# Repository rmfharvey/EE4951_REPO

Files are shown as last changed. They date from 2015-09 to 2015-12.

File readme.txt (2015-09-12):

EE4951 Repository Readme

Contact Info:

Andre Bounnakhom
boun0038@umn.edu

Ross Harvey	
harve321@umn.edu	
(515) 210-5953

Diego Martinez
mart1951@umn.edu

Alpha Mbennah
mbenn001@umn.edu

James Redinger
redi0069@umn.edu

Ryan Thompson
thom4192@umn.edu

Kia Bazargan
kia@umn.edu

Greg Nash
greg.nash@nimbelink.com

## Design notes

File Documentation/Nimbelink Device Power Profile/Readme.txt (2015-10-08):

Nimbelink Device is powered from 12V input.
A buck converter (TPS54229E) transforms the voltage from 12V to 4V at 60% to 90% efficiency.

All current shunt (voltage) measurements are given as voltages across a 0.1ohm resistor (1% tolerance) on the 4V rail.
Voltage measurements were given at the 4V rail.

These measurements were taken as the Nimbelink device was running the Skywire_Demo program in which it periodically
transmits data from the device over the internet to an online display on my laptop. I attached a text file which contains
the terminal window information from the Nimbelink device and I attached a screenshot from the online display.

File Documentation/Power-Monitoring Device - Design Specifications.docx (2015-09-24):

EE4951W Design Specifications

Objective: To develop an intelligent monitor to analyze the power consumption of a battery powered device by simultaneously measuring voltage and current supplied to the device under test (DUT). A microprocessor will obtain the analog voltage across the DUT along with its current consumption and will convert them into two streams of digital data that will be used to calculate the power consumption of the DUT. Voltage and current readings, as well as power calculations, will be logged to an onboard SD card in order to provide analysis of past measurements. The device will provide minimum, maximum, and average voltage and current readings along with power calculations that will be shown on an LCD for real-time observations.

Primary Constraints

1. Input voltage range: 3.3 – 24V

2. Maximum power consumption: 1W

3. The system should provide 5 significant figures for current measurements in the range of 10µA to 1A and voltages in the range of 3.5 to 24V

4. The device should be able to be powered parasitically from the DUT

5. The device should log data to an SD card in csv format

6. The microcontroller should have USB accessibility for debugging and performing firmware upgrades

7. The device should be able to respond to push-button commands to start or stop statistical calculations.

Secondary Constraints

1. The system should be able monitor its own power consumption by means of an additional analog circuit that will provide measurements for current and voltage that the microprocessor will use in order to provide the consumption of the system by the command of a switch

2. Output real-time data over USB

3. Microprocessor and circuitry for analog voltage and current measurements should be able to operate from a 5-Volt source, such as the terminal from a USB cable connection

4. The system should be able to withstand accidental reversed power supply connections

5. The microcontroller should enter a minimum-consumption state once inactivity reaches a determined length of time (sleep mode)

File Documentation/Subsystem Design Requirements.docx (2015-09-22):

Subsystem Design Requirements/Constraints

EE4951W

9-21-15

Power

James/Andre

1. Input Voltage Range: 0-24v
2. Output: 3–3.6v
3. Switch to USB power when available (preferably automatically)
4. Filter noise from 3.3v rail
5. Keep noise out of VBAT rail

Current Measurement

Ryan/Ross

1. Measurement range: 500nA – 5A
2. Quick enough to capture spikes (>80kS/s)
3. VBurden < 50mV
4. Accurate to 4 digits

Voltage Measurement

Alpha/Andre

1. Overvoltage protection at ADC inputs
2. Prevent loading of voltage divider
3. Resolution of 0.5%
4. Quick enough to capture spikes (>80kS/s)

SD Card

Diego/James

1. Figure out size needed
2. Preferably MicroSD
3. Figure out how and what we need to write to card and how long of a period
4. Communication protocol (preferably SPI)
5. How to write csv file to SD card
6. File system?

LCD Display

Diego/Ryan

1. Board v. chassis mount
2. Hardware driver IC
3. Communication protocol
4. What/how to display
5. Power consumption
6. Sleep mode

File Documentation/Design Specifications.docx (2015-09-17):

EE4951W Design Specifications

9-15-15

Primary Constraints

1. Input voltage range: 3.3 – 24v
2. Maximum power consumption: 1W
3. The system should feature multiple current measurement ranges.
4. The device should be able to be powered parasitically from the device-under-test. (DUT)
5. The device should log data to an SD card in csv format.
6. The microcontroller will have JTAG debug and programming capabilities
7. The device will be able to service interrupt requests triggered by a button press or an external

signal. This interrupt will start or stop statistical calculations.

Secondary Constraints

1. The system should monitor the power consumption of itself.
2. Output real-time data over USB.
3. Allow for system to be powered from USB.
4. The system should be protected against reverse voltages.
5. The microcontroller should go to sleep while idle to minimize power consumption.

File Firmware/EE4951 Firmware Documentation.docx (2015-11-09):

EE4951 Firmware Documentation

Ross Harvey

11-7-2015

1. Communications Busses

SPI0

- SD Card
- 10MHz

SPI1

- OLED Display
- 2MHz

UART1

- USB interface (FT232RQ)
- Baudrate: 115200 bps
- Width: 8-bit
- Parity: None

2. Start-up Options

Four GPI bits (OPT<3:0>) are included to run the device in different modes. These four bits will only be read immediately after the MCU is reset or powered on.

OPT<3:0> | Mode | Description
0000 | Normal | -
0001 | USB Output | Normal mode with unidirectional USB
0010 | Hardware Debug | Normal mode with bidirectional USB
0011
0100
0101
0110
0111
1000
1001
1010
1011
1100
1101
1110
1111

Table 1: OPT<3:0> assignments

3. USB-UART Communication (Unidirectional)

During normal operation, if USB unidirectional mode is enabled with the OPT bits, the MCU will output ADC readings and current status data asynchronously. It will be necessary for the Python script to read these packets from the USB buffer and parse them to obtain readings. The packet structure is given below.

TYPE<7:0> | Data Type | VALUE<15:0>
0x00 | DUT Voltage | 16-bit raw values. See scaling factors
0x01 | DUT Current
0x02 | Self 3.3v Voltage
0x03 | Self 3.3v Current
0x04 | Self 5v Voltage
0x05 | Self 5v Current
0x06 | Status Register | See fig xxxxxxx
0x07 | DUT Current Average
0x08 | DUT Voltage Average
0x09 | Stats Period | Elapsed time for stats (in seconds)

3.1 DUT Voltage

TYPE<7:0> = 0x00

VALUE<15:0> = Unsigned 16-bit value (Scaled)

To recover VBAT, use V_(BAT) =VALUE(V_(REF))/(2^16)(1+(R_22)/(R_24))=(VALUE)/2621.44 (REV A)

RNG<1:0> = not used

3.2 DUT Current

TYPE<7:0> = 0x01

VALUE<15:0> = Unsigned 16-bit value (Scaled)

To recover IDUT, use I_(DUT) =VALUE(V_(REF))/(2^16)1/(A_V •R_(Sense))=VALUE•SCALE (REV A)

RNG<1:0> = Determines which range is currently active. Affects

scaling factor and IDUT recovery.

RNG<1:0> | Range | SCALE
00 | DUT_RANGE0 | 1.831055x10⁻⁴
01 | DUT_RANGE1 | 1.831055x10⁻⁶
10 | DUT_RANGE2 | 1.831055x10⁻⁸
11 | DUT_RANGE3 | 1.831055x10⁻⁹

3.3 Self 3.3v Voltage

TYPE<7:0> = 0x02

VALUE<15:0> = Unsigned 16-bit value (Scaled)

To recover V3.3v, use V_(3.3v) =VALUE(V_(REF))/(2^16)(1+(R_72)/(R_74))=(VALUE)/9709.037 (REV A)

RNG<1:0> = not used

3.4 Self 3.3v Current

TYPE<7:0> = 0x03

VALUE<15:0> = Unsigned 16-bit value (Scaled)

To recover I3.3v, use I_(3.3v) =VALUE(V_(REF))/(2^16)1/(A_V •R_(Sense))=(VALUE)/15073.28 (REV A)

RNG<1:0> = not used

3.5 Self 5v Voltage

TYPE<7:0> = 0x04

VALUE<15:0> = Unsigned 16-bit value (Scaled)

To recover V5v, use V_(5v) =VALUE(V_(REF))/(2^16)(1+(R_48)/(R_44))=(VALUE)/9709.037 (REV A)

RNG<1:0> = not used

3.5 Self 5v Current

TYPE<7:0> = 0x05

VALUE<15:0> = Unsigned 16-bit value (Scaled)

To recover I5v, use I_(5v) =VALUE(V_(REF))/(2^16)1/(A_V •R_(Sense))= (VALUE)/15073.28 (REV A)

RNG<1:0> = not used

3.5 Status Register

TYPE<7:0> = 0x06

VALUE<15:0>

Bits | Function | Notes
VALUE<15:12> | OPT<3:0> | Startup Options
VALUE<11:10> | DUT Current Range | Range 0-3
VALUE<9> | POWER_FAIL_IRQ | Power OK (Active High)
VALUE<8> | STATS_IRQ | Stats Start/END Button(Active Low)
VALUE<7> | SD_DETECT | SD Card Present(Active Low)
VALUE<6> | SD_CS | SD Chip Select (Active Low)
VALUE<5> | DISP_RES | Display Reset (Active Low)
VALUE<4> | DISP_CS | Display Chip Select (Active Low)
VALUE<3> | DISP_DC | Display Data/Command (Data High)
VALUE<2> | Stats Running | High if collecting stats data
VALUE<1:0> | not used | not used

3.6 DUT Current Average

May be implemented later. More to come…

3.6 DUT Voltage Average

May be implemented later. More to come…

3.6 Stats Period

May be implemented later. More to come…

4. USB-UART Communication (Bidirectional)

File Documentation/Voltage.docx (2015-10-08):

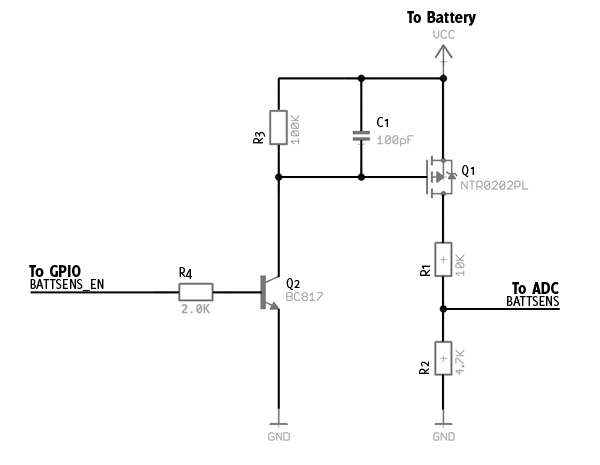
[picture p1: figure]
User Controllable Voltage Divider Circuit

Pros:
Helps preserve battery life (Control of voltage divider)
Relatively good price
Cons:
Potentially not needing GPIO

http://www.microbuilder.eu/Tutorials/Fundamentals/MeasuringBatteryVoltage.aspx

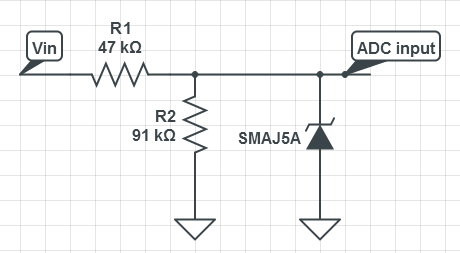
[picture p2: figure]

Instead of Zener diode, use Vishay QSBT40 TVS Diode Array(24V outputs)
Resistors for scaling, voltage protection, linear regulator

*Shunt cap for non-voltage divider
*Linear reg/variable reg: current rush, power to stop it
*R1=98.8k, R2=26k
*Zener Diode
*P=0.0279W

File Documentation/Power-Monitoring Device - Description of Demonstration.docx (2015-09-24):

EE4951W – Battery Power Monitor

Demonstration Description

A system comprised of a laptop, cellular modem, and a load-box will be used to demonstrate the functionality of the battery power monitor (BPM). The BPM will monitor the voltage and current of the cellular modem during transmission and log all data to an on-board SD card. In addition to data logging, minimum, maximum, and average values of the power consumption will be displayed on an attached LCD display. These statistical calculations can be reset via a push-button. Real-time sensor data will be sent over USB to the laptop and displayed on screen. In addition to monitoring the cellular modem, the general nature of the BPM will be demonstrated by using a load box to simulate a variety of loads.

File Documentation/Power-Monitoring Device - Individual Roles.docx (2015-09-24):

EE4951W – Power-Monitoring Device

Individual Roles

Power Supply: James

Voltage Measurement: Alpha

Current Measurement: Ryan

LCD: Diego

PCB Layout and Schematic Capture: Ross

Firmware: Ross and Diego

Self-Power Monitor: Andre

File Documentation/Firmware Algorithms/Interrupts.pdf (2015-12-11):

12/10/2015 | draw.io

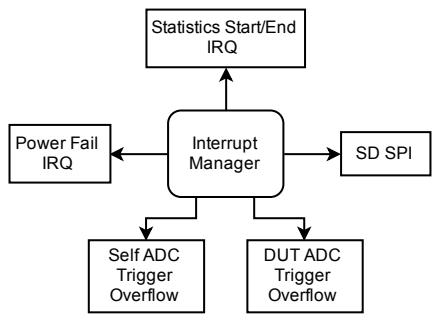
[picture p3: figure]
Interrupt Manager; DUT ADC Trigger Overflow; Statistics Start/End IRQ; Power Fail IRQ; SD SPI; Self ADC Trigger Overflow

chromeextension://pebppomjfocnoigkeepgbmcifnnlndla/index.html | 1/1

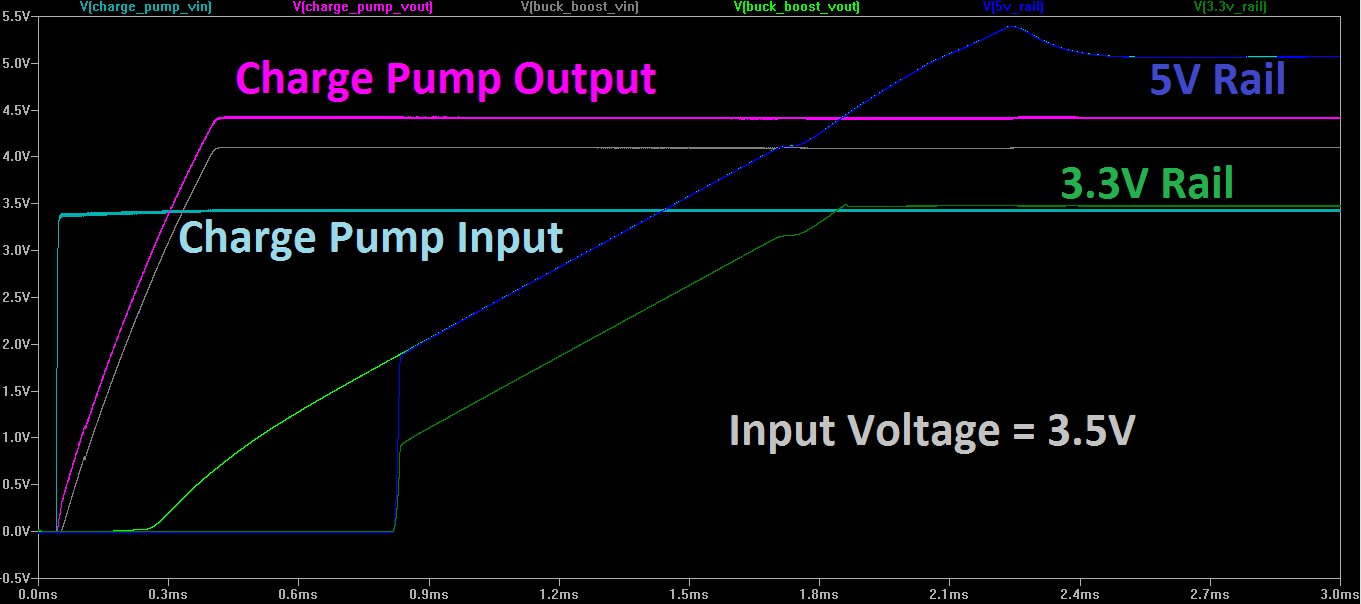
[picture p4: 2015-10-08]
Simulation/Power Subsystem/Buck_Boost Design/3.5V Input Power Subsystem 3ms.PNG

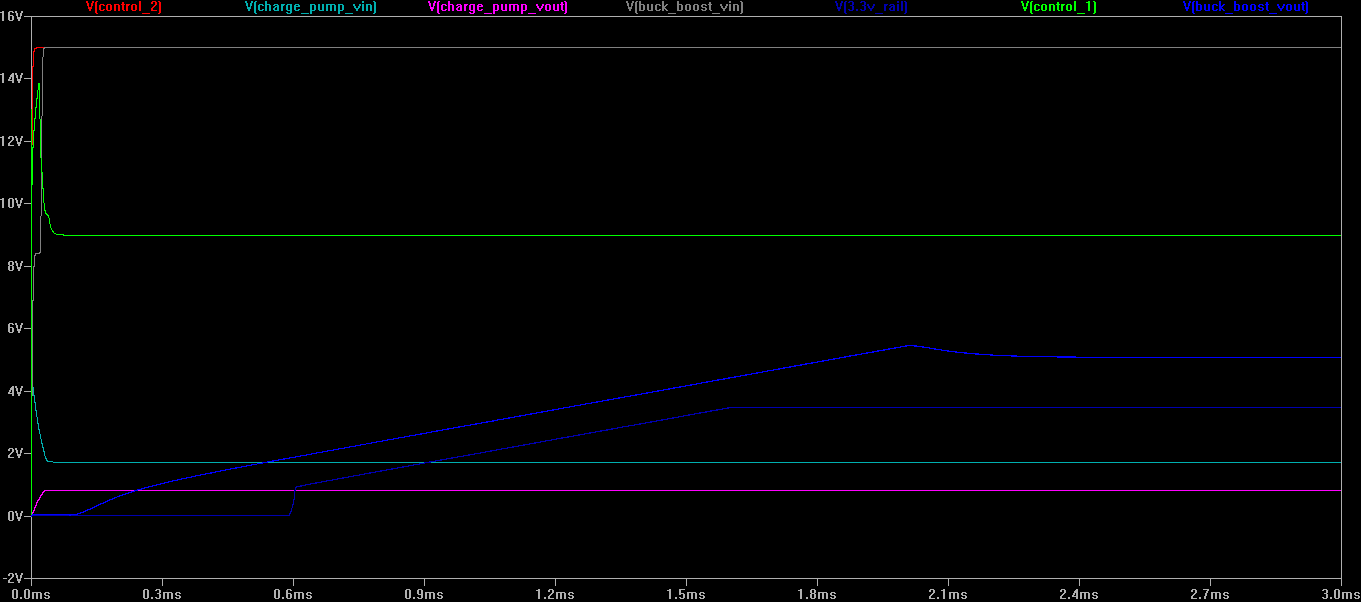
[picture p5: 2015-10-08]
Simulation/Power Subsystem/Buck_Boost Design/12V Input Power Subsystem 3ms 2.PNG

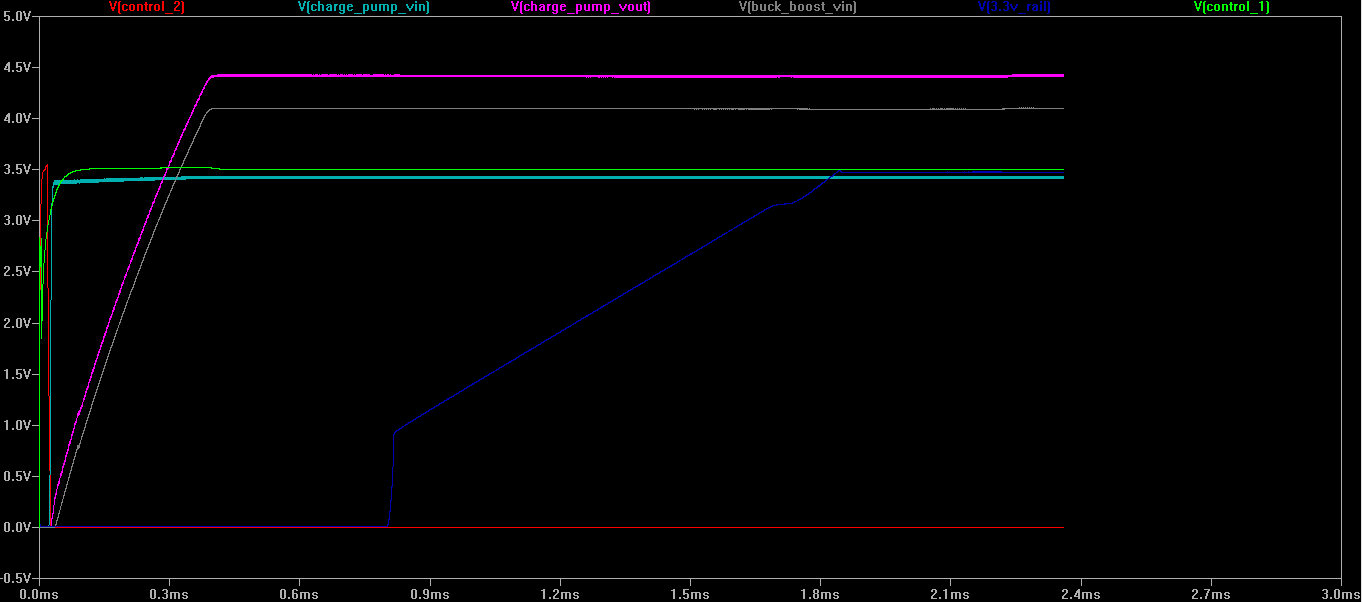
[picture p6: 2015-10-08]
Simulation/Power Subsystem/Buck_Boost Design/3.5V Input Power Subsystem 3ms 2.PNG

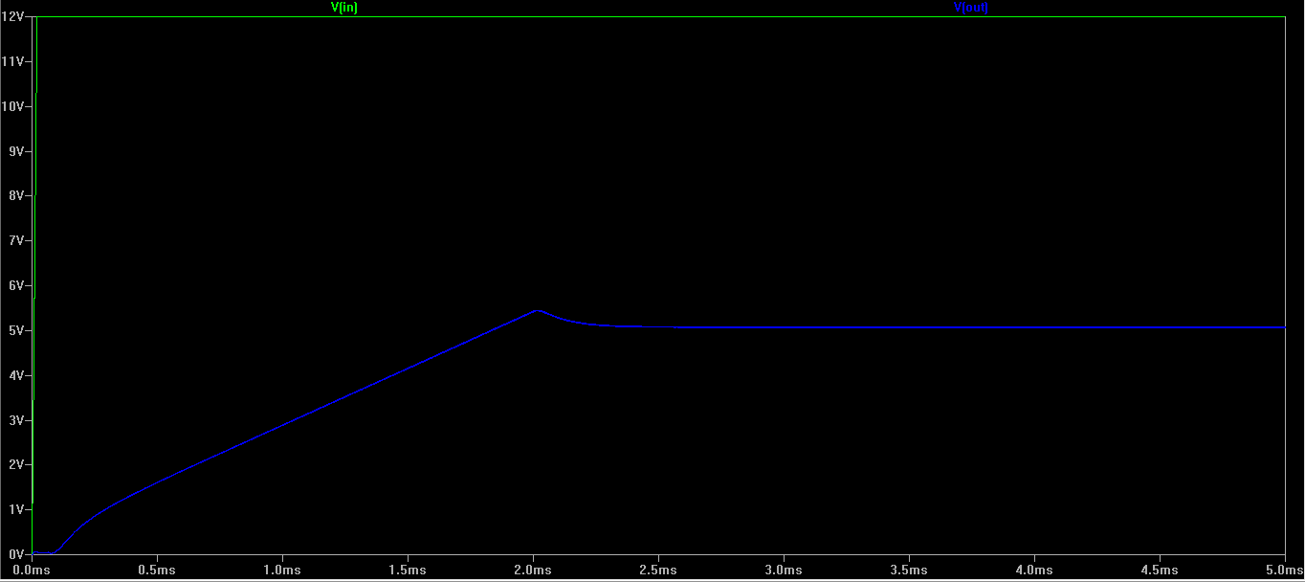
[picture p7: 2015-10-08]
Simulation/Power Subsystem/Buck_Boost Design/12V Input LTC3111.PNG

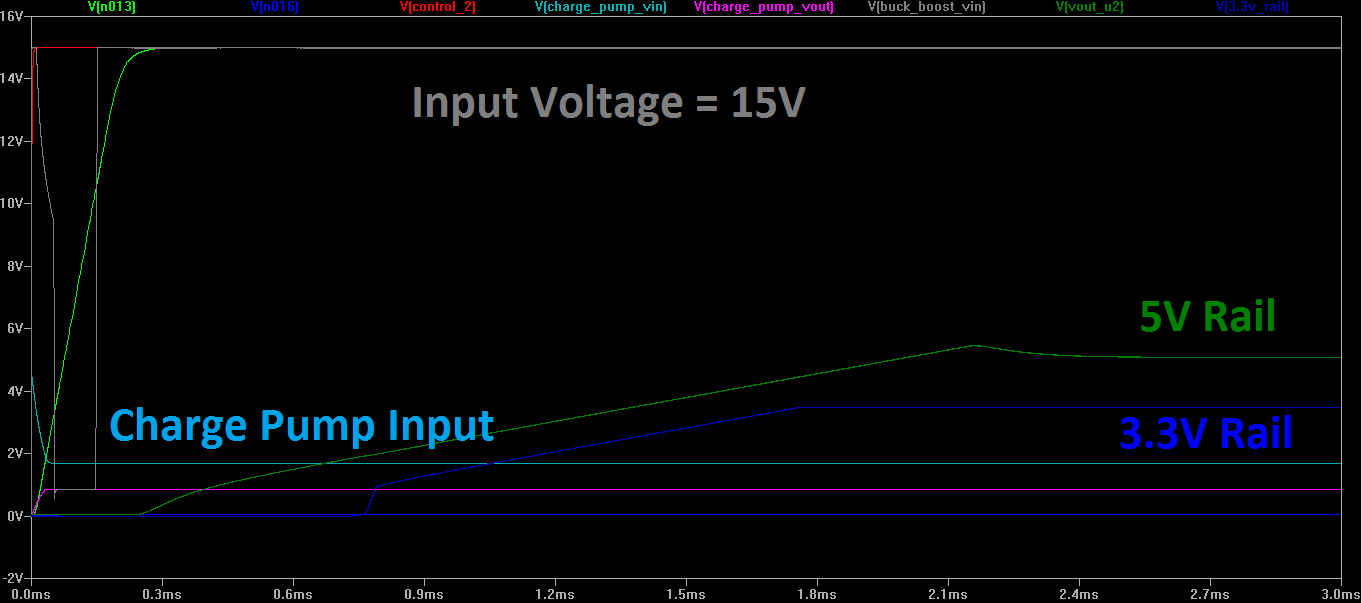
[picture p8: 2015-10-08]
Simulation/Power Subsystem/Buck_Boost Design/12V Input Power Subsystem 3ms.PNG

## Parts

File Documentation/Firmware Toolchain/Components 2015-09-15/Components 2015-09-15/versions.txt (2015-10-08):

Part 1 of 2:
Package from component(s):
- 24AA_EEPROM version 01.032
- 74HC164 version 01.031
- 74HC595 version 01.022
- App_SMAC_Hello version 01.085
- AT25HP512 version 01.038
- BitIO_to_PCA9554 version 01.018
- Bluetooth_EGBT version 01.051
- BootLoaderDisk version 01.018
- BootLoaderUSB version 01.020
- ChLCD version 01.164
- CriticalSection version 01.006
- CTouchScanner version 01.021
- CTouchSensor version 01.032
- DCF77 version 01.060
- DS18B20 version 01.001
- FAT_FileSystem version 01.168
- FatFsMem_USB_MSD version 01.024
- FatFsMemSDHC version 01.037
- FontDisplay version 01.195
- FreeRTOS version 01.435
- FreeRTOS_Tasks version 01.008
- FreeRTOSTrace version 01.003
- FSL_USB_CDC_Device version 01.050
- FSL_USB_CDC_Host version 01.005
- FSL_USB_HID_Keyboard_Device version 01.061
- FSL_USB_HID_Mouse_Device version 01.076
- FSL_USB_MSD_Host version 01.024
- FSL_USB_Stack version 01.036
- FXOS8700CQ version 01.028
- GDisplay version 01.190
- GenericBitIO version 01.065
- GenericI2C version 01.023
- GenericKBI version 01.025
- GenericSPI version 01.029
- GenericSWI2C version 01.007
- GenericSWSPI version 01.024
- GenericTimeDate version 01.027
- GFont version 01.123
- HardFault version 01.008
- I2CSpy version 01.009
- KentChLCD version 01.111
- Key version 01.109
- KinetisSDK version 01.001
- KinetisTools version 01.025
- LCDHTA version 01.022
- LED version 01.065
- LEDbit version 01.003
- LEDbyte version 01.038
- LEDmatrix version 01.095
- LEDReverseBias version 01.134
- LEDSensor version 01.130
- LightComm version 01.126
- LM61B version 01.030
- LowPower version 01.016
- MAG3110 version 01.010
- MaxonF2140 version 01.001
- MC34673 version 01.019
- minIni version 01.038
- MMA7260Q version 01.111
- MMA7455L version 01.043
- MMA8451Q version 01.036
- MPR08x version 01.205
- MPVZ5004 version 01.021
created 15.09.2015

Part 2 of 2:
Package from component(s):
- nRF24L01 version 01.086
- OLED version 01.045
- OneWire version 01.067
- PCA9554 version 01.028
- PCA9554BitIO version 01.037
- PDC8544 version 01.003
- PercepioTrace version 01.048
- PID_Float version 01.005
- PID_Int version 01.001
- PtConv version 01.005
- PWMServo16bit version 01.011
- QuadCounter version 01.026
- RingBuffer version 01.039
- RNet version 01.083
- RTC_Maxim version 01.010
- S19 version 01.034
- S65Sharp version 01.082
- SD_Card version 01.178
- Servo version 01.066
- Shell version 01.073
- SimpleEvents version 01.050
- SMAC version 01.009
- SPHY version 01.108
- SPIHCS08 version 01.025
- SSD1289 version 01.158
- SSEC version 01.067
- Tacho version 01.002
- Timeout version 01.030
- TouchScreen version 01.077
- TouchScreenSensor version 01.053
- Trigger version 01.061
- uCOS_II version 01.189
- UI version 01.056
- UIButton version 01.121
- UICalendar version 01.030
- UICheckBox version 01.109
- UIDialogWindow version 01.015
- UIGraph version 01.054
- UIHeader version 01.062
- UIIcon version 01.052
- UIScreen version 01.014
- UIScrollMenu version 01.033
- UISlider version 01.042
- UISpace version 01.012
- UIText version 01.059
- UIWindow version 01.033
- USB_CMX version 01.027
- USB_Config_CMX version 01.022
- USB_HID_CMX version 01.012
- USB_Host_CMX version 01.058
- UserInterface version 01.510
- UTI version 01.125
- Utility version 01.111
- VS1053 version 01.004
- Wait version 01.067
- XFormat version 01.014
created 15.09.2015

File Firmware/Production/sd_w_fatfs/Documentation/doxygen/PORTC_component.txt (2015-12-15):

/*!
  \page PORTC PORTC (Init_PORT)
**          This file implements the PORT (PORTC) module initialization
**          according to the Peripheral Initialization settings, and
**          defines interrupt service routines prototypes.
**

- \subpage PORTC_settings
- \subpage PORTC_regs_overview  
- \subpage PORTC_regs_details
- \ref PORTC_module "Component documentation" 
\page PORTC_regs_overview Registers Initialization Overview
This page contains the initialization values for the registers of the peripheral(s) configured
by the component. 
<table>
<tr><td colspan="4" class="ttitle1">PORTC Initialization</td></tr>
<tr><td class="ttitle2">Address</td><td class="ttitle2">Register</td><td class="ttitle2">Register Value</td><td class="ttitle2">Register Description</td></tr>
<tr><td>0x4004B048</td><td>PORTC_PCR18</td>
<td class="regNotResetVal">0x01000103</td>
 <td>PORTC_PCR18 register, peripheral PORTC.</td></tr>
</table>
Color Denotes Reset Value
<br/>
\page PORTC_regs_details Register Initialization Details
This page contains detailed description of initialization values for the 
registers of the peripheral(s) configured by the component. 

<div class="reghdr1">PORTC_PCR18</div>
<div class="regdiag">
<table class="regtbl">
<tr class="trd1r">
<td class="trd1c">Bit</td><td>31</td><td>30</td><td>29</td><td>28</td><td>27</td><td>26</td><td>25</td><td>24</td><td>23</td>
<td>22</td><td>21</td><td>20</td><td>19</td><td>18</td><td>17</td><td>16</td>
</tr>
<tr>
<td class="trd1c">R</td><td colspan="1" rowspan="2">-</td><td colspan="1" rowspan="2">-</td><td colspan="1" rowspan="2">-</td>
<td colspan="1" rowspan="2">-</td><td colspan="1" rowspan="2">-</td><td colspan="1" rowspan="2">-</td>
<td colspan="1" rowspan="2">-</td><td colspan="1" rowspan="2">ISF</td><td colspan="1" rowspan="2">-</td>
<td colspan="1" rowspan="2">-</td><td colspan="1" rowspan="2">-</td><td colspan="1" rowspan="2">-</td>
<td colspan="4" rowspan="2">IRQC</td>
</tr>
<tr>
<td class="trd1c">W</td>
</tr>
<tr class="trd1r">
<td class="trd1c">Reset</td><td>0</td><td>0</td><td>0</td><td>0</td><td>0</td><td>0</td><td>0</td><td>0</td><td>0</td><td>0</td>
<td>0</td><td>0</td><td>0</td><td>0</td><td>0</td><td>0</td>
</tr>
</table>
<table class="regtbl">
<tr class="trd1r">
<td class="trd1c">Bit</td><td>15</td><td>14</td><td>13</td><td>12</td><td>11</td><td>10</td><td>9</td><td>8</td><td>7</td>
<td>6</td><td>5</td><td>4</td><td>3</td><td>2</td><td>1</td><td>0</td>
</tr>
<tr>
<td class="trd1c">R</td><td colspan="1" rowspan="2">LK</td><td colspan="1" rowspan="2">-</td><td colspan="1" rowspan="2">-</td>
<td colspan="1" rowspan="2">-</td><td colspan="1" rowspan="2">-</td><td colspan="3" rowspan="2">MUX</td>
<td colspan="1" rowspan="2">-</td><td colspan="1" rowspan="2">DSE</td><td colspan="1" rowspan="2">ODE</td>
<td colspan="1" rowspan="2">PFE</td><td colspan="1" rowspan="2">-</td><td colspan="1" rowspan="2">SRE</td>
<td colspan="1" rowspan="2">PE</td><td colspan="1" rowspan="2">PS</td>
</tr>
<tr>
<td class="trd1c">W</td>
</tr>
<tr class="trd1r">
<td class="trd1c">Reset</td><td>0</td><td>0</td><td>0</td><td>0</td><td>0</td><td>0</td><td>0</td><td>0</td><td>0</td><td>0</td>
<td>0</td><td>0</td><td>0</td><td>0</td><td>0</td><td>0</td>
</tr>
</table>
        
</div>
<table class="regtbl2"><tr><td class="trowtit" colspan="2">Address</td><td colspan="2">0x4004B048</td></tr>
<tr class="trowtit"><td  class="trowtit" colspan="2">Initial value</td><td colspan="2">0x01000103</td></tr>
<tr class="trowtit"><td  class="trowtit" colspan="2">After-reset value</td><td colspan="2">0x00000000</td></tr>
<tr><td class="ttitle2">Bit</td><td class="ttitle2">Field</td><td class="ttitle2">Value</td><td class="ttitle2">Description</td></tr>
<tr><td>24</td><td>ISF</td><td>0x01</td><td>Interrupt Status Flag</td>
<tr><td>16 - 19</td><td>IRQC</td><td>0x00</td><td>Interrupt Configuration</td>
<tr><td>15</td><td>LK</td><td>0x00</td><td>Lock Register</td>
<tr><td>8 - 10</td><td>MUX</td><td>0x00</td><td>Pin Mux Control</td>
<tr><td>6</td><td>DSE</td><td>0x00</td><td>Drive Strength Enable</td>
<tr><td>5</td><td>ODE</td><td>0x00</td><td>Open Drain Enable</td>
<tr><td>4</td><td>PFE</td><td>0x00</td><td>Passive Filter Enable</td>
<tr><td>2</td><td>SRE</td><td>0x00</td><td>Slew Rate Enable</td>
<tr><td>1</td><td>PE</td><td>0x01</td><td>Pull Enable</td>
<tr><td>0</td><td>PS</td><td>0x01</td><td>Pull Select</td>
</tr></table>
*/
/*!
\page PORTC_settings Component Settings
\code
**          Component name                                 : PORTC
**          Device                                         : PORTC
**          Settings                                       : 
**            Clock gate                                   : Enabled
**            Pin 0                                        : Do not initialize
**            Pin 1                                        : Do not initialize
**            Pin 2                                        : Do not initialize
**            Pin 3                                        : Do not initialize
**            Pin 4                                        : Do not initialize
**            Pin 5                                        : Do not initialize
**            Pin 6                                        : Do not initialize
**            Pin 7                                        : Do not initialize
**            Pin 8                                        : Do not initialize
**            Pin 9                                        : Do not initialize
**            Pin 10                                       : Do not initialize
**            Pin 11                                       : Do not initialize
**            Pin 12                                       : Do not initialize
**            Pin 13                                       : Do not initialize
**            Pin 14                                       : Do not initialize
**            Pin 15                                       : Do not initialize
**            Pin 16                                       : Do not initialize
**            Pin 17                                       : Do not initialize
**            Pin 18                                       : Initialize
**              Mux control                                : PTC18
**              Open drain                                 : <Automatic>
**              Pull resistor                              : Enabled
**              Pull selection                             : Pull Up
**              Slew rate                                  : Fast
**              Drive strength                             : Low
**              Interrupt/DMA request                      : <Automatic>
**              Passive filter                             : <Automatic>
**              Lock                                       : <Automatic>
**          Interrupts                                     : 
**            Port interrupt                               : Enabled
**              Interrupt                                  : INT_PORTC
**              Interrupt request                          : <Automatic>
**              Interrupt priority                         : <Automatic>
**              ISR Name                                   : 
**          Initialization                                 : 
**            Call Init method                             : yes
**            Utilize after reset values                   : default
<h1>
\endcode
*/

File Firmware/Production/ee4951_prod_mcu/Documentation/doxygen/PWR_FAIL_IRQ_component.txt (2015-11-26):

/*!
  \page PWR_FAIL_IRQ PWR_FAIL_IRQ (Init_GPIO)
**          This file implements the GPIO (PTA) module initialization
**          according to the Peripheral Initialization settings, and
**          defines interrupt service routines prototypes.
**

- \subpage PWR_FAIL_IRQ_settings
- \subpage PWR_FAIL_IRQ_regs_overview  
- \subpage PWR_FAIL_IRQ_regs_details
- \ref PWR_FAIL_IRQ_module "Component documentation" 
\page PWR_FAIL_IRQ_regs_overview Registers Initialization Overview
This page contains the initialization values for the registers of the peripheral(s) configured
by the component. 
<table>
<tr><td colspan="4" class="ttitle1">PWR_FAIL_IRQ Initialization</td></tr>
<tr><td class="ttitle2">Address</td><td class="ttitle2">Register</td><td class="ttitle2">Register Value</td><td class="ttitle2">Register Description</td></tr>
<tr><td>0x400FF004</td><td>GPIOA_PSOR</td>
<td class="regResetVal">0x00000000</td>
 <td>GPIOA_PSOR register, peripheral PWR_FAIL_IRQ.</td></tr>
<tr><td>0x400FF008</td><td>GPIOA_PCOR</td>
<td class="regNotResetVal">0x00000020</td>
 <td>GPIOA_PCOR register, peripheral PWR_FAIL_IRQ.</td></tr>
<tr><td>0x400FF014</td><td>GPIOA_PDDR</td>
<td class="regResetVal">0x00000000</td>
 <td>GPIOA_PDDR register, peripheral PWR_FAIL_IRQ.</td></tr>
</table>
Color Denotes Reset Value
<br/>
\page PWR_FAIL_IRQ_regs_details Register Initialization Details
This page contains detailed description of initialization values for the 
registers of the peripheral(s) configured by the component. 

<div class="reghdr1">GPIOA_PSOR</div>
<div class="regdiag">
<table class="regtbl">
<tr class="trd1r">
<td class="trd1c">Bit</td><td>31</td><td>30</td><td>29</td><td>28</td><td>27</td><td>26</td><td>25</td><td>24</td><td>23</td>
<td>22</td><td>21</td><td>20</td><td>19</td><td>18</td><td>17</td><td>16</td>
</tr>
<tr>
<td class="trd1c">R</td><td colspan="16"></td>
</tr>
<tr>
<td class="trd1c">W</td>
<td colspan="16">PTSO</td>
</tr>
<tr class="trd1r">
<td class="trd1c">Reset</td><td>0</td><td>0</td><td>0</td><td>0</td><td>0</td><td>0</td><td>0</td><td>0</td><td>0</td><td>0</td>
<td>0</td><td>0</td><td>0</td><td>0</td><td>0</td><td>0</td>
</tr>
</table>
<table class="regtbl">
<tr class="trd1r">
<td class="trd1c">Bit</td><td>15</td><td>14</td><td>13</td><td>12</td><td>11</td><td>10</td><td>9</td><td>8</td><td>7</td>
<td>6</td><td>5</td><td>4</td><td>3</td><td>2</td><td>1</td><td>0</td>
</tr>
<tr>
<td class="trd1c">R</td><td colspan="32"></td>
</tr>
<tr>
<td class="trd1c">W</td>
<td colspan="32">PTSO</td>
</tr>
<tr class="trd1r">
<td class="trd1c">Reset</td><td>0</td><td>0</td><td>0</td><td>0</td><td>0</td><td>0</td><td>0</td><td>0</td><td>0</td><td>0</td>
<td>0</td><td>0</td><td>0</td><td>0</td><td>0</td><td>0</td>
</tr>
</table>
        
</div>
<table class="regtbl2"><tr><td class="trowtit" colspan="2">Address</td><td colspan="2">0x400FF004</td></tr>
<tr class="trowtit"><td  class="trowtit" colspan="2">Initial value</td><td colspan="2">0x00000000</td></tr>
<tr class="trowtit"><td  class="trowtit" colspan="2">After-reset value</td><td colspan="2">0x00000000</td></tr>
<tr><td class="ttitle2">Bit</td><td class="ttitle2">Field</td><td class="ttitle2">Value</td><td class="ttitle2">Description</td></tr>
<tr><td>0 - 31</td><td>PTSO</td><td>0x00</td><td>Port Set Output</td>
</tr></table>
<div class="reghdr1">GPIOA_PCOR</div>
<div class="regdiag">
<table class="regtbl">
<tr class="trd1r">
<td class="trd1c">Bit</td><td>31</td><td>30</td><td>29</td><td>28</td><td>27</td><td>26</td><td>25</td><td>24</td><td>23</td>
<td>22</td><td>21</td><td>20</td><td>19</td><td>18</td><td>17</td><td>16</td>
</tr>
<tr>
<td class="trd1c">R</td><td colspan="16"></td>
</tr>
<tr>
<td class="trd1c">W</td>
<td colspan="16">PTCO</td>
</tr>
<tr class="trd1r">
<td class="trd1c">Reset</td><td>0</td><td>0</td><td>0</td><td>0</td><td>0</td><td>0</td><td>0</td><td>0</td><td>0</td><td>0</td>
<td>0</td><td>0</td><td>0</td><td>0</td><td>0</td><td>0</td>
</tr>
</table>
<table class="regtbl">
<tr class="trd1r">
<td class="trd1c">Bit</td><td>15</td><td>14</td><td>13</td><td>12</td><td>11</td><td>10</td><td>9</td><td>8</td><td>7</td>
<td>6</td><td>5</td><td>4</td><td>3</td><td>2</td><td>1</td><td>0</td>
</tr>
<tr>
<td class="trd1c">R</td><td colspan="32"></td>
</tr>
<tr>
<td class="trd1c">W</td>
<td colspan="32">PTCO</td>
</tr>
<tr class="trd1r">
<td class="trd1c">Reset</td><td>0</td><td>0</td><td>0</td><td>0</td><td>0</td><td>0</td><td>0</td><td>0</td><td>0</td><td>0</td>
<td>0</td><td>0</td><td>0</td><td>0</td><td>0</td><td>0</td>
</tr>
</table>
        
</div>
<table class="regtbl2"><tr><td class="trowtit" colspan="2">Address</td><td colspan="2">0x400FF008</td></tr>
<tr class="trowtit"><td  class="trowtit" colspan="2">Initial value</td><td colspan="2">0x00000020</td></tr>
<tr class="trowtit"><td  class="trowtit" colspan="2">After-reset value</td><td colspan="2">0x00000000</td></tr>
<tr><td class="ttitle2">Bit</td><td class="ttitle2">Field</td><td class="ttitle2">Value</td><td class="ttitle2">Description</td></tr>
<tr><td>0 - 31</td><td>PTCO</td><td>0x00</td><td>Port Clear Output</td>
</tr></table>
<div class="reghdr1">GPIOA_PDDR</div>
<div class="regdiag">
<table class="regtbl">
<tr class="trd1r">
<td class="trd1c">Bit</td><td>31</td><td>30</td><td>29</td><td>28</td><td>27</td><td>26</td><td>25</td><td>24</td><td>23</td>
<td>22</td><td>21</td><td>20</td><td>19</td><td>18</td><td>17</td><td>16</td>
</tr>
<tr>
<td class="trd1c">R</td><td colspan="16" rowspan="2">PDD</td>
</tr>
<tr>
<td class="trd1c">W</td>
</tr>
<tr class="trd1r">
<td class="trd1c">Reset</td><td>0</td><td>0</td><td>0</td><td>0</td><td>0</td><td>0</td><td>0</td><td>0</td><td>0</td><td>0</td>
<td>0</td><td>0</td><td>0</td><td>0</td><td>0</td><td>0</td>
</tr>
</table>
<table class="regtbl">
<tr class="trd1r">
<td class="trd1c">Bit</td><td>15</td><td>14</td><td>13</td><td>12</td><td>11</td><td>10</td><td>9</td><td>8</td><td>7</td>
<td>6</td><td>5</td><td>4</td><td>3</td><td>2</td><td>1</td><td>0</td>
</tr>
<tr>
<td class="trd1c">R</td><td colspan="32" rowspan="2">PDD</td>
</tr>
<tr>
<td class="trd1c">W</td>
</tr>
<tr class="trd1r">
<td class="trd1c">Reset</td><td>0</td><td>0</td><td>0</td><td>0</td><td>0</td><td>0</td><td>0</td><td>0</td><td>0</td><td>0</td>
<td>0</td><td>0</td><td>0</td><td>0</td><td>0</td><td>0</td>
</tr>
</table>
        
</div>
<table class="regtbl2"><tr><td class="trowtit" colspan="2">Address</td><td colspan="2">0x400FF014</td></tr>
<tr class="trowtit"><td  class="trowtit" colspan="2">Initial value</td><td colspan="2">0x00000000</td></tr>
<tr class="trowtit"><td  class="trowtit" colspan="2">After-reset value</td><td colspan="2">0x00000000</td></tr>
<tr><td class="ttitle2">Bit</td><td class="ttitle2">Field</td><td class="ttitle2">Value</td><td class="ttitle2">Description</td></tr>
<tr><td>0 - 31</td><td>PDD</td><td>0x00</td><td>Port Data Direction</td>
</tr></table>
*/
/*!
\page PWR_FAIL_IRQ_settings Component Settings
\code
**          Component name                                 : PWR_FAIL_IRQ
**          Device                                         : PTA
**          Settings                                       : 
**            Clock gate                                   : Enabled
**            Pin 0                                        : Do not initialize
**            Pin 1                                        : Do not initialize
**            Pin 2                                        : Do not initialize
**            Pin 3                                        : Do not initialize
**            Pin 4                                        : Do not initialize
**            Pin 5                                        : Initialize
**              Pin direction                              : Input
**              Output value                               : 0
**              Open drain                                 : <Automatic>
**              Pull resistor                              : Enabled
**              Pull selection                             : <Automatic>
**              Slew rate                                  : <Automatic>
**              Drive strength                             : <Automatic>
**              Interrupt/DMA request                      : Interrupt on falling
**              Passive filter                             : <Automatic>
**              Lock                                       : <Automatic>
**            Pin 12                                       : Do not initialize
**            Pin 13                                       : Do not initialize
**            Pin 14                                       : Do not initialize
**            Pin 15                                       : Do not initialize
**            Pin 16                                       : Do not initialize
**            Pin 17                                       : Do not initialize
**            Pin 18                                       : Do not initialize
**            Pin 19                                       : Do not initialize
**          Pin selection/routing                          : 
**            Pin 0                                        : Disabled
**            Pin 1                                        : Disabled
**            Pin 2                                        : Disabled
**            Pin 3                                        : Disabled
**            Pin 4                                        : Disabled
**            Pin 5                                        : Enabled
**              Pin                                        : PTA5/USB_CLKIN/FTM0_CH2/I2S0_TX_BCLK/JTAG_TRST_b
**            Pin 12                                       : Disabled
**            Pin 13                                       : Disabled
**            Pin 14                                       : Disabled
**            Pin 15                                       : Disabled
**            Pin 16                                       : Disabled
**            Pin 17                                       : Disabled
**            Pin 18                                       : Disabled
**            Pin 19                                       : Disabled
**          Interrupts                                     : 
**            Port interrupt                               : Enabled
**              Interrupt                                  : INT_PORTA
**              Interrupt request                          : Enabled
**              Interrupt priority                         : 0
**              ISR Name                                   : PORTA_IRQHandler
**          Initialization                                 : 
**            Call Init method                             : yes
**            Utilize after reset values                   : default
<h1>
\endcode
*/

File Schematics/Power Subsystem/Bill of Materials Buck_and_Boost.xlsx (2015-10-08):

Component | Manufacturer Part Number | Footprint | Price/Part | Quantity | Cost | Quantity Available | Datasheet
Boost Converter System
Switching Regulator (Boost) | TPS61032 | 6.5mm x 4.4mm | $4.28 | 1 | $4.28 | 14720 | http://www.ti.com/product/TPIC74100-Q1/datasheet
L1 = 6.8uH | SRP6540-6R8M | 7.2mm x 6.5mm | $1.18 | 1 | $1.18 | 1882 | http://www.digikey.com/product-detail/en/SRP6540-6R8M/SRP6540-6R8MCT-ND/3986039
Cin1 = 10uF | C2012X5R1A106K125AB |  | $0.20 | 1 | $0.20
Cin2 = 0.1uF | C1005X5R1E104K050BC |  | $0.10 | 1 | $0.10
C2 = 2.2uF | C1608X7R1A225K080AC |  | $0.25 | 1 | $0.25
C3 = 2 x 100uF | C3216X5R1A107M160AC |  | $1.65 | 2 | $3.30
R1 = 390k (1% accuracy) | CRCW0402390KFKED |  | $0.08 | 1 | $0.08
R2 = 150k (1% accuracy) | CRCW0402150KFKED |  | $0.08 | 1 | $0.08
R6 = 1M (1% accuracy) | CRCW04021M00FKED |  | $0.08 | 1 | $0.08
Buck Converter System
Switching Regulator (Buck) | TPS54331 | 5.0mm x 6.0mm | $2.07 | 1 | $2.07 | 1623 | http://www.digikey.com/product-detail/en/TPS54331D/296-23626-5-ND/1913497
D1 = (30Vbd, 3A, 0.45Von) | MBRA340T3G | 2.6mm x 5.2mm | $0.49 | 1 | $0.49 | 38995 | http://www.digikey.com/product-detail/en/MBRA340T3G/MBRA340T3GOSCT-ND/917975
Lout = 6.8uH | SRP6540-6R8M | 7.2mm x 6.5mm | $1.18 | 1 | $1.18 | 1882 | http://www.digikey.com/product-detail/en/SRP6540-6R8M/SRP6540-6R8MCT-ND/3986039
Cboot = 0.1uF (datasheet says X5R or X7R) | C1005X5R1E104K050BC |  | $0.10 | 1 | $0.10
Css = 2.7nF | CGA3E2C0G1H272J080AA |  | $0.16 | 1 | $0.16
Cin1, Cin2 = 4.7uF | CGA4J3X5R1H475K125AB |  | $0.77 | 2 | $1.54
Cin3 = 0.01uF | C1005X7R1H103K050BB |  | $0.10 | 1 | $0.10
Co1, Co2 = 33uF ceramic (low ESR) | C3216X5R1C336M160AB |  | $1.24 | 2 | $2.48
C1 = 4.7nF | C0603X7R1A472K030BA |  | $0.10 | 1 | $0.10
C2 = 39pF | C0603C0G1E390J030BA |  | $0.10 | 1 | $0.10
Ro1 = 10k(0.1% accuracy) | TPNW120610K0BEEA |  | $0.96 | 1 | $0.96
Ro2 = 1.91k (0.1% accuracy) | TPNW12061K91BEEA |  | $0.96 | 1 | $0.96
R3 = 49.9k (1% accuracy) | CRCW040249K9FKED |  | $0.08 | 1 | $0.08
5V USB Autotransfer System
PMOS Power Switches (12V, 2.7A, 0.4V turn-on) | NTJS3151PT1GOSCT-ND |  | $0.36 | 2 | $0.72 | 48313 | http://www.digikey.com/product-detail/en/NTJS3151PT1G/NTJS3151PT1GOSCT-ND/687125
0.35V Schottky Diodes (5V USB Switch) | MBRA210LT3G | 5.8mm x 7.9mm | $0.54 | 2 | $1.08 | 15664 | http://www.digikey.com/product-detail/en/MBRA210LT3G/MBRA210LT3GOSCT-ND/917974
Resistor 100k (1% accuracy) | CRCW0402100KFKED |  | $0.08 | 2 | $0.16
Resistor 4.7k (1% accuracy) | CRCW04024K70FKED |  | $0.08 | 1 | $0.08
0.1uF Capacitor | C1005X5R1E104K050BC |  | $0.10 | 1 | $0.10
3.3V LDO System
3.3V LDO | ZLDO1117G33TA | 2.5mm x 3.0mm | $0.50 | 2 | $1.00 | 12008 | http://www.digikey.com/product-detail/en/ZLDO1117G33TA/ZLDO1117G33DICT-ND/2095612
Cin = Cout = 10uF | C2012X5R1A106K125AB |  | $0.20 | 2 | $0.40
Converter Autotransfer System based on Battery Voltage
PMOS Power Switches (60V, 5.4A, 1V turn-on) | ZXMP6A16K | 6.5mm x 10mm | $0.87 | 2 | $1.74 | 5309 | http://www.digikey.com/product-detail/en/ZXMP6A16KTC/ZXMP6A16KCT-ND/1873967
NMOS Logic Switch (30V, 2.5A, 0.8V turn-on) | SI2316DS-T1-E3 | 2.5mm x 3mm | $0.60 | 2 | $1.20 | 12977 | http://www.digikey.com/product-detail/en/SI2316DS-T1-E3/SI2316DS-T1-E3CT-ND/1656847
Comparator (2) | LT1018 | 5mm x 6mm | $4.22 | 1 | $4.22 | 2880 | http://www.digikey.com/product-detail/en/LT1018CS8%23PBF/LT1018CS8%23PBF-ND/894434
1 2.5V Zener Diode | MMSZ5222BT1G | 1.6mm x 3.7mm | $0.23 | 1 | $0.23 | 24041 | http://www.digikey.com/product-detail/en/MMSZ5222BT1G/MMSZ5222BT1GOSCT-ND/1967177
Resistor 1k (1% accuracy) | RCL12181K00FKEK |  | $0.54 | 1 | $0.54
Resistor 5k (1% accuracy) | CRCW12065K10FKEA |  | $0.10 | 2 | $0.20
Resistor 10k (1% accuracy) | CRCW120610K0FKEA |  | $0.10 | 1 | $0.10
Resistor 1M (1% accuracy) | CRCW04021M00FKED |  | $0.08 | 3 | $0.24
 |  |  | Total: | 50 | $31.88

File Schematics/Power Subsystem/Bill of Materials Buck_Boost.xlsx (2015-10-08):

Component | Manufacturer Part Number | Footprint | Price/Part | Quantity | Cost | Quantity Available | Datasheet
Buck-Boost Converter System
Switching Regulator | TPIC74100-Q1 | 6.5mm x 4.4mm | $4.28 | 1 | $4.28 | 14720 | http://www.ti.com/product/TPIC74100-Q1/datasheet
Resistor 5.1k (1% Accuracy) | R1: ERJ-8ENF5101V | 3.2mm x 1.6mm | $0.10 | 1 | $0.10 | 106795 | http://www.digikey.com/product-detail/en/ERJ-8ENF5101V/P5.10KFCT-ND/1746607
Resistor 12k (1% accuracy) | R2: RC1206FR-0712K1L | 3.1mm x 1.6mm | $0.10 | 1 | $0.10 | 46068 | http://www.digikey.com/product-detail/en/RC1206FR-0712K1L/311-12.1KFRCT-ND/731465
Input Capacitors (22uF) | C1, C2, C3 | 3.2mm x 1.6mm | $0.66 | 3 | $1.98 | 95477 | http://www.digikey.com/product-detail/en/CL31X226KAHN3NE/1276-3299-1-ND/3891385
Output Capacitors (22uF) | C4, C5, C6 | 3.2mm x 1.6mm | $0.37 | 3 | $1.11 | 112303 | http://www.digikey.com/product-detail/en/CL31A226KPHNNNE/1276-1287-1-ND/3889373
4.7nF Capacitors | C7, C8, C9 | 1mm x 0.5mm | $0.10 | 3 | $0.30 | 50275 | http://www.digikey.com/product-detail/en/CL05B472KA5NNNC/1276-1571-1-ND/3889657
470nF Capacitor | C10 | 1.6mm x 0.8mm | $0.10 | 1 | $0.10 | 90451 | http://www.digikey.com/product-detail/en/CL10B474KA8NFNC/1276-2082-1-ND/3890168
Inductors | L1, L2 | 12.5mm x 12.5mm | $1.28 | 2 | $2.56 | 3434 | http://www.digikey.com/product-detail/en/DR127-330-R/513-1047-1-ND/695328
Diode | D1 PMEG3030EP,115 | 2.7mm x 5mm | $0.45 | 1 | $0.45 | 5166 | http://www.digikey.com/product-detail/en/PMEG3030EP,115/568-6761-1-ND/2676801
Charge-Pump Converter System
Boost Charge Pump (5V) | FAN5602MP5X | 3mm x 3mm | $1.61 | 1 | $1.61 | 5 | http://www.mouser.com/ProductDetail/Fairchild-Semiconductor/FAN5602MP5X/?qs=2UEroHdFiHFOOBCdIWq8Kg%3D%3D
Ceramic Capacitors (2 x 1uF, 2 x 10uF) | CL10B475KQ8NQNC | 1.6mm x 0.8mm | $0.10 | 4 | $0.40 | 471959 | http://www.digikey.com/product-detail/en/CL10B105KP8NNNC/1276-1946-1-ND/3890032
5V USB Autotransfer System
PMOS Power Switches (12V, 2.7A, 0.4V turn-on) | NTJS3151PT1GOSCT-ND |  | $0.36 | 2 | $0.72 | 48313 | http://www.digikey.com/product-detail/en/NTJS3151PT1G/NTJS3151PT1GOSCT-ND/687125
0.35V Schottky Diodes (5V USB Switch) | MBRA210LT3G | 5.8mm x 7.9mm | $0.54 | 2 | $1.08 | 15664 | http://www.digikey.com/product-detail/en/MBRA210LT3G/MBRA210LT3GOSCT-ND/917974
Resistor 100k (1% accuracy) | CRCW0402100KFKED |  | $0.08 | 2 | $0.16
Resistor 4.7k (1% accuracy) | CRCW04024K70FKED |  | $0.08 | 1 | $0.08
0.1uF Capacitor | C1005X5R1E104K050BC |  | $0.10 | 1 | $0.10
3.3V LDO System
3.3V LDO | ZLDO1117G33TA | 2.5mm x 3.0mm | $0.50 | 2 | $1.00 | 12008 | http://www.digikey.com/product-detail/en/ZLDO1117G33TA/ZLDO1117G33DICT-ND/2095612
Cin = Cout = 10uF | C2012X5R1A106K125AB |  | $0.20 | 2 | $0.40
Converter Autotransfer System based on Startup Voltage
PMOS Power Switches (60V, 5.4A, 1V turn-on) | ZXMP6A16K | 6.5mm x 10mm | $0.87 | 2 | $1.74 | 5309 | http://www.digikey.com/product-detail/en/ZXMP6A16KTC/ZXMP6A16KCT-ND/1873967
NMOS Logic Switch (30V, 2.5A, 0.8V turn-on) | SI2316DS-T1-E3 | 2.5mm x 3mm | $0.60 | 3 | $1.80 | 12977 | http://www.digikey.com/product-detail/en/SI2316DS-T1-E3/SI2316DS-T1-E3CT-ND/1656847
Comparator (2) | LT1018 | 5mm x 6mm | $4.22 | 1 | $4.22 | 2880 | http://www.digikey.com/product-detail/en/LT1018CS8%23PBF/LT1018CS8%23PBF-ND/894434
1 2.5V Zener Diode | MMSZ5222BT1G | 1.6mm x 3.7mm | $0.23 | 1 | $0.23 | 24041 | http://www.digikey.com/product-detail/en/MMSZ5222BT1G/MMSZ5222BT1GOSCT-ND/1967177
Schottky Diode (30Vbd, 3A, 0.36Von) | PMEG3030EP,115 | 5.0mm x 2.7mm | $0.41 | 1 | $0.41 | 7750 | http://www.digikey.com/product-detail/en/PMEG3030EP,115/568-6761-1-ND/2676801
Resistor 1k (1% accuracy) | RCL12181K00FKEK |  | $0.54 | 1 | $0.54
Resistor 5k (1% accuracy) | CRCW12065K10FKEA |  | $0.10 | 2 | $0.20
Resistor 10k (1% accuracy) | CRCW120610K0FKEA |  | $0.10 | 1 | $0.10
Resistor 1M (1% accuracy) | CRCW04021M00FKED |  | $0.08 | 4 | $0.32
0.1uF Capacitor | C1005X5R1E104K050BC |  | $0.10 | 1 | $0.10
 |  |  | Total: | 49 | $26.09

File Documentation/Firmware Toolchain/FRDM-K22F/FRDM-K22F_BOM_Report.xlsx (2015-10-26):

 | Report Name | Freescale Costed BOM Report
 | Date Generated: | 09/06/2014 06:27 AM MST
 | Item Number: | FRDM-K22F
 | Item Revision: | MCO34387
 | BOM-Levels: | BOM-Levels: All Levels Item-Types: Part;CADPart;MarketingPN; Mfr-Part-Lifecycle-Phases: Active;ROHS Active; Mfr-Statuses: Alternate;Preferred;
Level | Item Type | Item Number | Item Rev | Description | Mfr. Name | Mfr. Part Number | Qty | Ref Des | Notes | Mfr Part Status | Mfr Preferred Status
0 | MarketingPN | FRDM-K22F | A MCO34387 | FRDM-K22F | Shenzhen Embest Technology Co., Ltd | FRDM-K22F |  |  |  | Active | Preferred
.1 | Part | 975-28164 | A MCO34914 | HW PACKOUT, FRDM-K22F |  |  | 1
..2 | Part | 570-76099 | A MCO35005 | BOX, FREEDOM PLATFORM CUSTOM FOR K64F |  |  | 1
...3 | Part | 806-76099 | A MCO35228 | BOX ARTWORK, FREEDOM PLATFORM FOR K64F |  |  | 0
..2 | Part | 920-28164 | A MCO34925 | INSERT, COLOR PRINTED CARD, FRDM-K22F |  |  | 1
..2 | Part | 805-75203 | H1 MCO35194 | LABEL, PDC BARCODE | International Paper | MOT-PDC (B1850101-7) | 1 |  |  | Active | Preferred
..2 | Part | 805-75203 | H1 MCO35194 | LABEL, PDC BARCODE | NORTEC INTERNATIONAL/AMI LTD. | K545-PAI | 1 |  |  | Active | Preferred
..2 | Part | 700-28164 | A MCO34997 | PWA, FRDM-K22F |  |  | 1
...3 | Part | 170-28164 | D MCO34923 | PWB, FRDM-K22F | BARE BOARD GROUP | 170-28164_A | 1 |  |  | ROHS Active | Preferred
...3 | Part | 170-28164 | D MCO34923 | PWB, FRDM-K22F | BARE BOARD GROUP | 170-28164_B | 1 |  |  | ROHS Active | Preferred
...3 | Part | 170-28164 | D MCO34923 | PWB, FRDM-K22F | BARE BOARD GROUP | 170-28164_C | 1 |  |  | ROHS Active | Preferred
...3 | Part | 170-28164 | D MCO34923 | PWB, FRDM-K22F | BARE BOARD GROUP | 170-28164_C1 | 1 |  |  | ROHS Active | Preferred
...3 | Part | 170-28164 | D MCO34923 | PWB, FRDM-K22F | BARE BOARD GROUP | 170-28164_D | 1 |  |  | ROHS Active | Preferred
...3 | CADPart | 280-76577 | A MCO34900 | BUMPON CYLINDRICAL .312X.215 BLK | 3M | SJ61A6 | 4 |  | SEE ASY FILE FOR DETAIL | Active | Preferred
...3 | CADPart | 211-30048 | A MCO35547 | SHUNT -- 0.1IN SP JMPR -- AU BLACK | SAMTEC | SNT-100-BK-G | 4 |  | SEE ASY FILE FOR DETAIL | ROHS Active | Preferred
...3 | Part | 805-76618 | A MCO35096 | LABEL, 0.275"X0.275", ASSEMBLY / REVISION |  |  | 1 |  | SEE ASY FILE FOR DETAIL
...3 | Part | 805-77101 | A MCO35295 | LABEL, .5"X.25", FIRMWARE VERSION |  |  | 1 |  | SEE ASY FILE FOR DETAIL
...3 | Part | 750-28164 | D MCO34919 | SUB ASSEMBLY, SCHEMATIC PARTS, 700-28164, FRDM-K22F |  |  | 1
....4 | CADPart | 150-75266 | A1 MCO34818 | CAP CER 22PF 50V 5% C0G 0402 | AVX | 04025A220JAT2A | 2 | C31,C38 |  | ROHS Active | Preferred
....4 | CADPart | 150-75266 | A1 MCO34818 | CAP CER 22PF 50V 5% C0G 0402 | KEMET | C0402C220J5GAC | 2 | C31,C38 |  | ROHS Active | Alternate
....4 | CADPart | 150-75266 | A1 MCO34818 | CAP CER 22PF 50V 5% C0G 0402 | VENKEL COMPANY | C0402C0G500-220JNE | 2 | C31,C38 |  | ROHS Active | Alternate
....4 | CADPart | 150-75634 | A1 MCO34861 | CAP CER 0.1UF 10V 10% X5R 0402 | AVX | 0402ZD104KAT2A | 27 | C2,C4-C9,C12,C14-C18,C20,C22-C24,C27,C29,C34,C35,C47,C52,C57-C59,C62 |  | ROHS Active | Alternate
....4 | CADPart | 150-75634 | A1 MCO34861 | CAP CER 0.1UF 10V 10% X5R 0402 | JOHANSON DIELECTRICS | 100R07X104KV4T | 27 | C2,C4-C9,C12,C14-C18,C20,C22-C24,C27,C29,C34,C35,C47,C52,C57-C59,C62 |  | ROHS Active | Alternate
....4 | CADPart | 150-75634 | A1 MCO34861 | CAP CER 0.1UF 10V 10% X5R 0402 | KEMET | C0402C104K8PAC | 27 | C2,C4-C9,C12,C14-C18,C20,C22-C24,C27,C29,C34,C35,C47,C52,C57-C59,C62 |  | ROHS Active | Preferred
....4 | CADPart | 150-75634 | A1 MCO34861 | CAP CER 0.1UF 10V 10% X5R 0402 | MURATA | GRM155R61A104KA01D | 27 | C2,C4-C9,C12,C14-C18,C20,C22-C24,C27,C29,C34,C35,C47,C52,C57-C59,C62 |  | ROHS Active | Alternate
....4 | CADPart | 150-75634 | A1 MCO34861 | CAP CER 0.1UF 10V 10% X5R 0402 | TDK | C1005X5R1A104KB | 27 | C2,C4-C9,C12,C14-C18,C20,C22-C24,C27,C29,C34,C35,C47,C52,C57-C59,C62 |  | Active | Alternate
....4 | CADPart | 150-75772 | A1 MCO34744 | CAP CER 1.0UF 10V 10% X5R 0402 | CAL-CHIP | GMC04X5R105K10NT-LF | 5 | C28,C36,C43,C48,C50 |  | Active | Alternate
....4 | CADPart | 150-75772 | A1 MCO34744 | CAP CER 1.0UF 10V 10% X5R 0402 | MURATA | GRM155R61A105KE15D | 5 | C28,C36,C43,C48,C50 |  | ROHS Active | Alternate
....4 | CADPart | 150-75772 | A1 MCO34744 | CAP CER 1.0UF 10V 10% X5R 0402 | WALSIN TECHNOLOGY CORP. | 0402X105K100CT | 5 | C28,C36,C43,C48,C50 |  | Active | Alternate
....4 | CADPart | 150-75772 | A1 MCO34744 | CAP CER 1.0UF 10V 10% X5R 0402 | YAGEO AMERICA | CC0402KRX5R6BB105 | 5 | C28,C36,C43,C48,C50 |  | ROHS Active | Preferred
....4 | CADPart | 150-76334 | A MCO34876 | CAP CER 1000PF 50V 5% C0G 0402 | MURATA | GRM1555C1H102JA01D | 1 | C3 |  | Active | Preferred
....4 | CADPart | 150-76334 | A MCO34876 | CAP CER 1000PF 50V 5% C0G 0402 | WALSIN TECHNOLOGY CORP. | 0402N102J500LT | 1 | C3 |  | Active | Alternate
....4 | CADPart | 150-78463 | A1 MCO34829 | CAP CER 4.7UF 6.3V 20% X5R 0402 | TDK | C1005X5R0J475M | 2 | C21,C40 |  | Active | Alternate
....4 | CADPart | 150-78463 | A1 MCO34829 | CAP CER 4.7UF 6.3V 20% X5R 0402 | VENKEL COMPANY | C0402X5R6R3-475MNP | 2 | C21,C40 |  | Active | Preferred
....4 | CADPart | 150-78609 | A MCO34806 | CAP CER 10UF 10V 20% X5R 0603 | TAIYO YUDEN | LMK107BJ106MALTD | 3 | C13,C45,C63 |  | Active | Preferred
....4 | CADPart | 150-78609 | A MCO34806 | CAP CER 10UF 10V 20% X5R 0603 | TDK | C1608X5R1A106M | 3 | C13,C45,C63 |  | ROHS Active | Alternate
....4 | CADPart | 150-78609 | A MCO34806 | CAP CER 10UF 10V 20% X5R 0603 | VENKEL COMPANY | C0603X5R100-106MNP | 3 | C13,C45,C63 |  | ROHS Active | Alternate
....4 | CADPart | 150-78975 | A MCO34884 | CAP CER 2.2uF 25V 10% X5R 0603 | TDK | C1608X5R1E225K | 3 | C26,C56,C65 |  | Active | Preferred
....4 | CADPart | 150-79092 | A MCO34818 | CAP CER 10uF 16V 20% X5R 0603 | TAIYO YUDEN | EMK107BBJ106MA-T | 1 | C30 |  | Active | Preferred
....4 | CADPart | 150-79092 | A MCO34818 | CAP CER 10uF 16V 20% X5R 0603 | TDK | C1608X5R1C106M080AB | 1 | C30 |  | Active | Alternate
....4 | CADPart | 150-79255 | A MCO34840 | CAP CER 10uF 10V 20% X5R 0402 | SAMSUNG | CL05A106MP5NUNC | 2 | C1,C37 |  | Active | Preferred
....4 | CADPart | 180-30021 | A MCO34901 | IND FER BEAD 330OHM@100MHZ 2.5A -- SMT | Shenzhen Sunlord Electronics Co., Ltd | UPZ2012E331-2R5TF | 2 | L1,L3 |  | ROHS Active | Alternate
....4 | CADPart | 180-30021 | A MCO34901 | IND FER BEAD 330OHM@100MHZ 2.5A -- SMT | TDK | MPZ2012S331A | 2 | L1,L3 |  | ROHS Active | Preferred
....4 | CADPart | 180-78156 | A MCO34856 | IND FER BEAD 330OHM@100MHZ 1.7A 0603 | TDK | MPZ1608S331A | 2 | L2,L4 |  | Active | Preferred
....4 | CADPart | 210-75439 | A1 MCO34818 | HDR 1X2 TH 100MIL SP 339H AU 98L | 3M | 929647-01-02-EU | 5 | J10,J13,J15,J21,J22 |  | ROHS Active | Alternate
....4 | CADPart | 210-75439 | A1 MCO34818 | HDR 1X2 TH 100MIL SP 339H AU 98L | ANYTRONIC CORPORATION LIMITED | 090021S02015-2LF | 5 | J10,J13,J15,J21,J22 |  | Active | Alternate
....4 | CADPart | 210-75439 | A1 MCO34818 | HDR 1X2 TH 100MIL SP 339H AU 98L | ANYTRONIC CORPORATION LIMITED | 090021S02018-2LF | 5 | J10,J13,J15,J21,J22 |  | ROHS Active | Alternate
....4 | CADPart | 210-75439 | A1 MCO34818 | HDR 1X2 TH 100MIL SP 339H AU 98L | FCI | 77311-801-02LF | 5 | J10,J13,J15,J21,J22 |  | ROHS Active | Alternate
....4 | CADPart | 210-75439 | A1 MCO34818 | HDR 1X2 TH 100MIL SP 339H AU 98L | SAMTEC | HTSW-102-07-G-S | 5 | J10,J13,J15,J21,J22 |  | ROHS Active | Alternate
....4 | CADPart | 210-75439 | A1 MCO34818 | HDR 1X2 TH 100MIL SP 339H AU 98L | SAMTEC | HTSW-102-07-SM-S | 5 | J10,J13,J15,J21,J22 |  | Active | Alternate
....4 | CADPart | 210-75439 | A1 MCO34818 | HDR 1X2 TH 100MIL SP 339H AU 98L | SAMTEC | TSW-102-07-G-S | 5 | J10,J13,J15,J21,J22 |  | ROHS Active | Preferred
....4 | CADPart | 210-75439 | A1 MCO34818 | HDR 1X2 TH 100MIL SP 339H AU 98L | SAMTEC | TSW-102-07-S-S | 5 | J10,J13,J15,J21,J22 |  | Active | Alternate
....4 | CADPart | 210-75685 | A1 MCO34818 | TEST POINT WHITE 40 MIL DRILL 180 MIL TH 109L | COMPONENTS CORPORATION | TP-105-01-09 | 1 | TP21 |  | ROHS Active | Alternate
....4 | CADPart | 210-75685 | A1 MCO34818 | TEST POINT WHITE 40 MIL DRILL 180 MIL TH 109L | KEYSTONE ELECTRONICS | 5002 | 1 | TP21 |  | ROHS Active | Preferred
....4 | CADPart | 210-75685 | A1 MCO34818 | TEST POINT WHITE 40 MIL DRILL 180 MIL TH 109L | KOBICONN | 151-201-RC | 1 | TP21 |  | ROHS Active | Alternate
....4 | CADPart | 210-75726 | A1 MCO34874 | HDR 1X3 TH 100MIL SP 339H AU 100L | ANYTRONIC CORPORATION LIMITED | 090021S03015-2LF | 1 | J9 |  | ROHS Active | Alternate
....4 | CADPart | 210-75726 | A1 MCO34874 | HDR 1X3 TH 100MIL SP 339H AU 100L | FCI | 77311-801-03LF | 1 | J9 |  | ROHS Active | Alternate
....4 | CADPart | 210-75726 | A1 MCO34874 | HDR 1X3 TH 100MIL SP 339H AU 100L | Pinrex Enterprise Co., Ltd | 210-91-03GB01 | 1 | J9 |  | Active | Alternate
....4 | CADPart | 210-75726 | A1 MCO34874 | HDR 1X3 TH 100MIL SP 339H AU 100L | SAMTEC | TSW-103-07-G-S | 1 | J9 |  | ROHS Active | Preferred
....4 | CADPart | 210-75726 | A1 MCO34874 | HDR 1X3 TH 100MIL SP 339H AU 100L | SAMTEC | TSW-103-07-S-S | 1 | J9 |  | ROHS Active | Alternate
....4 | CADPart | 210-77612 | A MCO34867 | TEST POINT PAD 035-018MIL TH, NO PART TO ORDER |  |  | 1 | TP27
....4 | CADPart | 210-78860 | A MCO34849 | CON 2X8 SKT TH 100MIL SP 335H AU 104L | SAMTEC | SSW-108-01-G-D | 2 | J1,J25 |  | ROHS Active | Alternate
....4 | CADPart | 210-78860 | A MCO34849 | CON 2X8 SKT TH 100MIL SP 335H AU 104L | SAMTEC | SSW-108-01-S-D | 2 | J1,J25 |  | Active | Preferred
....4 | CADPart | 210-80119 | A MCO34898 | CON 2X10 SKT TH 100MIL CTR 340H AU 104L | SAMTEC | SSW-110-01-G-D | 1 | J2 |  | ROHS Active | Preferred
....4 | CADPart | 210-80123 | A MCO34858 | CON 2X6 SKT TH 100MIL CTR 340H AU 104L | SAMTEC | SSW-106-01-G-D | 1 | J24 |  | Active | Preferred
....4 | CADPart | 210-80192 | A MCO34866 | HDR 2X5 TH 50MIL CTR 167H AU 91L | ANYTRONIC CORPORATION LIMITED | 0922S0205011N6T-2LF | 2 | J11,J12 |  | Active | Preferred
....4 | CADPart | 210-80192 | A MCO34866 | HDR 2X5 TH 50MIL CTR 167H AU 91L | SULLINS ELECTRONICS CORP | GRPB052VWVN-RC | 2 | J11,J12 |  | Active | Alternate
....4 | CADPart | 211-76642 | A MCO34880 | TEST POINT PAD 30MIL DIA SMT, NO PART TO ORDER |  |  | 26 | TP1-TP18,TP20,TP22-TP24,TP26,TP28-TP30
....4 | CADPart | 211-79505 | A MCO34878 | CON 5 USB2.0 MICRO-AB RA REVERSE SKT SMT 0.65MM SP 99H AU | HIROSE | ZX62R-AB-5P | 2 | J5,J16 |  | Active | Preferred
....4 | CADPart | 230-77653 | A MCO34905 | XTAL 32.768KHZ 12.5PF 20PPM 3.2X1.5MM SMT | ABRACON CORPORATION | ABS07-32.768KHZ-T | 1 | Y2 |  | Active | Preferred
....4 | CADPart | 230-77653 | A MCO34905 | XTAL 32.768KHZ 12.5PF 20PPM 3.2X1.5MM SMT | ECS INC. INTERNATIONAL | ECS-.327-12.5-34B | 1 | Y2 |  | ROHS Active | Alternate
....4 | CADPart | 230-77664 | A1 MCO34890 | XTAL 8.00MHZ RSN CERAMIC -- SMT | MURATA | CSTCE8M00G55-R0 | 1 | X1 |  | ROHS Active | Preferred
....4 | CADPart | 230-77754 | A MCO34866 | XTAL 8MHZ 20PPM PAR 18PF ESR 200OHM SMT | ABRACON CORPORATION | ABM3B-8.000MHZ-B2-T | 1 | Y1 |  | ROHS Active | Preferred
....4 | CADPart | 312-80039 | A MCO34818 | IC VREG LDO 1A 3.3V SOT223 | ON SEMICONDUCTOR | NCP1117ST33T3G | 1 | U16 |  | Active | Preferred
....4 | CADPart | 312-80418 | A MCO34818 | IC ACCELEROMETER AND MAGNETOMETER SENSOR 3-AXIS 2.5V QFN16 | FREESCALE SEMICONDUCTOR | FXOS8700CQ | 1 | U8 |  | ROHS Active | Preferred
....4 | CADPart | 312-80758 | A MCO34818 | IC XCVR 1BIT 3-STATE DUAL 1.2-5.5V XSON6 | NXP SEMICONDUCTORS | 74LVCH1T45GM,132 | 3 | U2,U6,U11 |  | Active | Preferred
....4 | CADPart | 312-80762 | A MCO34818 | IC XCVR DUAL SUPPLY 1.2 -5.5V XQFN8 | NXP SEMICONDUCTORS | 74LVC2T45GM,125 | 1 | U1 |  | Active | Preferred
....4 | CADPart | 312-80763 | A MCO34818 | IC DUAL SUPPLY XCVR 50 MBPS 5.5V XQFN8 | NXP SEMICONDUCTORS | NTSX2102GU8H | 1 | U3 |  | Active | Preferred
....4 | CADPart | 315-78830 | A MCO34838 | IC INV DUAL SCHMITT TRIGGER 1.65-5.5V ULLGA6 | ON SEMICONDUCTOR | NLX2G14AMX1TCG | 1 | U9 |  | ROHS Active | Preferred
....4 | CADPart | 315-79199 | A1 MCO34818 | IC LIN SW PWR 0.8A 2.5-5.5V SOT23-6 | MICREL | MIC2005-0.8YM6 | 1 | U12 |  | Active | Preferred
....4 | CADPart | 315-80026 | A MCO34848 | IC SW CURRENT LIMIT ADJ 0.1-2.1A 2.5-5.5V UDFN6 | ON SEMICONDUCTOR | NCP380HMUAJAATBG | 1 | U13 |  | Active | Preferred
....4 | CADPart | 344-01231 | B CO0094079 | IC MCU FLASH 128KB 50MHZ 1.71-3.6V QFN32 | FREESCALE SEMICONDUCTOR | MK20DX128VFM5 | 1 | U10 |  | Active | Preferred
....4 | CADPart | 344-01231 | B CO0094079 | IC MCU FLASH 128KB 50MHZ 1.71-3.6V QFN32 | FREESCALE SEMICONDUCTOR | PK20DX128VFM5 | 1 | U10 |  | ROHS Active | Alternate
....4 | CADPart | 344-02014 | A MCO34901 | IC MCU 32BIT 512KB FLASH 128KB RAM 1.71-3.6V 120MHZ LQFP64 | FREESCALE SEMICONDUCTOR | MK22FN512VLH12 | 1 | U15 |  | Active | Preferred
....4 | CADPart | 370-75079 | A1 MCO34818 | LED ULTRA BRIGHT RED SGL 30MA 0603 | LITE ON | LTST-C190KRKT | 1 | D2 |  | ROHS Active | Preferred
....4 | CADPart | 370-76565 | A MCO34818 | LED GRN SGL 20MA 0603 | OSRAM | LG L29K-G2J1-24-Z | 1 | D1 |  | ROHS Active | Preferred
....4 | CADPart | 370-76567 | A MCO34818 | LED RED BL GRN SGL 50/25/25mA SMT | Cree, Inc | CLV1A-FKB-CJ1M1F1BB7R4S3 | 1 | D14 |  | ROHS Active | Preferred
....4 | CADPart | 470-30297 | A MCO34818 | RES MF 220 OHM 1/10W 5% 0603 | KOA SPEER | RK73B1JTTD221J | 1 | R1 |  | ROHS Active | Preferred
....4 | CADPart | 470-30297 | A MCO34818 | RES MF 220 OHM 1/10W 5% 0603 | WALSIN TECHNOLOGY CORP. | WR06X221 JTL | 1 | R1 |  | Active | Alternate
....4 | CADPart | 470-30297 | A MCO34818 | RES MF 220 OHM 1/10W 5% 0603 | YAGEO AMERICA | RC0603JR-07220RL | 1 | R1 |  | ROHS Active | Alternate
....4 | CADPart | 470-30782 | A MCO34840 | RES MF 270 OHM 1/16W 1% 0402 | KOA SPEER | RK73H1ETTP2700F | 2 | R91,R93 |  | ROHS Active | Preferred
....4 | CADPart | 470-30782 | A MCO34840 | RES MF 270 OHM 1/16W 1% 0402 | WALSIN TECHNOLOGY CORP. | WR04X2700FTL | 2 | R91,R93 |  | ROHS Active | Alternate
....4 | CADPart | 470-30801 | A MCO34828 | RES MF 430 OHM 1/16W 1% 0402 | KOA SPEER | RK73H1ETTP4300F | 1 | R92 |  | ROHS Active | Preferred
....4 | CADPart | 470-30965 | A MCO34818 | RES MF 15K 1/16W 1% 0402 | KOA SPEER | RK73H1ETTP1502F | 1 | R47 |  | ROHS Active | Preferred
....4 | CADPart | 470-30965 | A MCO34818 | RES MF 15K 1/16W 1% 0402 | WALSIN TECHNOLOGY CORP. | WR04X1502FTL | 1 | R47 |  | ROHS Active | Alternate
....4 | CADPart | 470-31002 | A2 MCO34905 | RES MF 31.6K 1/16W 1% 0402 | WALSIN TECHNOLOGY CORP. | WR04X3162FTL | 1 | R50 |  | Active | Preferred
....4 | CADPart | 470-31002 | A2 MCO34905 | RES MF 31.6K 1/16W 1% 0402 | YAGEO AMERICA | RC0402FR-0731K6L | 1 | R50 |  | ROHS Active | Alternate
....4 | CADPart | 470-75394 | A1 MCO34818 | RES MF ZERO OHM 1/16W 5% 0402 | BOURNS | CR0402-J/-000GLF | 8 | R17,R19,R21,R30,R69,R71,R81,R82 |  | ROHS Active | Alternate
....4 | CADPart | 470-75394 | A1 MCO34818 | RES MF ZERO OHM 1/16W 5% 0402 | KOA SPEER | RK73Z1ETTP | 8 | R17,R19,R21,R30,R69,R71,R81,R82 |  | ROHS Active | Alternate
....4 | CADPart | 470-75394 | A1 MCO34818 | RES MF ZERO OHM 1/16W 5% 0402 | PANASONIC | ERJ2GE0R00X | 8 | R17,R19,R21,R30,R69,R71,R81,R82 |  | ROHS Active | Alternate
....4 | CADPart | 470-75394 | A1 MCO34818 | RES MF ZERO OHM 1/16W 5% 0402 | ROHM | MCR01MZPJ000 | 8 | R17,R19,R21,R30,R69,R71,R81,R82 |  | ROHS Active | Preferred
....4 | CADPart | 470-75394 | A1 MCO34818 | RES MF ZERO OHM 1/16W 5% 0402 | SEI ELECTRONICS INC | RMCF1/16S0.005%R | 8 | R17,R19,R21,R30,R69,R71,R81,R82 |  | ROHS Active | Alternate
....4 | CADPart | 470-75394 | A1 MCO34818 | RES MF ZERO OHM 1/16W 5% 0402 | SKYMOS | RC-0402-0000T | 8 | R17,R19,R21,R30,R69,R71,R81,R82 |  | ROHS Active | Alternate
....4 | CADPart | 470-75394 | A1 MCO34818 | RES MF ZERO OHM 1/16W 5% 0402 | SMEC | RC73JP2ZF | 8 | R17,R19,R21,R30,R69,R71,R81,R82 |  | ROHS Active | Alternate
....4 | CADPart | 470-75394 | A1 MCO34818 | RES MF ZERO OHM 1/16W 5% 0402 | THYE MING TECH CO LTD | CR-02JL6----0R | 8 | R17,R19,R21,R30,R69,R71,R81,R82 |  | ROHS Active | Alternate
....4 | CADPart | 470-75394 | A1 MCO34818 | RES MF ZERO OHM 1/16W 5% 0402 | VENKEL COMPANY | CR0402-16W-000T | 8 | R17,R19,R21,R30,R69,R71,R81,R82 |  | ROHS Active | Alternate
....4 | CADPart | 470-75394 | A1 MCO34818 | RES MF ZERO OHM 1/16W 5% 0402 | WALSIN TECHNOLOGY CORP. | WR04X000_PTL | 8 | R17,R19,R21,R30,R69,R71,R81,R82 |  | ROHS Active | Alternate
....4 | CADPart | 470-75394 | A1 MCO34818 | RES MF ZERO OHM 1/16W 5% 0402 | YAGEO AMERICA | RC0402JR-070RL | 8 | R17,R19,R21,R30,R69,R71,R81,R82 |  | ROHS Active | Alternate
....4 | CADPart | 470-75407 | A2 MCO34303 | RES MF ZERO OHM 1/10W -- AEC-Q200 0603 | KOA SPEER | RK73Z1JTTD | 12 | R23,R35,R37,R40,R42,R49,R52,R55,R62,R86,R88,R89 |  | ROHS Active | Alternate
....4 | CADPart | 470-75407 | A2 MCO34303 | RES MF ZERO OHM 1/10W -- AEC-Q200 0603 | PANASONIC | ERJ-3GEY0R00V | 12 | R23,R35,R37,R40,R42,R49,R52,R55,R62,R86,R88,R89 |  | ROHS Active | Alternate
....4 | CADPart | 470-75407 | A2 MCO34303 | RES MF ZERO OHM 1/10W -- AEC-Q200 0603 | VISHAY INTERTECHNOLOGY | CRCW06030000Z0EA | 12 | R23,R35,R37,R40,R42,R49,R52,R55,R62,R86,R88,R89 |  | ROHS Active | Preferred
....4 | CADPart | 470-75410 | A MCO34819 | RES MF 10K 1/10W 5% 0603 | BOURNS | CR0603-JW-103ELF | 5 | R5,R12,R14,R36,R59 |  | ROHS Active | Alternate
....4 | CADPart | 470-75410 | A MCO34819 | RES MF 10K 1/10W 5% 0603 | KOA SPEER | RK73B1JTTD103J | 5 | R5,R12,R14,R36,R59 |  | ROHS Active | Preferred
....4 | CADPart | 470-75410 | A MCO34819 | RES MF 10K 1/10W 5% 0603 | LIKET CORPORATION | 0603103J | 5 | R5,R12,R14,R36,R59 |  | ROHS Active | Alternate
....4 | CADPart | 470-75410 | A MCO34819 | RES MF 10K 1/10W 5% 0603 | SMEC | RC73L2C103JTF | 5 | R5,R12,R14,R36,R59 |  | ROHS Active | Alternate
....4 | CADPart | 470-75410 | A MCO34819 | RES MF 10K 1/10W 5% 0603 | VENKEL COMPANY | CR0603-10W-103JT | 5 | R5,R12,R14,R36,R59 |  | ROHS Active | Alternate
....4 | CADPart | 470-75410 | A MCO34819 | RES MF 10K 1/10W 5% 0603 | VISHAY INTERTECHNOLOGY | CRCW060310K0JNEA | 5 | R5,R12,R14,R36,R59 |  | ROHS Active | Alternate
....4 | CADPart | 470-75410 | A MCO34819 | RES MF 10K 1/10W 5% 0603 | WALSIN TECHNOLOGY CORP. | WR06X103JTL | 5 | R5,R12,R14,R36,R59 |  | ROHS Active | Alternate
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

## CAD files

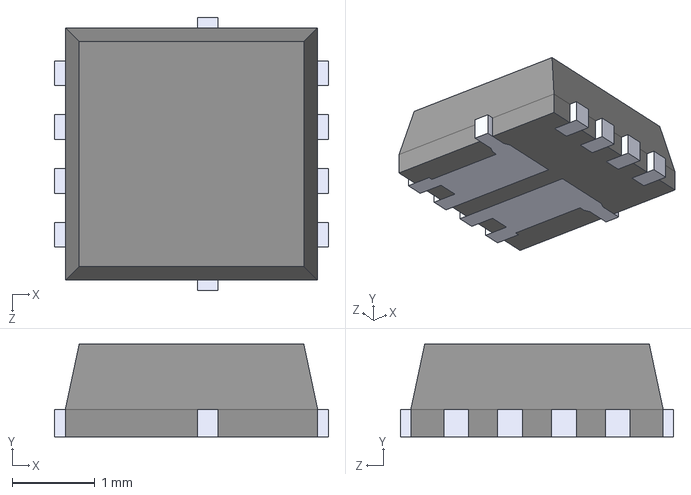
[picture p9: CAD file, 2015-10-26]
PCBA/Master_Altium_Library/3D Models/PowerPAK-1212-8.step
3.31 x 1.12 x 3.30 mm

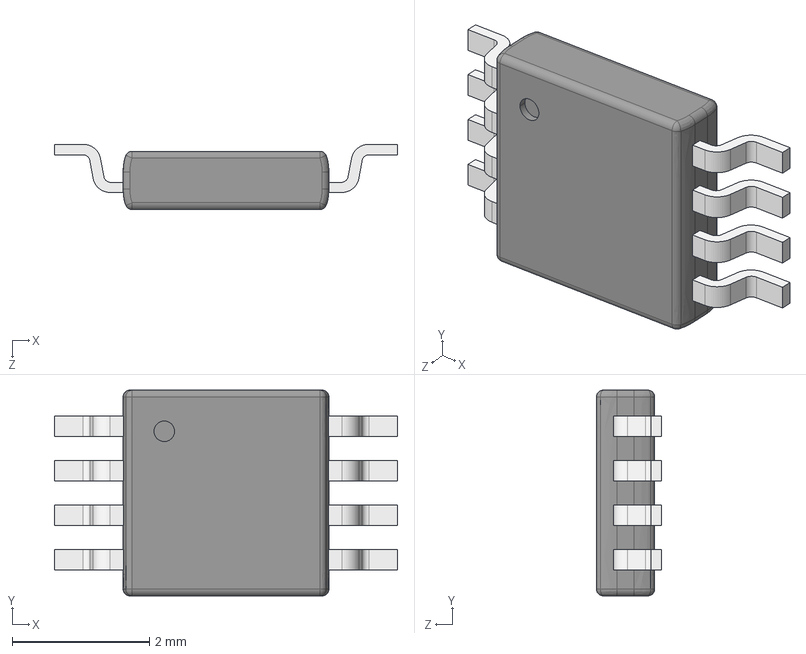
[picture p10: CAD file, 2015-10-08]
PCBA/Master_Altium_Library/3D Models/User Library-uMAX8/uMAX8.STEP
5.00 x 3.00 x 0.95 mm
SW3dPS-uMAX8_Part_602
SW3dPS-uMAX8_Part_374
SW3dPS-uMAX8_Part_141
SW3dPS-uMAX8_Part_526
SW3dPS-uMAX8_Part_450
SW3dPS-uMAX8_Part_262
SW3dPS-uMAX8_Part_754
SW3dPS-uMAX8_Part_678
SW3dPS-uMAX8_Part_181

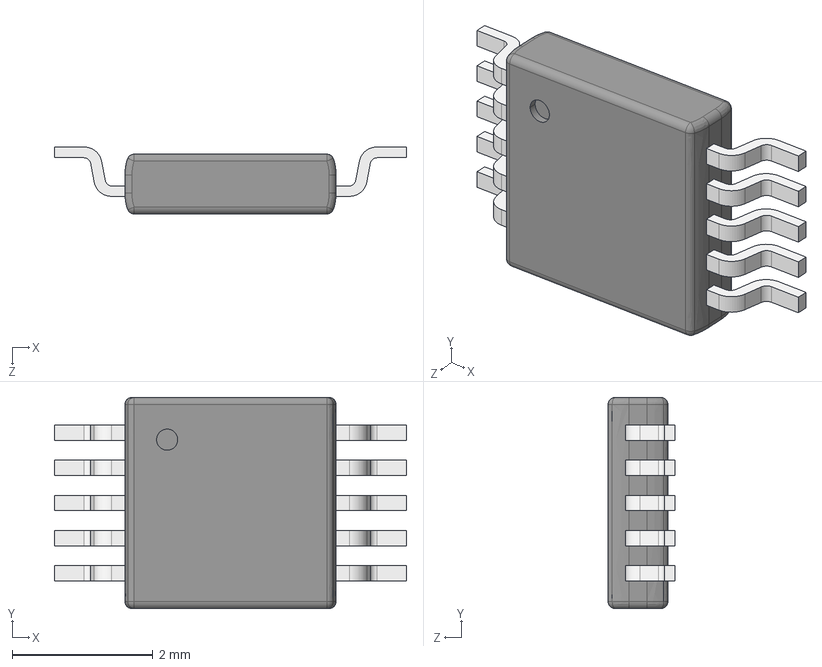
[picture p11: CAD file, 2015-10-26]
PCBA/Master_Altium_Library/3D Models/uMAX10.STEP
5.00 x 3.00 x 0.95 mm
SW3dPS-uMAX10_Part_141
SW3dPS-uMAX10_Part_2291
SW3dPS-uMAX10_Part_1911
SW3dPS-uMAX10_Part_1987
SW3dPS-uMAX10_Part_1492
SW3dPS-uMAX10_Part_2139
SW3dPS-uMAX10_Part_2443
SW3dPS-uMAX10_Part_1799
SW3dPS-uMAX10_Part_2367
SW3dPS-uMAX10_Part_2215
SW3dPS-uMAX10_Part_2063

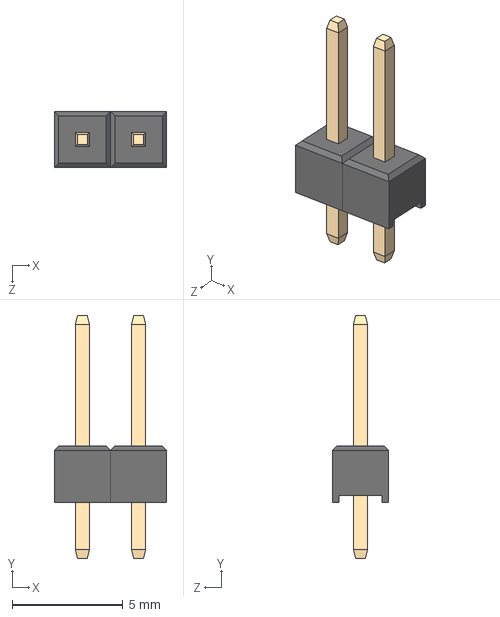
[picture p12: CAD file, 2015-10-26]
PCBA/Master_Altium_Library/3D Models/1x2 Header.STEP
5.08 x 11.0 x 2.54 mm
User Library-Header1x2_Header1_1 x 2

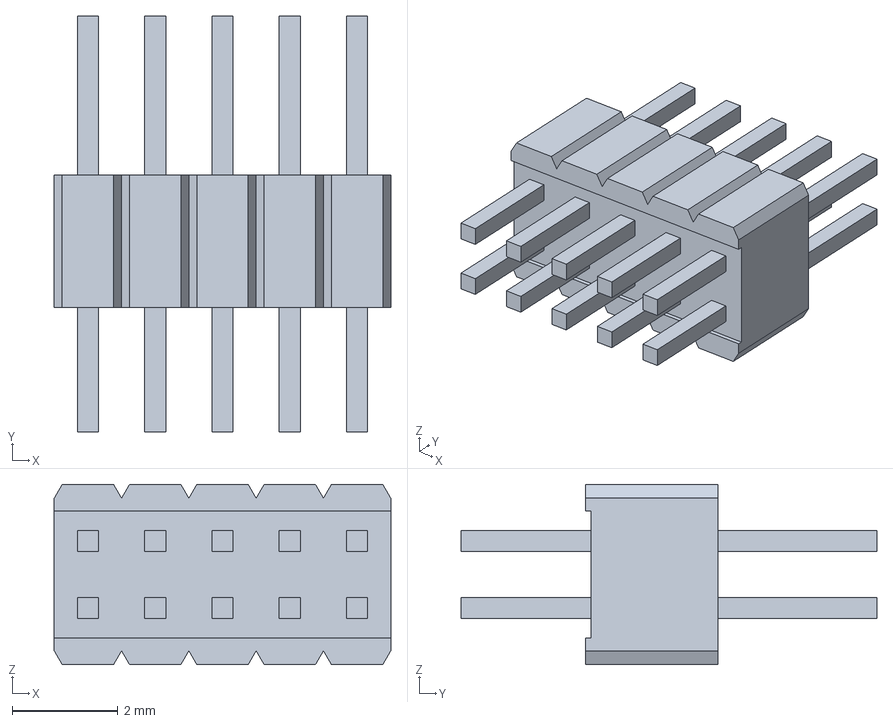
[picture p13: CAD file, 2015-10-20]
PCBA/Master_Altium_Library/3D Models/2x5_JTAG_HEADER_TH.stp
6.35 x 7.85 x 3.40 mm

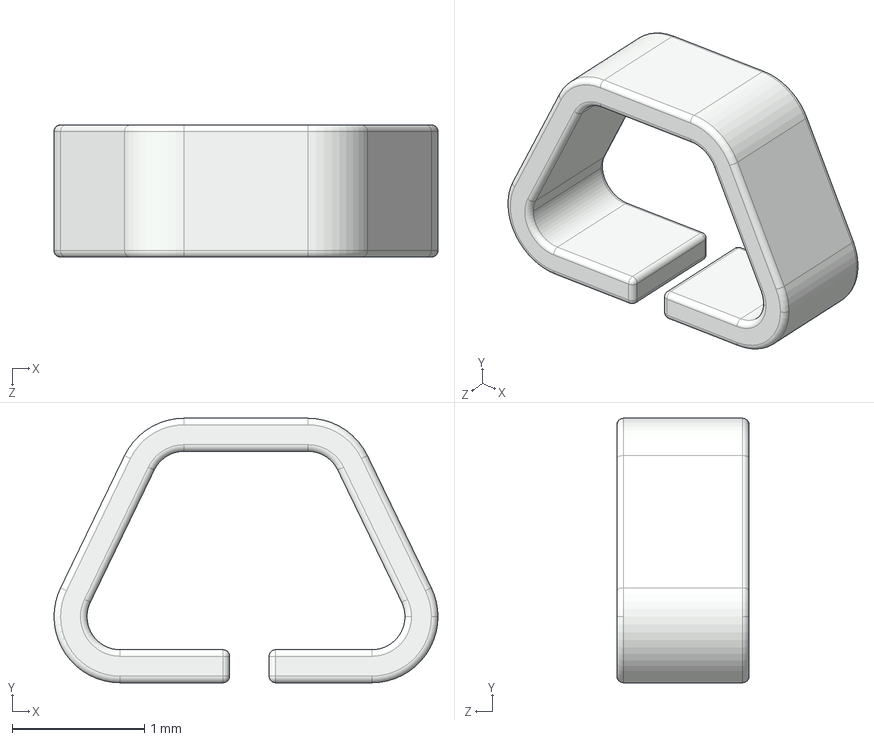
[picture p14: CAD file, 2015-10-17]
PCBA/Master_Altium_Library/3D Models/Testpoint 5015.step
2.90 x 2.00 x 1.00 mm

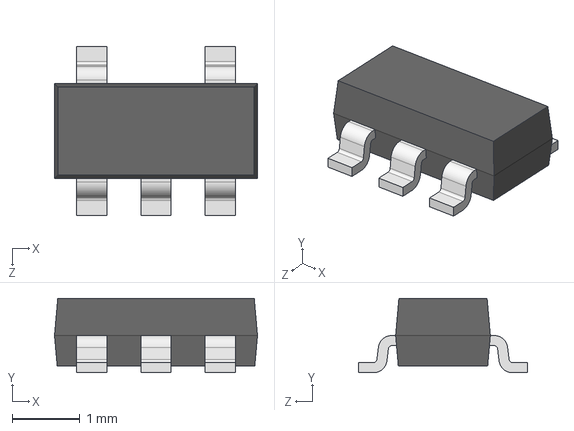
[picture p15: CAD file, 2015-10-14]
PCBA/Master_Altium_Library/3D Models/SOT-23-5.step
3.00 x 1.10 x 2.50 mm

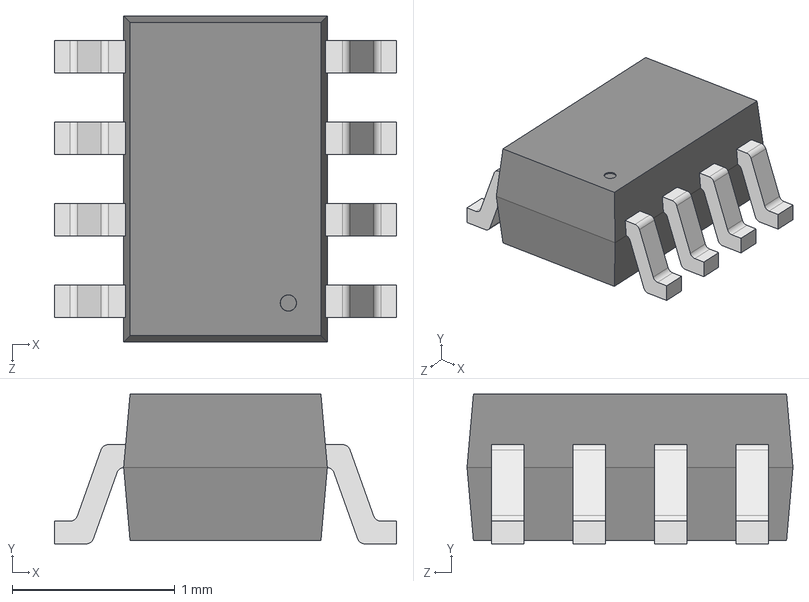
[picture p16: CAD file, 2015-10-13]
PCBA/Master_Altium_Library/3D Models/SC 70-8.step
2.10 x 0.92 x 2.00 mm

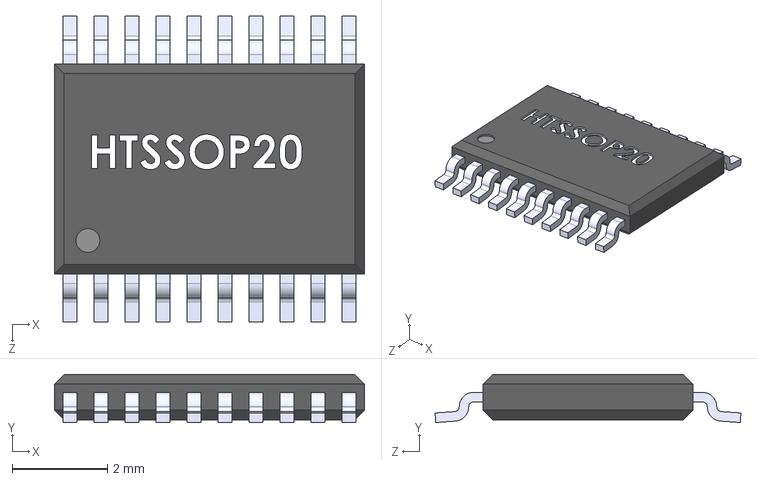
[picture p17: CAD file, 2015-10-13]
PCBA/Master_Altium_Library/3D Models/HTSSOP20.step
6.50 x 1.01 x 6.41 mm

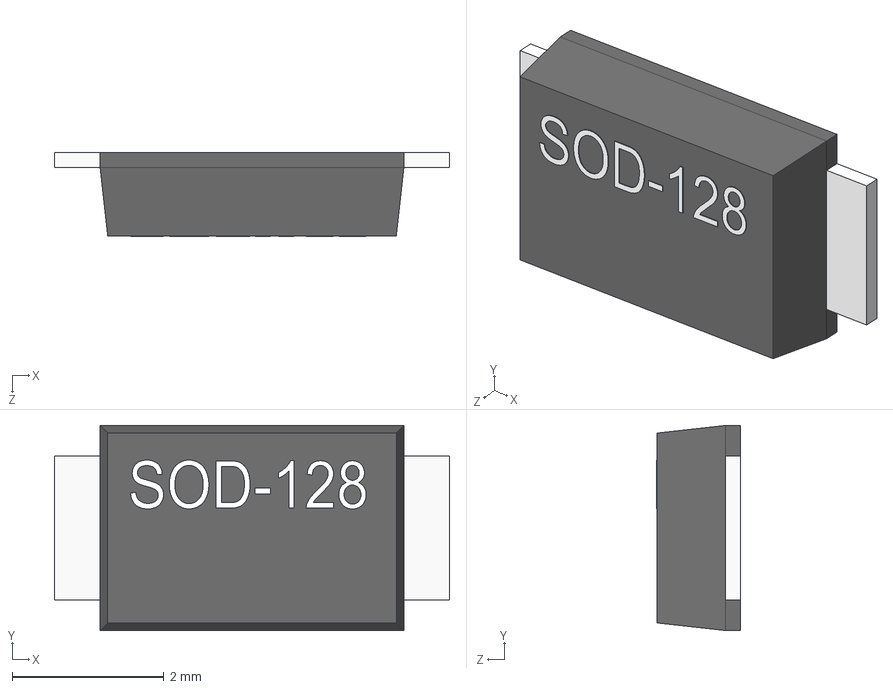
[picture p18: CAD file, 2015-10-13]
PCBA/Master_Altium_Library/3D Models/SOD-128.step
5.20 x 2.70 x 1.11 mm

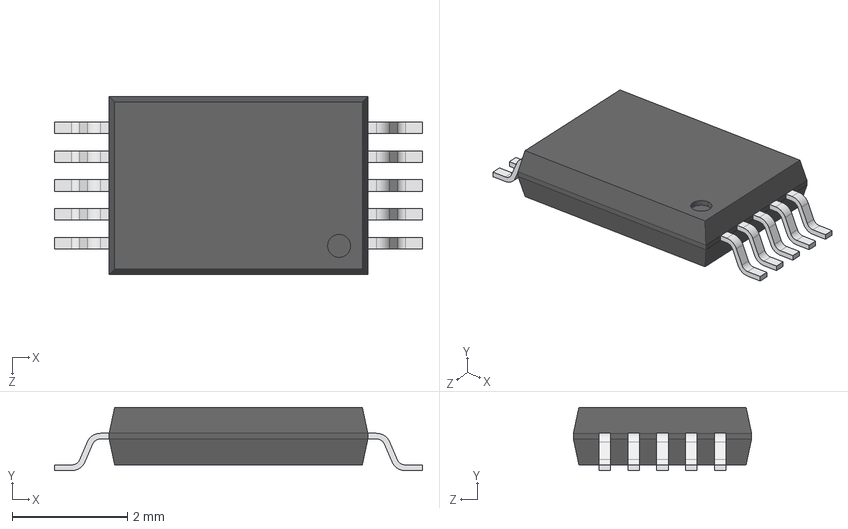
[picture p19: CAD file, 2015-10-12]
PCBA/Master_Altium_Library/3D Models/TSSOP-10 3_1x4_4.STEP
6.40 x 1.10 x 3.10 mm
User Library-TSSOP-10 3.1x4.4_body_TSSOP_TSSOP_3.1x4.5_1
User Library-TSSOP-10 3.1x4.4_pin_TSSOP_TSSOP_0.2_1 x 10

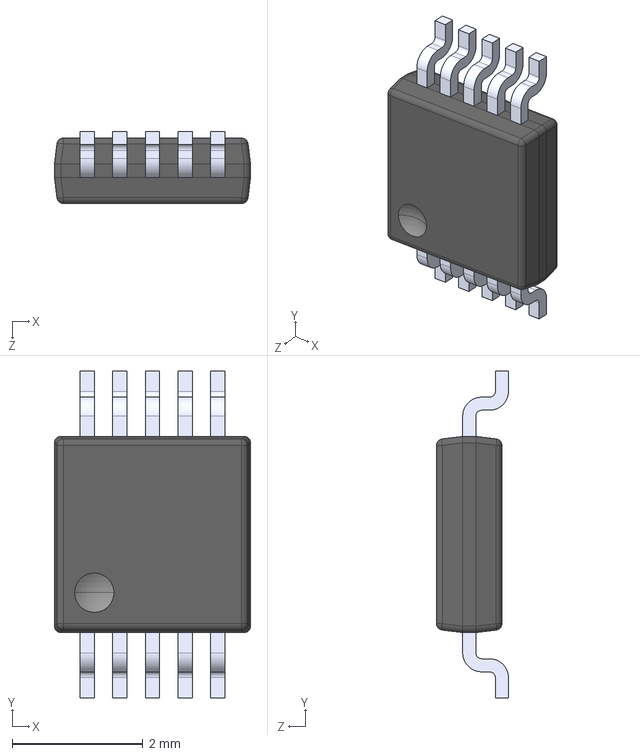
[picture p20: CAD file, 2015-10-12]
PCBA/Master_Altium_Library/3D Models/TSSOP10_3x3.step
3.00 x 5.00 x 1.10 mm

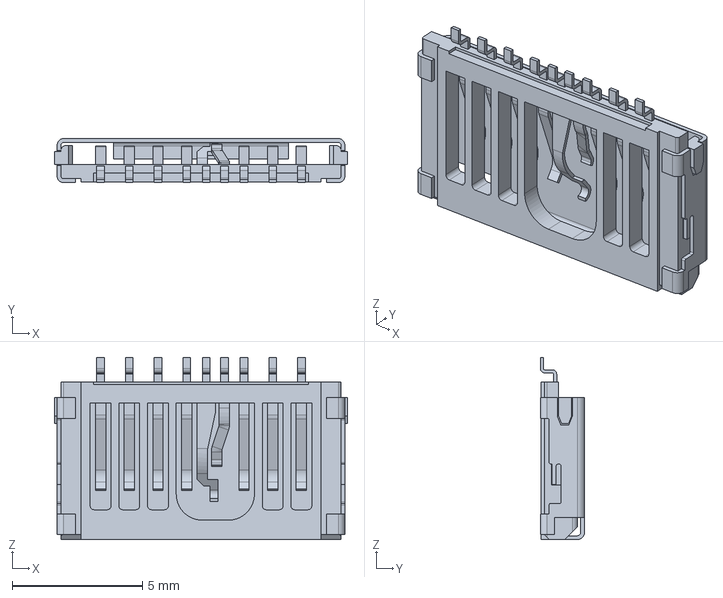
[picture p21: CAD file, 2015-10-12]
PCBA/Master_Altium_Library/3D Models/MICROSD_HOLDER_1050270001.stp
11.2 x 1.70 x 7.00 mm

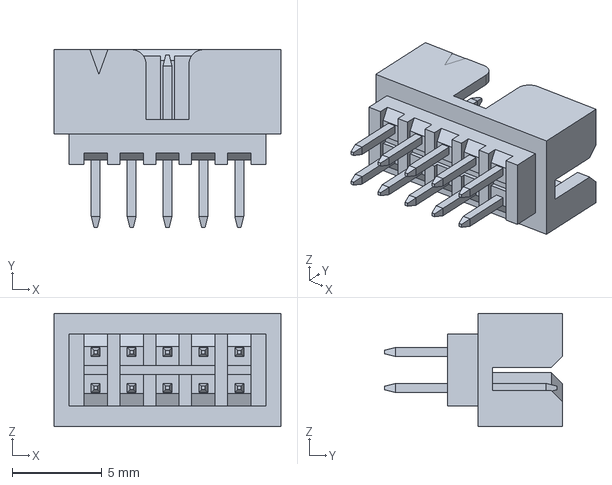
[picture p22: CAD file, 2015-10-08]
PCBA/Master_Altium_Library/3D Models/2x5 IDC Header_878311010.stp
12.7 x 9.90 x 6.30 mm

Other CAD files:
PCBA/Master_Altium_Library/3D Models/Standoff_M3x15mm.stp
PCBA/Master_Altium_Library/3D Models/QFN-32-5x5.step
PCBA/Master_Altium_Library/3D Models/PLCC-2.STEP
PCBA/Master_Altium_Library/3D Models/SMD_CAP_4x5_5.STEP
PCBA/Master_Altium_Library/3D Models/12067 Hinge.STEP
PCBA/Master_Altium_Library/3D Models/1x2 Header.stp
PCBA/Master_Altium_Library/3D Models/1x3 Header.stp
PCBA/Master_Altium_Library/3D Models/1x4 Header.stp
PCBA/Master_Altium_Library/3D Models/1x4 PicoBlade.stp
PCBA/Master_Altium_Library/3D Models/1x5 Header.stp
PCBA/Master_Altium_Library/3D Models/1x6 Header Right Angle.stp
PCBA/Master_Altium_Library/3D Models/1x6 Header.stp
PCBA/Master_Altium_Library/3D Models/1x8 Header.stp
PCBA/Master_Altium_Library/3D Models/1x9 Header.stp
PCBA/Master_Altium_Library/3D Models/2x5 Header JTAG.step
PCBA/Master_Altium_Library/3D Models/39-29-3026.stp
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

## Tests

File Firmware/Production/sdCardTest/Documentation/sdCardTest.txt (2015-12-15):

=============================================================================
List of generated methods in project: sdCardTest

This text description is generated by Processor Expert. Do not modify it.
=============================================================================

Module "clockMan1" (component fsl_clock_manager)
   - clockMan1_CLOCK_SYS_SetOutDiv1 -Sets the clock out divider1 setting(OUTDIV1).
   - clockMan1_CLOCK_SYS_GetOutDiv1 -Gets the clock out divider1 setting(OUTDIV1).
   - clockMan1_CLOCK_SYS_SetOutDiv2 -Sets the clock out divider2 setting(OUTDIV2).
   - clockMan1_CLOCK_SYS_GetOutDiv2 -Gets the clock out divider2 setting(OUTDIV2).
   - clockMan1_CLOCK_SYS_SetOutDiv3 -Sets the clock out divider3 setting(OUTDIV3).
   - clockMan1_CLOCK_SYS_GetOutDiv3 -Gets the clock out divider3 setting(OUTDIV3).
   - clockMan1_CLOCK_SYS_SetOutDiv4 -Sets the clock out divider4 setting(OUTDIV4).
   - clockMan1_CLOCK_SYS_GetOutDiv4 -Gets the clock out divider4 setting(OUTDIV4).
   - clockMan1_CLOCK_SYS_SetOutDiv -Sets the clock out dividers setting.
   - clockMan1_CLOCK_SYS_GetOutDiv -Gets the clock out dividers setting.
   - clockMan1_CLOCK_SYS_GetFlexbusFreq -Get flexbus clock frequency.
   - clockMan1_CLOCK_SYS_GetPllFllClockFreq -Get the MCGPLLCLK/MCGFLLCLK/IRC48MCLK clock frequency.
   - clockMan1_CLOCK_SYS_SetPllfllSel -Set PLL/FLL clock selection.
   - clockMan1_CLOCK_SYS_GetPllfllSel -Get PLL/FLL clock selection.
   - clockMan1_CLOCK_SYS_GetFixedFreqClockFreq -Gets the MCGFFCLK clock frequency.
   - clockMan1_CLOCK_SYS_GetInternalRefClockFreq -Get internal reference clock frequency.
   - clockMan1_CLOCK_SYS_GetExternalRefClock32kFreq -Gets the external reference 32k clock frequency.
   - clockMan1_CLOCK_SYS_SetExternalRefClock32kSrc -Set the clock selection of ERCLK32K.
   - clockMan1_CLOCK_SYS_GetExternalRefClock32kSrc -Get the clock selection of ERCLK32K.
   - clockMan1_CLOCK_SYS_GetOsc0ExternalRefClockFreq -Gets the OSC0ERCLK frequency.
   - clockMan1_CLOCK_SYS_GetOsc0ExternalRefClockUndivFreq -Gets the OSC0ERCLK_UNDIV frequency.
   - clockMan1_CLOCK_SYS_GetRtcFreq -Gets RTC input clock frequency.
   - clockMan1_CLOCK_SYS_GetRtcOutFreq -Gets RTC_CLKOUT frequency.
   - clockMan1_CLOCK_SYS_GetRtcOutSrc -Gets RTC_CLKOUT source.
   - clockMan1_CLOCK_SYS_SetRtcOutSrc -Gets RTC_CLKOUT source.
   - clockMan1_CLOCK_SYS_GetWdogFreq -Gets the watch dog clock frequency.
   - clockMan1_CLOCK_SYS_GetTraceSrc -Gets the debug trace clock source.
   - clockMan1_CLOCK_SYS_SetTraceSrc -Sets the debug trace clock source.
   - clockMan1_CLOCK_SYS_GetTraceFreq -Gets the debug trace clock frequency.
   - clockMan1_CLOCK_SYS_GetPortFilterFreq -Gets PORTx digital input filter clock frequency.
   - clockMan1_CLOCK_SYS_GetLptmrFreq -Gets LPTMRx pre-scaler/glitch filter clock frequency.
   - clockMan1_CLOCK_SYS_GetEwmFreq -Gets the clock frequency for EWM module.
   - clockMan1_CLOCK_SYS_GetFtfFreq -Gets the clock frequency for FTF module. (Flash Memory)
   - clockMan1_CLOCK_SYS_GetCrcFreq -Gets the clock frequency for CRC module.
   - clockMan1_CLOCK_SYS_GetCmpFreq -Gets the clock frequency for CMP module.
   - clockMan1_CLOCK_SYS_GetVrefFreq -Gets the clock frequency for VREF module.
   - clockMan1_CLOCK_SYS_GetPdbFreq -Gets the clock frequency for PDB module.
   - clockMan1_CLOCK_SYS_GetPitFreq -Gets the clock frequency for PIT module.
   - clockMan1_CLOCK_SYS_GetCmtFreq -Gets the clock frequency for CMT module.
   - clockMan1_CLOCK_SYS_GetUsbfsSrc -Gets the clock source for USB FS OTG module.
   - clockMan1_CLOCK_SYS_SetUsbfsSrc -Sets the clock source for USB FS OTG module.
   - clockMan1_CLOCK_SYS_GetUsbfsFreq -Gets the clock frequency for USB FS OTG module.
   - clockMan1_CLOCK_SYS_SetUsbfsDiv -Set USB FS divider setting.
   - clockMan1_CLOCK_SYS_GetUsbfsDiv -Get USB FS divider setting.
   - clockMan1_CLOCK_SYS_GetLpuartSrc -Gets the clock source for LPUART module.
   - clockMan1_CLOCK_SYS_SetLpuartSrc -Sets the clock source for LPUART module.
   - clockMan1_CLOCK_SYS_GetLpuartFreq -Gets the clock frequency for LPUART module.
   - clockMan1_CLOCK_SYS_GetSaiFreq -Gets the clock frequency for SAI.
   - clockMan1_CLOCK_SYS_GetSpiFreq -Gets the clock frequency for SPI module.
   - clockMan1_CLOCK_SYS_GetI2cFreq -Gets the clock frequency for I2C module.
   - clockMan1_CLOCK_SYS_GetAdcAltFreq -Gets ADC alternate clock frequency.
   - clockMan1_CLOCK_SYS_GetAdcAlt2Freq -Gets ADC alternate 2 clock frequency.
   - clockMan1_CLOCK_SYS_GetFtmFixedFreq -Gets FTM fixed frequency clock frequency.
   - clockMan1_CLOCK_SYS_GetFtmSystemClockFreq -Gets FTM's system clock frequency.
   - clockMan1_CLOCK_SYS_GetFtmExternalFreq -Gets FTM external clock frequency.
   - clockMan1_CLOCK_SYS_GetFtmExternalSrc -Gets FTM external clock source.
   - clockMan1_CLOCK_SYS_SetFtmExternalSrc -Sets FTM external clock source.
   - clockMan1_CLOCK_SYS_GetUartFreq -Gets the clock frequency for UART module.
   - clockMan1_CLOCK_SYS_GetGpioFreq -Gets the clock frequency for GPIO module.
   - clockMan1_CLOCK_SYS_EnableDmaClock -Enable the clock for DMA module.
   - clockMan1_CLOCK_SYS_DisableDmaClock -Disable the clock for DMA module.
   - clockMan1_CLOCK_SYS_GetDmaGateCmd -Get the the clock gate state for DMA module.
   - clockMan1_CLOCK_SYS_EnableDmamuxClock -Enable the clock for DMAMUX module.
   - clockMan1_CLOCK_SYS_DisableDmamuxClock -Disable the clock for DMAMUX module.
   - clockMan1_CLOCK_SYS_GetDmamuxGateCmd -Get the the clock gate state for DMAMUX module.
   - clockMan1_CLOCK_SYS_EnablePortClock -Enable the clock for PORT module.
   - clockMan1_CLOCK_SYS_DisablePortClock -Disable the clock for PORT module.
   - clockMan1_CLOCK_SYS_GetPortGateCmd -Get the the clock gate state for PORT module.
   - clockMan1_CLOCK_SYS_EnableEwmClock -Enable the clock for EWM module.
   - clockMan1_CLOCK_SYS_DisableEwmClock -Disable the clock for EWM module.
   - clockMan1_CLOCK_SYS_GetEwmGateCmd -Get the the clock gate state for EWM module.
   - clockMan1_CLOCK_SYS_EnableFlexbusClock -Enable the clock for FLEXBUS module.
   - clockMan1_CLOCK_SYS_DisableFlexbusClock -Disable the clock for FLEXBUS module.
   - clockMan1_CLOCK_SYS_GetFlexbusGateCmd -Get the the clock gate state for FLEXBUS module.
   - clockMan1_CLOCK_SYS_EnableFtfClock -Enable the clock for FTF module.
   - clockMan1_CLOCK_SYS_DisableFtfClock -Disable the clock for FTF module.
   - clockMan1_CLOCK_SYS_GetFtfGateCmd -Get the the clock gate state for FTF module.
   - clockMan1_CLOCK_SYS_EnableCrcClock -Enable the clock for CRC module.
   - clockMan1_CLOCK_SYS_DisableCrcClock -Disable the clock for CRC module.
   - clockMan1_CLOCK_SYS_GetCrcGateCmd -Get the the clock gate state for CRC module.
   - clockMan1_CLOCK_SYS_EnableRngaClock -Enable the clock for RNGA module.
   - clockMan1_CLOCK_SYS_DisableRngaClock -Disable the clock for RNGA module.
   - clockMan1_CLOCK_SYS_GetRngaGateCmd -Get the the clock gate state for RNGA module.
   - clockMan1_CLOCK_SYS_EnableAdcClock -Enable the clock for ADC module.
   - clockMan1_CLOCK_SYS_DisableAdcClock -Disable the clock for ADC module.
   - clockMan1_CLOCK_SYS_GetAdcGateCmd -Get the the clock gate state for ADC module.
   - clockMan1_CLOCK_SYS_EnableCmpClock -Enable the clock for CMP module.
   - clockMan1_CLOCK_SYS_DisableCmpClock -Disable the clock for CMP module.
   - clockMan1_CLOCK_SYS_GetCmpGateCmd -Get the the clock gate state for CMP module.
   - clockMan1_CLOCK_SYS_EnableDacClock -Enable the clock for DAC module.
   - clockMan1_CLOCK_SYS_DisableDacClock -Disable the clock for DAC module.
   - clockMan1_CLOCK_SYS_GetDacGateCmd -Get the the clock gate state for DAC module.
   - clockMan1_CLOCK_SYS_EnableVrefClock -Enable the clock for VREF module.
   - clockMan1_CLOCK_SYS_DisableVrefClock -Disable the clock for VREF module.
   - clockMan1_CLOCK_SYS_GetVrefGateCmd -Get the the clock gate state for VREF module.
   - clockMan1_CLOCK_SYS_EnableSaiClock -Enable the clock for SAI module.
   - clockMan1_CLOCK_SYS_DisableSaiClock -Disable the clock for SAI module.
   - clockMan1_CLOCK_SYS_GetSaiGateCmd -Get the the clock gate state for SAI module.
   - clockMan1_CLOCK_SYS_EnablePdbClock -Enable the clock for PDB module.
   - clockMan1_CLOCK_SYS_DisablePdbClock -Disable the clock for PDB module.
   - clockMan1_CLOCK_SYS_GetPdbGateCmd -Get the the clock gate state for PDB module.
   - clockMan1_CLOCK_SYS_EnableFtmClock -Enable the clock for FTM module.
   - clockMan1_CLOCK_SYS_DisableFtmClock -Disable the clock for FTM module.
   - clockMan1_CLOCK_SYS_GetFtmGateCmd -Get the the clock gate state for FTM module.
   - clockMan1_CLOCK_SYS_EnablePitClock -Enable the clock for PIT module.
   - clockMan1_CLOCK_SYS_DisablePitClock -Disable the clock for PIT module.
   - clockMan1_CLOCK_SYS_GetPitGateCmd -Get the the clock gate state for PIT module.
   - clockMan1_CLOCK_SYS_EnableLptmrClock -Enable the clock for LPTIMER module.
   - clockMan1_CLOCK_SYS_DisableLptmrClock -Disable the clock for LPTIMER module.
   - clockMan1_CLOCK_SYS_GetLptmrGateCmd -Get the the clock gate state for LPTIMER module.
   - clockMan1_CLOCK_SYS_EnableRtcClock -Enable the clock for RTC module.
   - clockMan1_CLOCK_SYS_DisableRtcClock -Disable the clock for RTC module.
   - clockMan1_CLOCK_SYS_GetRtcGateCmd -Get the the clock gate state for RTC module.
   - clockMan1_CLOCK_SYS_EnableUsbfsClock -Enable the clock for USBFS module.
   - clockMan1_CLOCK_SYS_DisableUsbfsClock -Disable the clock for USBFS module.
   - clockMan1_CLOCK_SYS_GetUsbfsGateCmd -Get the the clock gate state for USB module.
   - clockMan1_CLOCK_SYS_EnableSpiClock -Enable the clock for SPI module.
   - clockMan1_CLOCK_SYS_DisableSpiClock -Disable the clock for SPI module.
   - clockMan1_CLOCK_SYS_GetSpiGateCmd -Get the the clock gate state for SPI module.
   - clockMan1_CLOCK_SYS_EnableI2cClock -Enable the clock for I2C module.
   - clockMan1_CLOCK_SYS_DisableI2cClock -Disable the clock for I2C module.
   - clockMan1_CLOCK_SYS_GetI2cGateCmd -Get the the clock gate state for I2C module.
   - clockMan1_CLOCK_SYS_EnableUartClock -Enable the clock for UART module.
   - clockMan1_CLOCK_SYS_DisableUartClock -Disable the clock for UART module.
   - clockMan1_CLOCK_SYS_GetUartGateCmd -Get the the clock gate state for UART module.
   - clockMan1_CLOCK_SYS_EnableLpuartClock -Enable the clock for LPUART module.
   - clockMan1_CLOCK_SYS_DisableLpuartClock -Disable the clock for LPUART module.
   - clockMan1_CLOCK_SYS_GetLpuartGateCmd -Get the the clock gate state for LPUART module.
   - clockMan1_CLOCK_SYS_SetUsbExternalFreq -Set the USB external clock frequency(USB_CLKIN).
   - clockMan1_CLOCK_SYS_SetFtmExternalFreq -Set the FTM external clock frequency(FTM_CLKx).
   - clockMan1_CLOCK_SYS_Init -Installs pre-defined clock configurations.
   - clockMan1_CLOCK_SYS_UpdateConfiguration -Sets the system clock configuration according to a pre-defined structure.
   - clockMan1_CLOCK_SYS_SetConfiguration -Sets the system clock configuration.
   - clockMan1_CLOCK_SYS_GetCurrentConfiguration -Gets the current system clock configuration.
   - clockMan1_CLOCK_SYS_GetErrorCallback -Gets the callback which returns an error in the last clock switch.
   - clockMan1_CLOCK_SYS_BootToFee -Sets MCG to FEE mode during startup.
   - clockMan1_CLOCK_SYS_BootToFei -Sets MCG to FEI mode during startup.
   - clockMan1_CLOCK_SYS_BootToBlpi -Sets MCG to BLPI mode during startup.
   - clockMan1_CLOCK_SYS_BootToBlpe -Sets MCG to BLPE mode during startup.
   - clockMan1_CLOCK_SYS_BootToPee -Sets MCG to PEE mode during startup.
   - clockMan1_CLOCK_SYS_SetMcgMode -Sets MCG to a target mode.
   - clockMan1_CLOCK_SYS_SetSimConfigration -Sets the clock configuration in SIM module.
   - clockMan1_CLOCK_SYS_OscInit -Initializes the OSC.
   - clockMan1_CLOCK_SYS_OscDeinit -Deinitializes the OSC.
   - clockMan1_CLOCK_SYS_SetOscerConfigration -Configures the OSCERCLK.
   - clockMan1_CLOCK_SYS_RtcOscInit -Initializes the RTC OSC.
   - clockMan1_CLOCK_SYS_RtcOscDeinit -Deinitializes the RTC OSC.
   - clockMan1_CLOCK_SYS_GetFreq -Gets the clock frequency for a specific clock name.
   - clockMan1_CLOCK_SYS_GetCoreClockFreq -Gets the core clock frequency.
   - clockMan1_CLOCK_SYS_GetSystemClockFreq -Gets the system clock frequency.
   - clockMan1_CLOCK_SYS_GetBusClockFreq -Gets the bus clock frequency.
   - clockMan1_CLOCK_SYS_GetFlashClockFreq -Gets the flash clock frequency.
   - clockMan1_CLOCK_SYS_GetLpoClockFreq -Gets the LPO clock frequency.
   - clockMan1_CLOCK_SYS_SetSystickSrc -Sets the Systick clock source SYST_CSR[CLKSOURCE].
   - clockMan1_CLOCK_SYS_GetSystickFreq -Gets the Systick clock frequency.

Module "pin_mux"   (component PinSettings)
   - pin_mux_hardware_init -This method configures registers according to settings of routing and electrical features. It 
                provides pin initialization for selected pins during processor start-up. Selected pins are either user selected 
                pins or pins selected in pin properties in components.  Only pins of devices  enabled for auto initialization 
                are handled within this method.
   - pin_mux_init_jtag_pins -JTAG method configures registers according to settings  of routing and electrical features. This 
                method is enabled only if any pin of corresponding peripheral type is selected. Selected pins are either user 
                selected pins or pins selected in pin items in components. Call this method code to route desired pins into 
                JTAG peripheral.
   - pin_mux_deinit_jtag_pins -JTAG method de-configures muxing registers according to settings of routing. This method is 
                enabled only if any pin of corresponding peripheral type is selected. Selected pins are either user selected 
                pins or pins selected in pin items in components. Call this method code to un-route desired pins into JTAG 
                peripheral.
   - pin_mux_init_lpuart_pins -LPUART method configures registers according to settings  of routing and electrical features. 
                This method is enabled only if any pin of corresponding peripheral type is selected. Selected pins are either 
                user selected pins or pins selected in pin items in components. Call this method code to route desired pins 
                into LPUART0 peripheral.
   - pin_mux_deinit_lpuart_pins -LPUART method de-configures muxing registers according to settings of routing. This method is 
                enabled only if any pin of corresponding peripheral type is selected. Selected pins are either user selected 
                pins or pins selected in pin items in components. Call this method code to un-route desired pins into LPUART0 
                peripheral.
   - pin_mux_init_spi_pins -SPI method configures registers according to settings  of routing and electrical features. This 
                method is enabled only if any pin of corresponding peripheral type is selected. Selected pins are either user 
                selected pins or pins selected in pin items in components. Call this method code to route desired pins into 
                SPI0, SPI1 peripherals.
   - pin_mux_deinit_spi_pins -SPI method de-configures muxing registers according to settings of routing. This method is 
                enabled only if any pin of corresponding peripheral type is selected. Selected pins are either user selected 
                pins or pins selected in pin items in components. Call this method code to un-route desired pins into SPI0, 
                SPI1 peripherals.
   - pin_mux_init_tpiu_pins -TPIU method configures registers according to settings  of routing and electrical features. This 
                method is enabled only if any pin of corresponding peripheral type is selected. Selected pins are either user 
                selected pins or pins selected in pin items in components. Call this method code to route desired pins into 
                TPIU peripheral.
   - pin_mux_deinit_tpiu_pins -TPIU method de-configures muxing registers according to settings of routing. This method is 
                enabled only if any pin of corresponding peripheral type is selected. Selected pins are either user selected 
                pins or pins selected in pin items in components. Call this method code to un-route desired pins into TPIU 
                peripheral.

Module "osa1"      (component fsl_os_abstraction)
   - osa1_OSA_SemaCreate -Creates a semaphore with a given value.
   - osa1_OSA_SemaWait -Pending a semaphore with timeout.
   - osa1_OSA_SemaPost -Signals for someone waiting on the semaphore to wake up.
   - osa1_OSA_SemaDestroy -Destroys a previously created semaphore.
   - osa1_OSA_MutexCreate -Create an unlocked mutex.
   - osa1_OSA_MutexLock -Waits for a mutex and locks it.
   - osa1_OSA_MutexUnlock -Unlocks a previously locked mutex.
   - osa1_OSA_MutexDestroy -Destroys a previously created mutex.
   - osa1_OSA_EventCreate -Initializes an event object with all flags cleared.
   - osa1_OSA_EventWait -Waits for specified event flags to be set.
   - osa1_OSA_EventSet -Sets one or more event flags.
   - osa1_OSA_EventClear -Clears one or more flags.
   - osa1_OSA_EventGetFlags -Gets event flags status.
   - osa1_OSA_EventDestroy -Destroys a previously created event object.
   - osa1_OSA_TaskCreate -Creates a task.
   - osa1_OSA_TaskDestroy -Destroys a previously created task.
   - osa1_OSA_TaskYield -Puts the active task to the end of scheduler's queue.
   - osa1_OSA_TaskGetHandler -Gets the handler of active task.
   - osa1_OSA_TaskGetPriority -Gets the priority of a task.
   - osa1_OSA_TaskSetPriority -Sets the priority of a task.
   - osa1_OSA_MsgQCreate -Initializes a message queue.
   - osa1_OSA_MsgQPut -Puts a message at the end of the queue.
   - osa1_OSA_MsgQGet -Reads and remove a message at the head of the queue.
   - osa1_OSA_MsgQDestroy -Destroys a previously created queue.
   - osa1_OSA_MemAlloc -Reserves the requested amount of memory in bytes.
   - osa1_OSA_MemAllocZero -Reserves the requested amount of memory in bytes and initializes it to 0.
   - osa1_OSA_MemFree -Releases the memory previously reserved.
   - osa1_OSA_TimeDelay -Delays execution for a number of milliseconds.
   - osa1_OSA_TimeGetMsec -Gets the current time since system boot in milliseconds.
   - osa1_OSA_InstallIntHandler -Installs the interrupt handler.
   - osa1_OSA_EnterCritical -Enters the critical section to ensure some code is not preempted.
   - osa1_OSA_ExitCritical -Exits the critical section.
   - osa1_OSA_Init -Initializes the RTOS services.
   - osa1_OSA_Start -Starts the RTOS.

Module "intMan1"   (component fsl_interrupt_manager)
   - intMan1_INT_SYS_InstallHandler -Installs an interrupt handler routine for a given IRQ number.
   - intMan1_INT_SYS_EnableIRQ -Enables an interrupt for a given IRQ number.
   - intMan1_INT_SYS_DisableIRQ -Disables an interrupt for a given IRQ number.
   - intMan1_INT_SYS_EnableIRQGlobal -Enables system interrupt.
   - intMan1_INT_SYS_DisableIRQGlobal -Disable system interrupt.

Module "memoryCard1" (component fsl_sdcard)
   - memoryCard1_SDSPI_DRV_Init -Initializes the card on a specific SPI instance.
   - memoryCard1_SDSPI_DRV_ReadBlocks -Reads blocks from the specific card.
   - memoryCard1_SDSPI_DRV_WriteBlocks -Writes blocks of data to the specific card.
   - memoryCard1_SDSPI_DRV_CheckReadOnly -Checks whether the card is write-protected.
   - memoryCard1_SDSPI_DRV_Shutdown -Deinitializes the card.
   - memoryCard1_SDCARD_DRV_Init -Initializes the card on a specific host controller.
   - memoryCard1_SDCARD_DRV_ReadBlocks -Reads blocks from the specific card.
   - memoryCard1_SDCARD_DRV_WriteBlocks -Writes blocks of data to the specific card.
   - memoryCard1_SDCARD_DRV_EraseBlocks -Erases blocks of the specific card.
   - memoryCard1_SDCARD_DRV_CheckReadOnly -Checks whether the card is write-protected.
   - memoryCard1_SDCARD_DRV_Shutdown -Deinitializes the card.

Module "DbgCs1"    (component fsl_debug_console)
   - DbgCs1_DbgConsole_Init -Init the UART/LPUART used for debug messages.
   - DbgCs1_DbgConsole_DeInit -Deinit the UART/LPUART used for debug messages.
   - DbgCs1_debug_printf -Prints formatted output to the standard output stream.
   - DbgCs1_debug_putchar -Writes a character to stdout.
   - DbgCs1_debug_scanf -Reads formatted data from the standard input stream.
   - DbgCs1_debug_getchar -Reads a character from standard input.

Module "Cpu"       (component MK22FN512LL12_4SDK)
   - Cpu_SystemInit -This method configures the oscillator (PLL) that is part of the microcontroller device. SystemInit is 
                called from startup_device file.
   - Cpu_SystemCoreClockUpdate -SystemCoreClockUpdate evaluates the clock register settings and calculates the current core 
                clock.

===================================================================================

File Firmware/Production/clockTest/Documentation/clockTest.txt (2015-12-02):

=============================================================================
List of generated methods in project: clockTest

This text description is generated by Processor Expert. Do not modify it.
=============================================================================

Module "clockMan1" (component fsl_clock_manager)
   - clockMan1_CLOCK_SYS_SetOutDiv1 -Sets the clock out divider1 setting(OUTDIV1).
   - clockMan1_CLOCK_SYS_GetOutDiv1 -Gets the clock out divider1 setting(OUTDIV1).
   - clockMan1_CLOCK_SYS_SetOutDiv2 -Sets the clock out divider2 setting(OUTDIV2).
   - clockMan1_CLOCK_SYS_GetOutDiv2 -Gets the clock out divider2 setting(OUTDIV2).
   - clockMan1_CLOCK_SYS_SetOutDiv3 -Sets the clock out divider3 setting(OUTDIV3).
   - clockMan1_CLOCK_SYS_GetOutDiv3 -Gets the clock out divider3 setting(OUTDIV3).
   - clockMan1_CLOCK_SYS_SetOutDiv4 -Sets the clock out divider4 setting(OUTDIV4).
   - clockMan1_CLOCK_SYS_GetOutDiv4 -Gets the clock out divider4 setting(OUTDIV4).
   - clockMan1_CLOCK_SYS_SetOutDiv -Sets the clock out dividers setting.
   - clockMan1_CLOCK_SYS_GetOutDiv -Gets the clock out dividers setting.
   - clockMan1_CLOCK_SYS_GetFlexbusFreq -Get flexbus clock frequency.
   - clockMan1_CLOCK_SYS_GetPllFllClockFreq -Get the MCGPLLCLK/MCGFLLCLK/IRC48MCLK clock frequency.
   - clockMan1_CLOCK_SYS_SetPllfllSel -Set PLL/FLL clock selection.
   - clockMan1_CLOCK_SYS_GetPllfllSel -Get PLL/FLL clock selection.
   - clockMan1_CLOCK_SYS_GetFixedFreqClockFreq -Gets the MCGFFCLK clock frequency.
   - clockMan1_CLOCK_SYS_GetInternalRefClockFreq -Get internal reference clock frequency.
   - clockMan1_CLOCK_SYS_GetExternalRefClock32kFreq -Gets the external reference 32k clock frequency.
   - clockMan1_CLOCK_SYS_SetExternalRefClock32kSrc -Set the clock selection of ERCLK32K.
   - clockMan1_CLOCK_SYS_GetExternalRefClock32kSrc -Get the clock selection of ERCLK32K.
   - clockMan1_CLOCK_SYS_GetOsc0ExternalRefClockFreq -Gets the OSC0ERCLK frequency.
   - clockMan1_CLOCK_SYS_GetOsc0ExternalRefClockUndivFreq -Gets the OSC0ERCLK_UNDIV frequency.
   - clockMan1_CLOCK_SYS_GetRtcFreq -Gets RTC input clock frequency.
   - clockMan1_CLOCK_SYS_GetRtcOutFreq -Gets RTC_CLKOUT frequency.
   - clockMan1_CLOCK_SYS_GetRtcOutSrc -Gets RTC_CLKOUT source.
   - clockMan1_CLOCK_SYS_SetRtcOutSrc -Gets RTC_CLKOUT source.
   - clockMan1_CLOCK_SYS_GetWdogFreq -Gets the watch dog clock frequency.
   - clockMan1_CLOCK_SYS_GetTraceSrc -Gets the debug trace clock source.
   - clockMan1_CLOCK_SYS_SetTraceSrc -Sets the debug trace clock source.
   - clockMan1_CLOCK_SYS_GetTraceFreq -Gets the debug trace clock frequency.
   - clockMan1_CLOCK_SYS_GetPortFilterFreq -Gets PORTx digital input filter clock frequency.
   - clockMan1_CLOCK_SYS_GetLptmrFreq -Gets LPTMRx pre-scaler/glitch filter clock frequency.
   - clockMan1_CLOCK_SYS_GetEwmFreq -Gets the clock frequency for EWM module.
   - clockMan1_CLOCK_SYS_GetFtfFreq -Gets the clock frequency for FTF module. (Flash Memory)
   - clockMan1_CLOCK_SYS_GetCrcFreq -Gets the clock frequency for CRC module.
   - clockMan1_CLOCK_SYS_GetCmpFreq -Gets the clock frequency for CMP module.
   - clockMan1_CLOCK_SYS_GetVrefFreq -Gets the clock frequency for VREF module.
   - clockMan1_CLOCK_SYS_GetPdbFreq -Gets the clock frequency for PDB module.
   - clockMan1_CLOCK_SYS_GetPitFreq -Gets the clock frequency for PIT module.
   - clockMan1_CLOCK_SYS_GetCmtFreq -Gets the clock frequency for CMT module.
   - clockMan1_CLOCK_SYS_GetUsbfsSrc -Gets the clock source for USB FS OTG module.
   - clockMan1_CLOCK_SYS_SetUsbfsSrc -Sets the clock source for USB FS OTG module.
   - clockMan1_CLOCK_SYS_GetUsbfsFreq -Gets the clock frequency for USB FS OTG module.
   - clockMan1_CLOCK_SYS_SetUsbfsDiv -Set USB FS divider setting.
   - clockMan1_CLOCK_SYS_GetUsbfsDiv -Get USB FS divider setting.
   - clockMan1_CLOCK_SYS_GetLpuartSrc -Gets the clock source for LPUART module.
   - clockMan1_CLOCK_SYS_SetLpuartSrc -Sets the clock source for LPUART module.
   - clockMan1_CLOCK_SYS_GetLpuartFreq -Gets the clock frequency for LPUART module.
   - clockMan1_CLOCK_SYS_GetSaiFreq -Gets the clock frequency for SAI.
   - clockMan1_CLOCK_SYS_GetSpiFreq -Gets the clock frequency for SPI module.
   - clockMan1_CLOCK_SYS_GetI2cFreq -Gets the clock frequency for I2C module.
   - clockMan1_CLOCK_SYS_GetAdcAltFreq -Gets ADC alternate clock frequency.
   - clockMan1_CLOCK_SYS_GetAdcAlt2Freq -Gets ADC alternate 2 clock frequency.
   - clockMan1_CLOCK_SYS_GetFtmFixedFreq -Gets FTM fixed frequency clock frequency.
   - clockMan1_CLOCK_SYS_GetFtmSystemClockFreq -Gets FTM's system clock frequency.
   - clockMan1_CLOCK_SYS_GetFtmExternalFreq -Gets FTM external clock frequency.
   - clockMan1_CLOCK_SYS_GetFtmExternalSrc -Gets FTM external clock source.
   - clockMan1_CLOCK_SYS_SetFtmExternalSrc -Sets FTM external clock source.
   - clockMan1_CLOCK_SYS_GetUartFreq -Gets the clock frequency for UART module.
   - clockMan1_CLOCK_SYS_GetGpioFreq -Gets the clock frequency for GPIO module.
   - clockMan1_CLOCK_SYS_EnableDmaClock -Enable the clock for DMA module.
   - clockMan1_CLOCK_SYS_DisableDmaClock -Disable the clock for DMA module.
   - clockMan1_CLOCK_SYS_GetDmaGateCmd -Get the the clock gate state for DMA module.
   - clockMan1_CLOCK_SYS_EnableDmamuxClock -Enable the clock for DMAMUX module.
   - clockMan1_CLOCK_SYS_DisableDmamuxClock -Disable the clock for DMAMUX module.
   - clockMan1_CLOCK_SYS_GetDmamuxGateCmd -Get the the clock gate state for DMAMUX module.
   - clockMan1_CLOCK_SYS_EnablePortClock -Enable the clock for PORT module.
   - clockMan1_CLOCK_SYS_DisablePortClock -Disable the clock for PORT module.
   - clockMan1_CLOCK_SYS_GetPortGateCmd -Get the the clock gate state for PORT module.
   - clockMan1_CLOCK_SYS_EnableEwmClock -Enable the clock for EWM module.
   - clockMan1_CLOCK_SYS_DisableEwmClock -Disable the clock for EWM module.
   - clockMan1_CLOCK_SYS_GetEwmGateCmd -Get the the clock gate state for EWM module.
   - clockMan1_CLOCK_SYS_EnableFlexbusClock -Enable the clock for FLEXBUS module.
   - clockMan1_CLOCK_SYS_DisableFlexbusClock -Disable the clock for FLEXBUS module.
   - clockMan1_CLOCK_SYS_GetFlexbusGateCmd -Get the the clock gate state for FLEXBUS module.
   - clockMan1_CLOCK_SYS_EnableFtfClock -Enable the clock for FTF module.
   - clockMan1_CLOCK_SYS_DisableFtfClock -Disable the clock for FTF module.
   - clockMan1_CLOCK_SYS_GetFtfGateCmd -Get the the clock gate state for FTF module.
   - clockMan1_CLOCK_SYS_EnableCrcClock -Enable the clock for CRC module.
   - clockMan1_CLOCK_SYS_DisableCrcClock -Disable the clock for CRC module.
   - clockMan1_CLOCK_SYS_GetCrcGateCmd -Get the the clock gate state for CRC module.
   - clockMan1_CLOCK_SYS_EnableRngaClock -Enable the clock for RNGA module.
   - clockMan1_CLOCK_SYS_DisableRngaClock -Disable the clock for RNGA module.
   - clockMan1_CLOCK_SYS_GetRngaGateCmd -Get the the clock gate state for RNGA module.
   - clockMan1_CLOCK_SYS_EnableAdcClock -Enable the clock for ADC module.
   - clockMan1_CLOCK_SYS_DisableAdcClock -Disable the clock for ADC module.
   - clockMan1_CLOCK_SYS_GetAdcGateCmd -Get the the clock gate state for ADC module.
   - clockMan1_CLOCK_SYS_EnableCmpClock -Enable the clock for CMP module.
   - clockMan1_CLOCK_SYS_DisableCmpClock -Disable the clock for CMP module.
   - clockMan1_CLOCK_SYS_GetCmpGateCmd -Get the the clock gate state for CMP module.
   - clockMan1_CLOCK_SYS_EnableDacClock -Enable the clock for DAC module.
   - clockMan1_CLOCK_SYS_DisableDacClock -Disable the clock for DAC module.
   - clockMan1_CLOCK_SYS_GetDacGateCmd -Get the the clock gate state for DAC module.
   - clockMan1_CLOCK_SYS_EnableVrefClock -Enable the clock for VREF module.
   - clockMan1_CLOCK_SYS_DisableVrefClock -Disable the clock for VREF module.
   - clockMan1_CLOCK_SYS_GetVrefGateCmd -Get the the clock gate state for VREF module.
   - clockMan1_CLOCK_SYS_EnableSaiClock -Enable the clock for SAI module.
   - clockMan1_CLOCK_SYS_DisableSaiClock -Disable the clock for SAI module.
   - clockMan1_CLOCK_SYS_GetSaiGateCmd -Get the the clock gate state for SAI module.
   - clockMan1_CLOCK_SYS_EnablePdbClock -Enable the clock for PDB module.
   - clockMan1_CLOCK_SYS_DisablePdbClock -Disable the clock for PDB module.
   - clockMan1_CLOCK_SYS_GetPdbGateCmd -Get the the clock gate state for PDB module.
   - clockMan1_CLOCK_SYS_EnableFtmClock -Enable the clock for FTM module.
   - clockMan1_CLOCK_SYS_DisableFtmClock -Disable the clock for FTM module.
   - clockMan1_CLOCK_SYS_GetFtmGateCmd -Get the the clock gate state for FTM module.
   - clockMan1_CLOCK_SYS_EnablePitClock -Enable the clock for PIT module.
   - clockMan1_CLOCK_SYS_DisablePitClock -Disable the clock for PIT module.
   - clockMan1_CLOCK_SYS_GetPitGateCmd -Get the the clock gate state for PIT module.
   - clockMan1_CLOCK_SYS_EnableLptmrClock -Enable the clock for LPTIMER module.
   - clockMan1_CLOCK_SYS_DisableLptmrClock -Disable the clock for LPTIMER module.
   - clockMan1_CLOCK_SYS_GetLptmrGateCmd -Get the the clock gate state for LPTIMER module.
   - clockMan1_CLOCK_SYS_EnableRtcClock -Enable the clock for RTC module.
   - clockMan1_CLOCK_SYS_DisableRtcClock -Disable the clock for RTC module.
   - clockMan1_CLOCK_SYS_GetRtcGateCmd -Get the the clock gate state for RTC module.
   - clockMan1_CLOCK_SYS_EnableUsbfsClock -Enable the clock for USBFS module.
   - clockMan1_CLOCK_SYS_DisableUsbfsClock -Disable the clock for USBFS module.
   - clockMan1_CLOCK_SYS_GetUsbfsGateCmd -Get the the clock gate state for USB module.
   - clockMan1_CLOCK_SYS_EnableSpiClock -Enable the clock for SPI module.
   - clockMan1_CLOCK_SYS_DisableSpiClock -Disable the clock for SPI module.
   - clockMan1_CLOCK_SYS_GetSpiGateCmd -Get the the clock gate state for SPI module.
   - clockMan1_CLOCK_SYS_EnableI2cClock -Enable the clock for I2C module.
   - clockMan1_CLOCK_SYS_DisableI2cClock -Disable the clock for I2C module.
   - clockMan1_CLOCK_SYS_GetI2cGateCmd -Get the the clock gate state for I2C module.
   - clockMan1_CLOCK_SYS_EnableUartClock -Enable the clock for UART module.
   - clockMan1_CLOCK_SYS_DisableUartClock -Disable the clock for UART module.
   - clockMan1_CLOCK_SYS_GetUartGateCmd -Get the the clock gate state for UART module.
   - clockMan1_CLOCK_SYS_EnableLpuartClock -Enable the clock for LPUART module.
   - clockMan1_CLOCK_SYS_DisableLpuartClock -Disable the clock for LPUART module.
   - clockMan1_CLOCK_SYS_GetLpuartGateCmd -Get the the clock gate state for LPUART module.
   - clockMan1_CLOCK_SYS_SetUsbExternalFreq -Set the USB external clock frequency(USB_CLKIN).
   - clockMan1_CLOCK_SYS_SetFtmExternalFreq -Set the FTM external clock frequency(FTM_CLKx).
   - clockMan1_CLOCK_SYS_Init -Installs pre-defined clock configurations.
   - clockMan1_CLOCK_SYS_UpdateConfiguration -Sets the system clock configuration according to a pre-defined structure.
   - clockMan1_CLOCK_SYS_SetConfiguration -Sets the system clock configuration.
   - clockMan1_CLOCK_SYS_GetCurrentConfiguration -Gets the current system clock configuration.
   - clockMan1_CLOCK_SYS_GetErrorCallback -Gets the callback which returns an error in the last clock switch.
   - clockMan1_CLOCK_SYS_BootToFee -Sets MCG to FEE mode during startup.
   - clockMan1_CLOCK_SYS_BootToFei -Sets MCG to FEI mode during startup.
   - clockMan1_CLOCK_SYS_BootToBlpi -Sets MCG to BLPI mode during startup.
   - clockMan1_CLOCK_SYS_BootToBlpe -Sets MCG to BLPE mode during startup.
   - clockMan1_CLOCK_SYS_BootToPee -Sets MCG to PEE mode during startup.
   - clockMan1_CLOCK_SYS_SetMcgMode -Sets MCG to a target mode.
   - clockMan1_CLOCK_SYS_SetSimConfigration -Sets the clock configuration in SIM module.
   - clockMan1_CLOCK_SYS_OscInit -Initializes the OSC.
   - clockMan1_CLOCK_SYS_OscDeinit -Deinitializes the OSC.
   - clockMan1_CLOCK_SYS_SetOscerConfigration -Configures the OSCERCLK.
   - clockMan1_CLOCK_SYS_RtcOscInit -Initializes the RTC OSC.
   - clockMan1_CLOCK_SYS_RtcOscDeinit -Deinitializes the RTC OSC.
   - clockMan1_CLOCK_SYS_GetFreq -Gets the clock frequency for a specific clock name.
   - clockMan1_CLOCK_SYS_GetCoreClockFreq -Gets the core clock frequency.
   - clockMan1_CLOCK_SYS_GetSystemClockFreq -Gets the system clock frequency.
   - clockMan1_CLOCK_SYS_GetBusClockFreq -Gets the bus clock frequency.
   - clockMan1_CLOCK_SYS_GetFlashClockFreq -Gets the flash clock frequency.
   - clockMan1_CLOCK_SYS_GetLpoClockFreq -Gets the LPO clock frequency.
   - clockMan1_CLOCK_SYS_SetSystickSrc -Sets the Systick clock source SYST_CSR[CLKSOURCE].
   - clockMan1_CLOCK_SYS_GetSystickFreq -Gets the Systick clock frequency.

Module "pin_mux"   (component PinSettings)
   - pin_mux_hardware_init -This method configures registers according to settings of routing and electrical features. It 
                provides pin initialization for selected pins during processor start-up. Selected pins are either user selected 
                pins or pins selected in pin properties in components.  Only pins of devices  enabled for auto initialization 
                are handled within this method.
   - pin_mux_init_gpio_pins -GPIO method configures registers according to settings  of routing and electrical features. This 
                method is enabled only if any pin of corresponding peripheral type is selected. Selected pins are either user 
                selected pins or pins selected in pin items in components. Call this method code to route desired pins into PTA,
                PTB, PTC, PTD, PTE peripherals.
   - pin_mux_deinit_gpio_pins -GPIO method de-configures muxing registers according to settings of routing. This method is 
                enabled only if any pin of corresponding peripheral type is selected. Selected pins are either user selected 
                pins or pins selected in pin items in components. Call this method code to un-route desired pins into PTA, PTB, 
                PTC, PTD, PTE peripherals.
   - pin_mux_init_jtag_pins -JTAG method configures registers according to settings  of routing and electrical features. This 
                method is enabled only if any pin of corresponding peripheral type is selected. Selected pins are either user 
                selected pins or pins selected in pin items in components. Call this method code to route desired pins into 
                JTAG peripheral.
   - pin_mux_deinit_jtag_pins -JTAG method de-configures muxing registers according to settings of routing. This method is 
                enabled only if any pin of corresponding peripheral type is selected. Selected pins are either user selected 
                pins or pins selected in pin items in components. Call this method code to un-route desired pins into JTAG 
                peripheral.
   - pin_mux_init_llwu_pins -LLWU method configures registers according to settings  of routing and electrical features. This 
                method is enabled only if any pin of corresponding peripheral type is selected. Selected pins are either user 
                selected pins or pins selected in pin items in components. Call this method code to route desired pins into 
                LLWU peripheral.
   - pin_mux_deinit_llwu_pins -LLWU method de-configures muxing registers according to settings of routing. This method is 
                enabled only if any pin of corresponding peripheral type is selected. Selected pins are either user selected 
                pins or pins selected in pin items in components. Call this method code to un-route desired pins into LLWU 
                peripheral.
   - pin_mux_init_osc_pins -OSC method configures registers according to settings  of routing and electrical features. This 
                method is enabled only if any pin of corresponding peripheral type is selected. Selected pins are either user 
                selected pins or pins selected in pin items in components. Call this method code to route desired pins into OSC 
                peripheral.
   - pin_mux_deinit_osc_pins -OSC method de-configures muxing registers according to settings of routing. This method is 
                enabled only if any pin of corresponding peripheral type is selected. Selected pins are either user selected 
                pins or pins selected in pin items in components. Call this method code to un-route desired pins into OSC 
                peripheral.
   - pin_mux_init_sim_pins -SIM method configures registers according to settings  of routing and electrical features. This 
                method is enabled only if any pin of corresponding peripheral type is selected. Selected pins are either user 
                selected pins or pins selected in pin items in components. Call this method code to route desired pins into SIM 
                peripheral.
   - pin_mux_deinit_sim_pins -SIM method de-configures muxing registers according to settings of routing. This method is 
                enabled only if any pin of corresponding peripheral type is selected. Selected pins are either user selected 
                pins or pins selected in pin items in components. Call this method code to un-route desired pins into SIM 
                peripheral.
   - pin_mux_init_tpiu_pins -TPIU method configures registers according to settings  of routing and electrical features. This 
                method is enabled only if any pin of corresponding peripheral type is selected. Selected pins are either user 
                selected pins or pins selected in pin items in components. Call this method code to route desired pins into 
                TPIU peripheral.
   - pin_mux_deinit_tpiu_pins -TPIU method de-configures muxing registers according to settings of routing. This method is 
                enabled only if any pin of corresponding peripheral type is selected. Selected pins are either user selected 
                pins or pins selected in pin items in components. Call this method code to un-route desired pins into TPIU 
                peripheral.
   - pin_mux_init_uart_pins -UART method configures registers according to settings  of routing and electrical features. This 
                method is enabled only if any pin of corresponding peripheral type is selected. Selected pins are either user 
                selected pins or pins selected in pin items in components. Call this method code to route desired pins into 
                UART0, UART1, UART2 peripherals.
   - pin_mux_deinit_uart_pins -UART method de-configures muxing registers according to settings of routing. This method is 
                enabled only if any pin of corresponding peripheral type is selected. Selected pins are either user selected 
                pins or pins selected in pin items in components. Call this method code to un-route desired pins into UART0, 
                UART1, UART2 peripherals.
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

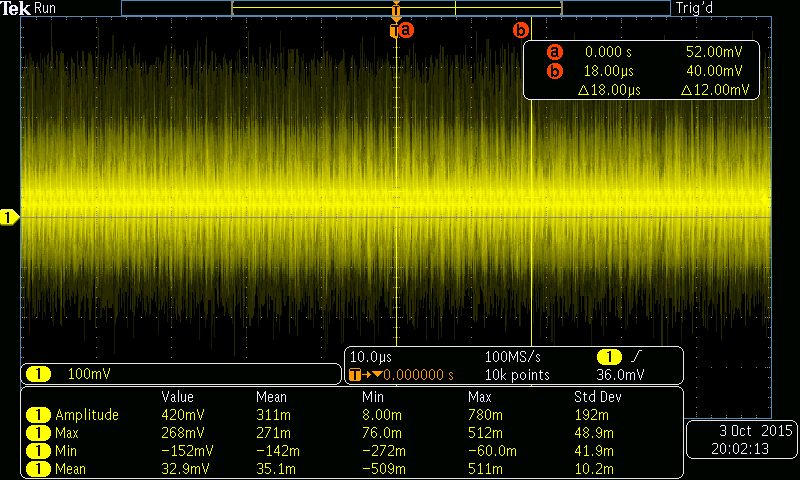
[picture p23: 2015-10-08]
Documentation/Nimbelink Device Power Profile/Current Shunt (Voltage) Measurement 4.png

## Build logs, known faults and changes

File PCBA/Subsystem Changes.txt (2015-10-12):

Subsystem Changes
Ross Harvey
10-11-2015

Power
1. Changed voltage range Comparator
	Reason: Hard to find, expensive, and large package.
2. Switched Zener diode to a precision reference	
	Reason:  Zeners are very imprecise.  Not used for references.
3. Changed PFET pulldown FETs to NX3020
	Reson: Size reduction

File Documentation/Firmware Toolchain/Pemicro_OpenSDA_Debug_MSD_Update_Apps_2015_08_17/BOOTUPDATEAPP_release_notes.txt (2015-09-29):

December 11th, 2013
Bootloader Update Application, Version 1.11

This application will update the bootloader portion of the OpenSDA software platform to version 1.11. The current version of bootloader software can be seen by entering bootloader mode and running the SDA_INFO.HTM file. It is recommended to only update the bootloader software if there is some reason (such as allowing enumeration under Linux).

To update Bootloader please follow these steps:

1. Enter bootloader mode (generally by holding down the target reset button on the OpenSDA board and plugging in the USB connection).

2. Drag and drop the BOOTUPDATEAPP.SDA file to the root directory of the Bootloader "drive".

3. Unplug and replug your OpenSDA board to initiate Bootloader update.  Bootloader update should take less than 15 seconds (probably averages 3 seconds).

4. Once update is complete, OpenSDA will automatically enumerate in Bootloader mode and green status LED will go on blinking with .5 second on/off intervals. 

5. Run the SDA_INFO.HTM file in the root directory of the Bootloader "drive".

IMPORTANT: Please do not unplug OpenSDA while Bootloader is updating. 

WARNING: If you are running Microboot v1.03 or older on a FRDM-KL25Z board, there is a scenario where interrupting the firmware update at a very specific spot during the update process will cause the board to become secure and unusable. It is very unlikely that this would occur as the entire update process takes about a second and this problem would occur only when replacing one of the many sectors in the flash which are reprogrammed. This flaw was fixed in Microboot v1.03. In order to fix the board, it would have to be shipped to P&E to be recovered. 

BOOTUPDATEAPP with Bootloader v1.11 fixes the following issues:

v1.05 Fixed binary files download to bootloader. Wrong address was used (0x0000 instead of 0x8000)
      Fixed led not coming on upon an error
v1.07 Added Bootloader support for Linux
v1.08 Future feature additions (undocumented)
v1.09 Disabled RESET_B after usage to remove current draw from target MCU
v1.10 New Bootloader code supports MAC and Linux
v1.11 Added Windows 8.1 support

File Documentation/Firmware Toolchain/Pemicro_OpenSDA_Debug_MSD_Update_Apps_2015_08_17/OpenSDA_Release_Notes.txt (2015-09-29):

The OpenSDA contains firmware applications for the OpenSDA hardware platform.

Changes:
DEBUG version 1.08 for MBED:
  - Adds universal OpenSDA Debug firmware that is capable of running on top of OpenSDA board programmed with 
    MBED Bootloader

DEBUG_OpenSDA_for_MBED_Bootloader_by_Pemicro_v108.bin

MSD - DEBUG version 1.17
  - Includes sectore erase support, instead of mass erase for TWR-KV31F120M and X-HPV-KV31F120M boards to 
    prevent loss of information in execute only parts of FLASH memory

MSD - DEBUG version 1.15
  - Includes a soft reset fix for FRDM-K20D50M board, which would lead to MSD 
    FLASH programming issue.

MSD - DEBUG version 1.14

  - Added combined MSD, DEBUG and CDC virtual serial support in a single APP.
    Switching between MSD and DEBUG apps is no longer necessary

  - Added Windows 8.1 support. 

MSD version 1.12 

  - added Linux and MAC support

MSD Version 1.09 and DEBUG Version 1.06

  - Fixed virtual serial 8 bits with parity and 7 bits with parity cases.
  - Chanded RESET_B configuration to minimize current draw

MSD Version 1.08

  - Added a pullup to the RXD line of vertual serial port

MSD Version 1.07

  - Improved initial communications to the target MCU to address cases where
    the reset line is disabled or the low power boot mode is used. This may
    previously have resulted in inability to reprogram the target MCU. 

MSD Version 1.06

  - Support added for Linux Operating System (Tested on Ubuntu)

MSD Version 1.05
  - Reset and Run after programming was fixed for secure devices
  - If an illegal file was dropped to it, the LEDs wouldn't blink an error, device would stop working.
  - Protected against programming the FSEC in a way which permanently secures the device

All files in this archive are (C)opyright 2012, P&E Microcomputer Systems. All rights reserved.

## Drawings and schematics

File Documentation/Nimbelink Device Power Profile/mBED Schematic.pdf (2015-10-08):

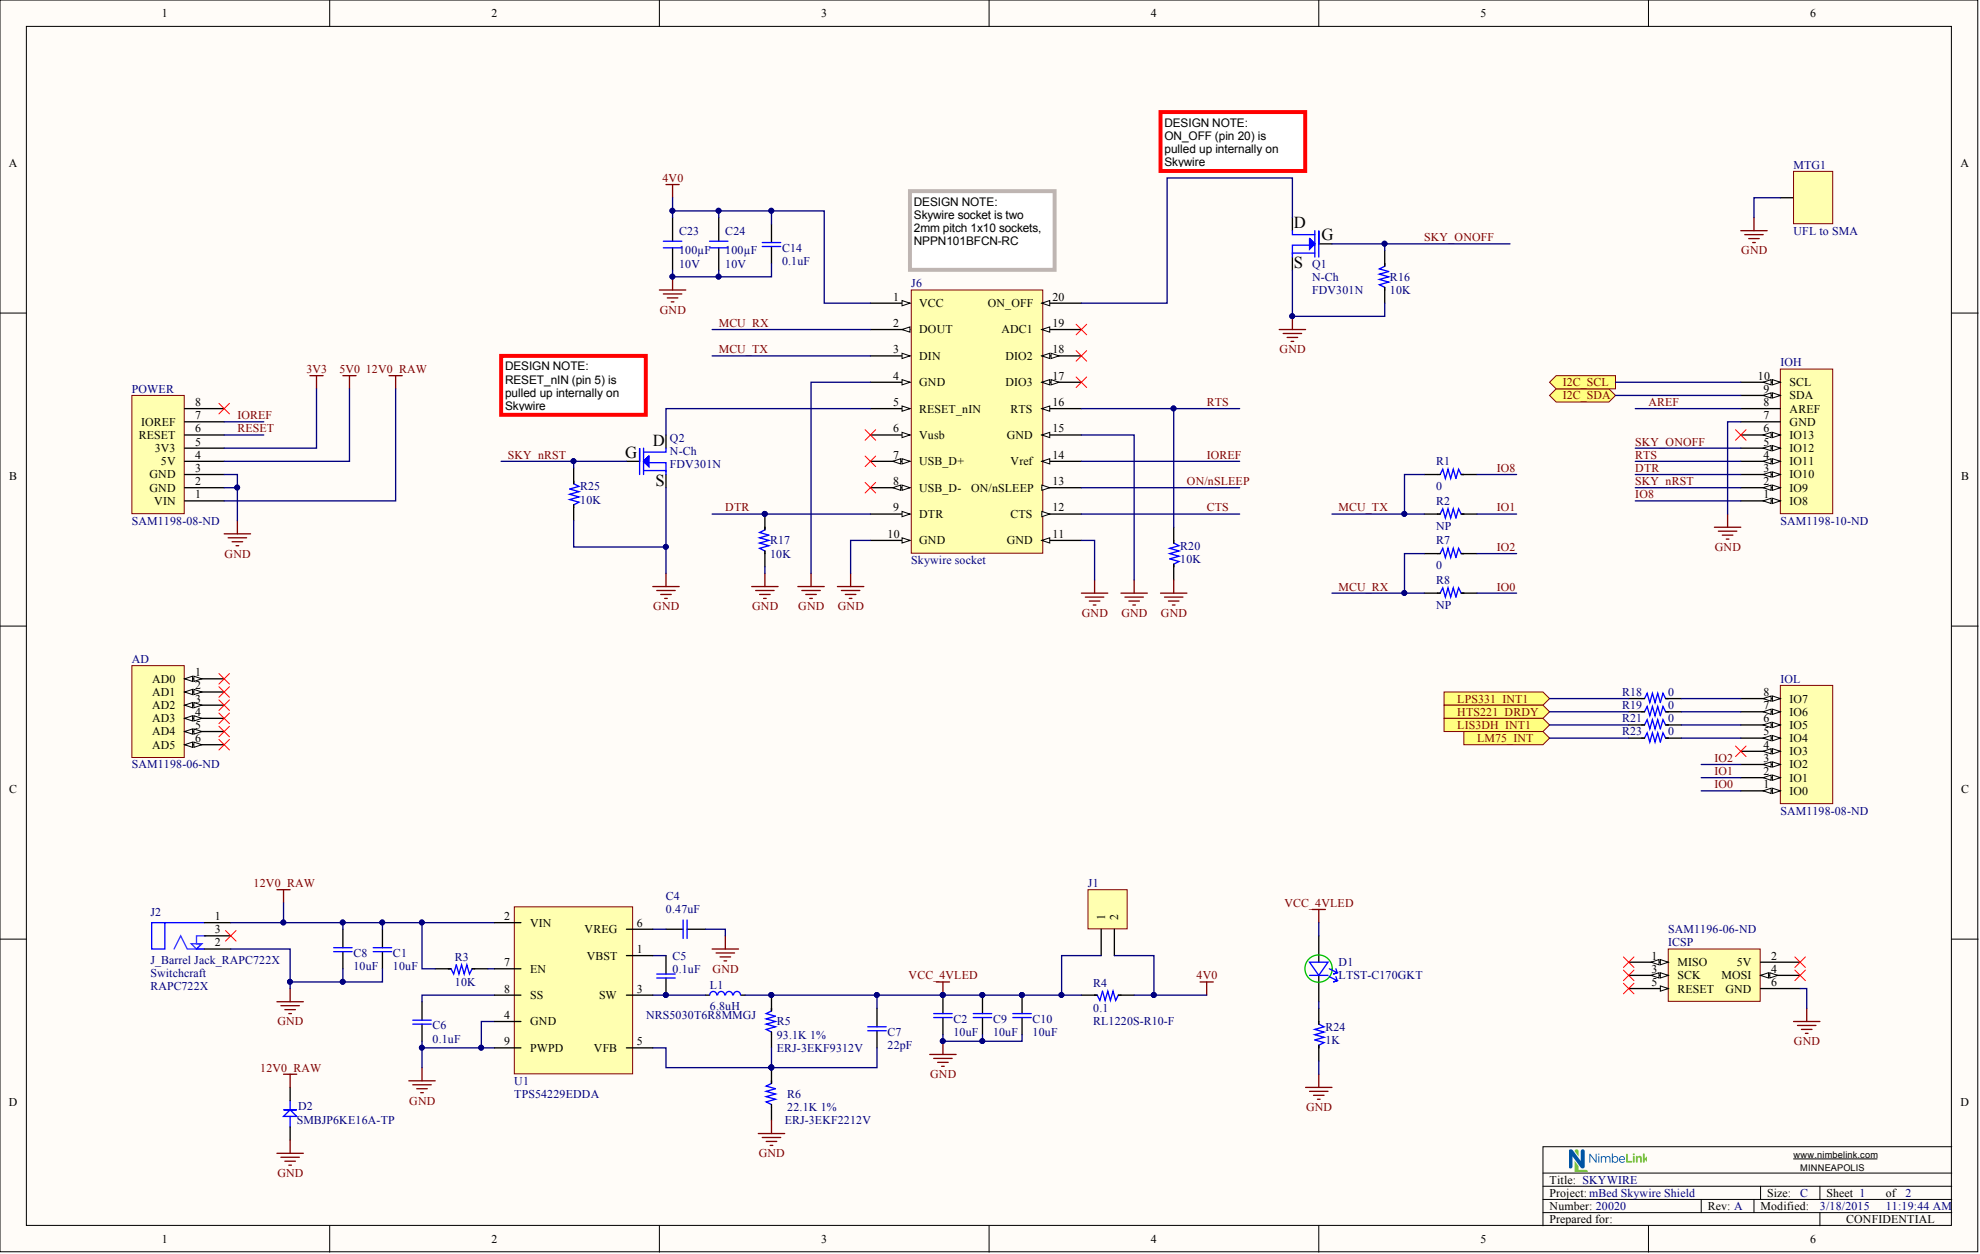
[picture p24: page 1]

DESIGN NOTE:
ON_OFF (pin 20) is
pulled up internally on
Skywire

Skywire socket is two
2mm pitch 1x10 sockets,

RESET_nIN (pin 5) is

Project: mBed Skywire Shield | Size: C | Sheet 1 of 2
Number: 20020 | Rev: A | Modified: 3/18/2015 11:19:44 AM
Prepared for: | CONFIDENTIAL

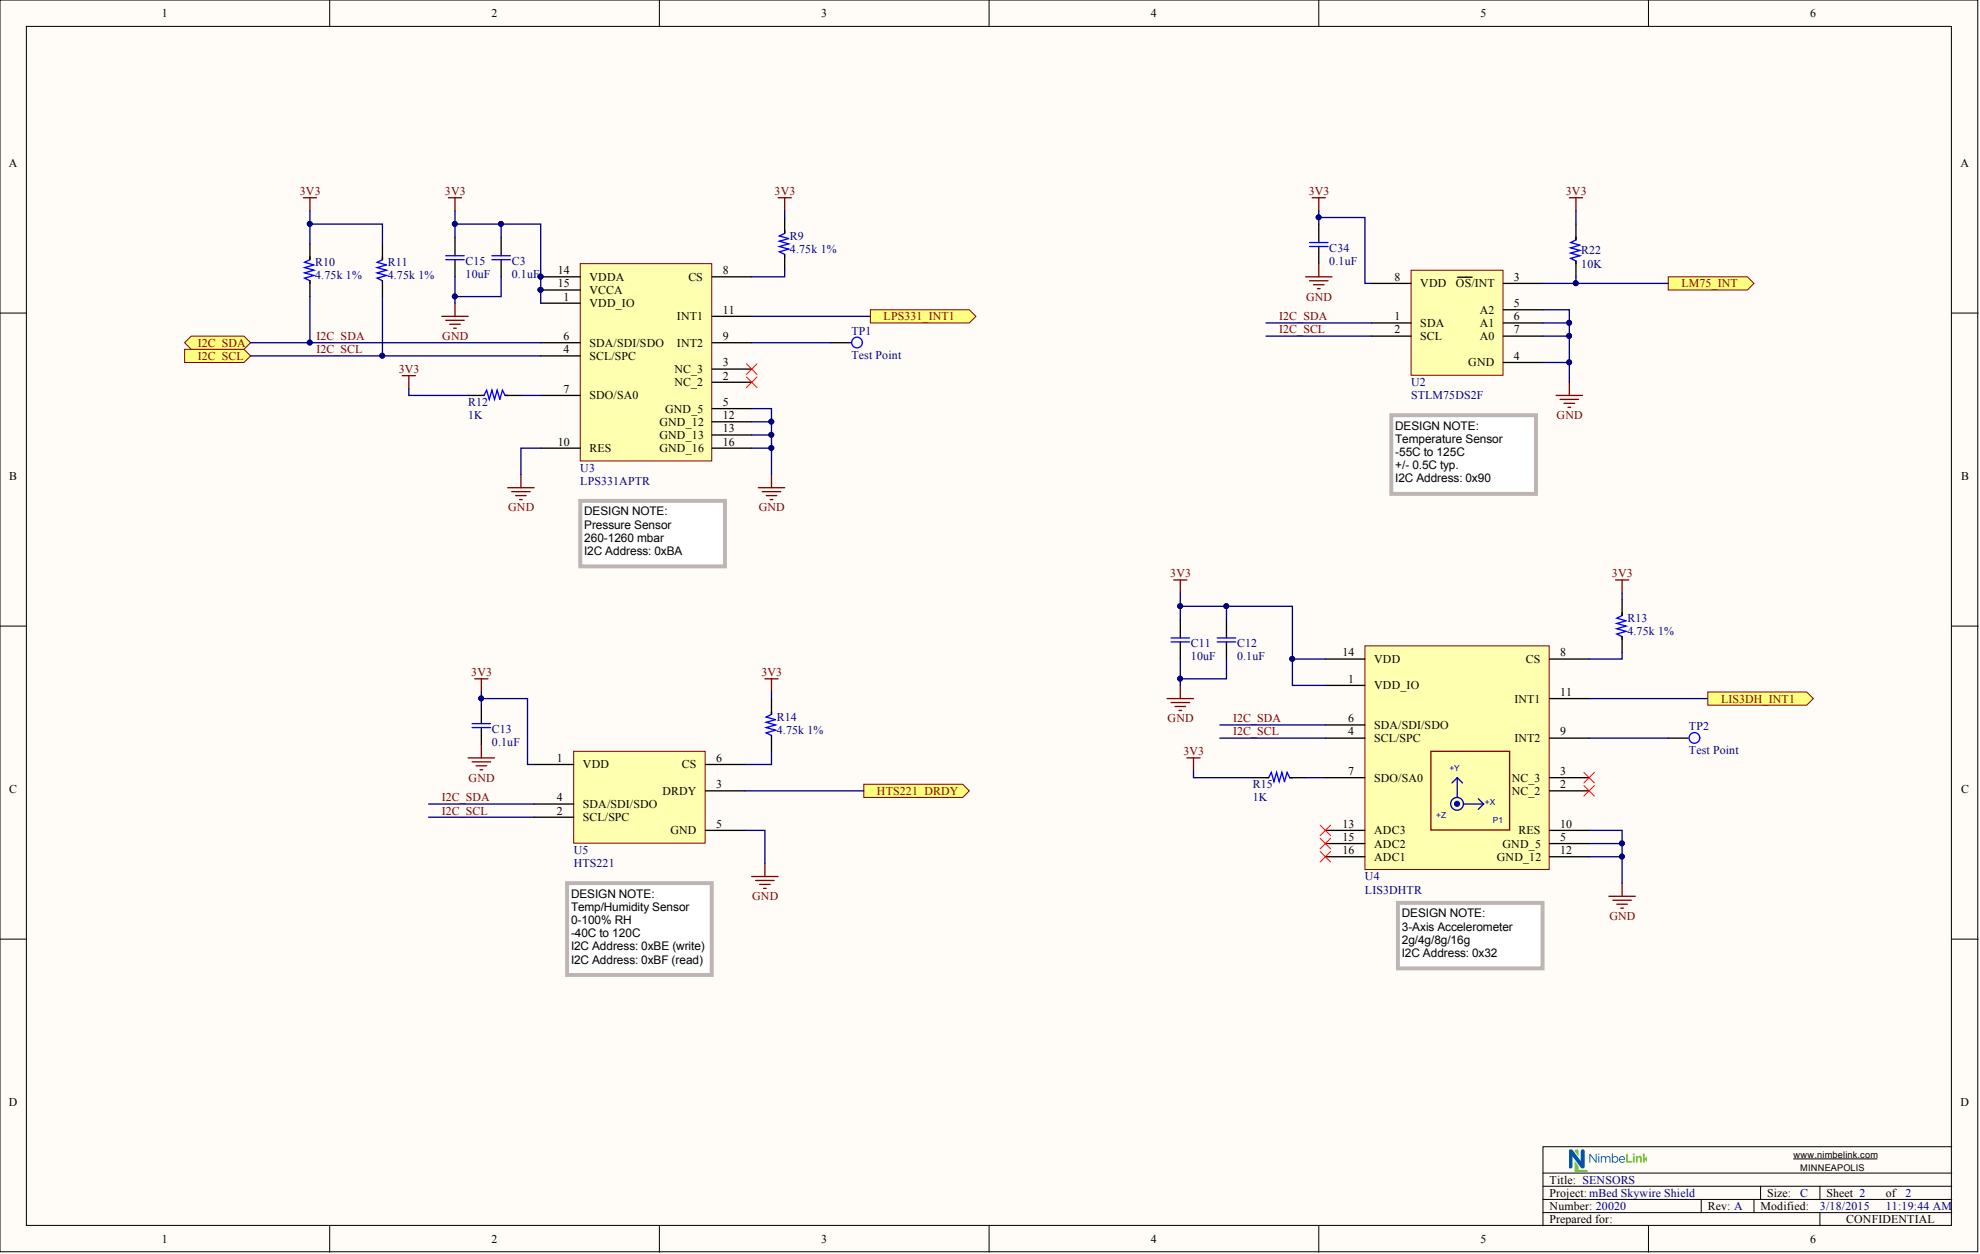
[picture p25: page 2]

Project: mBed Skywire Shield | Size: C | Sheet 2 of 2
Number: 20020 | Rev: A | Modified: 3/18/2015 11:19:44 AM
Prepared for: | CONFIDENTIAL

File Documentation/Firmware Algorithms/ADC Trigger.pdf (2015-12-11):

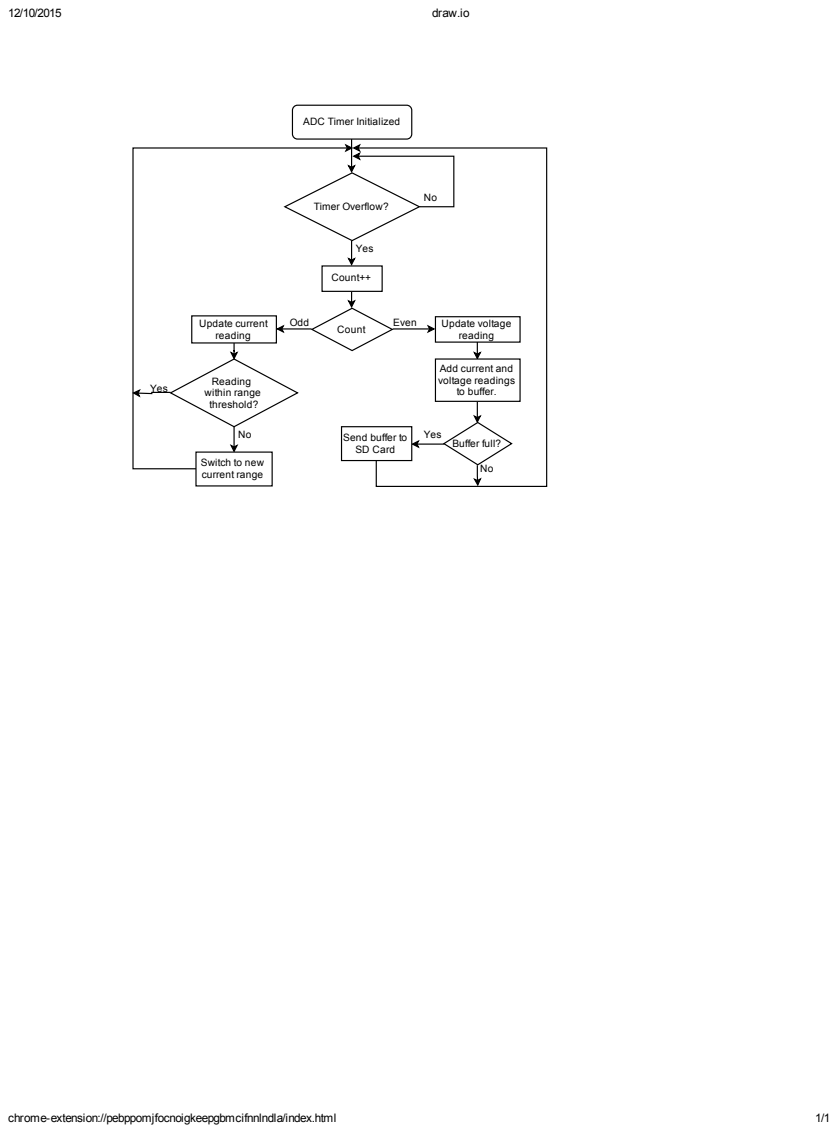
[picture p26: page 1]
draw.io; chromeextension://pebppomjfocnoigkeepgbmcifnnlndla/index.html; Timer Overflow?; Yes; Count++; Count; Odd; Even; Update voltage; reading; Update current reading; Reading within range threshold?; Buffer full?

ADC Timer Initialized

Add current and
voltage readings
to buffer.

Send buffer to
SD Card

Switch to new
current range

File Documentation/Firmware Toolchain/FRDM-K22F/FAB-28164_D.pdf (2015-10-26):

## RE-SPIN PER ECO50297 CHANGE AUDIO JACK W/MIC

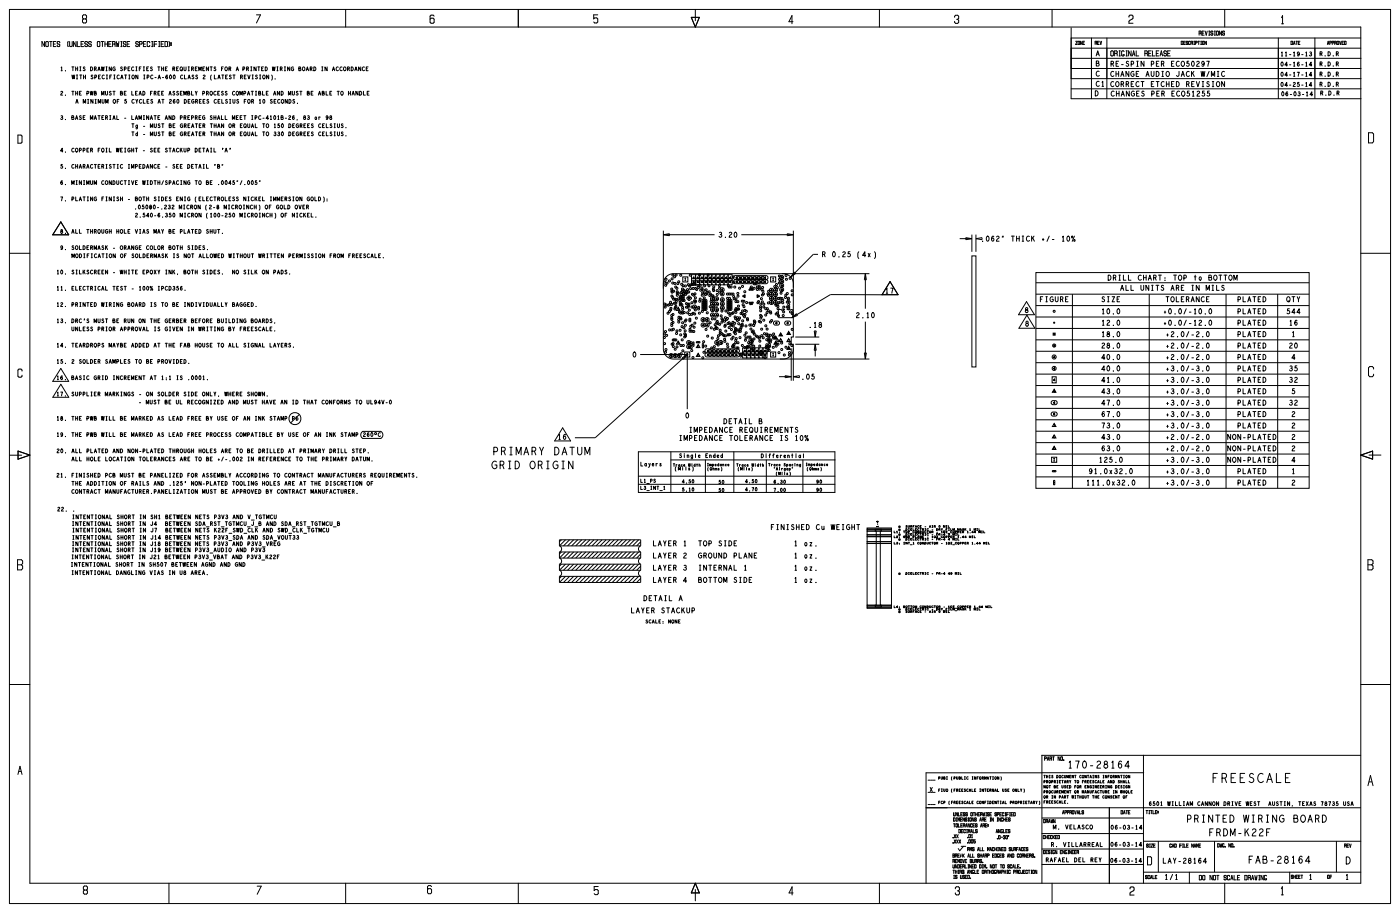
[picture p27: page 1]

1. THIS DRAWING SPECIFIES THE REQUIREMENTS FOR A
WITH SPECIFICATION IPC-A-600 CLASS 2 (LATEST REVISION).
2. THE PWB MUST BE LEAD FREE ASSEMBLY PROCESS COMPATIBLE AND MUST BE ABLE TO HANDLE
A MINIMUM OF 5 CYCLES AT 260 DEGREES CELSIUS FOR 10 SECONDS.
3. BASE MATERIAL - LAMINATE AND PREPREG SHALL MEET IPC-4101B-26, 83 or 98

PRINTED WIRING BOARD IN ACCORDANCE

Tg - MUST BE GREATER THAN OR EQUAL TO 150 DEGREES CELSIUS.
Td - MUST BE GREATER THAN OR EQUAL TO 330 DEGREES CELSIUS.

4. COPPER FOIL WEIGHT - SEE STACKUP DETAIL 'A'
5. CHARACTERISTIC IMPEDANCE - SEE DETAIL "B"
6. MINIMUM CONDUCTIVE WIDTH/SPACING TO BE .0045"/.005"
7. PLATING FINISH - BOTH SIDES ENIG (ELECTROLESS NICKEL IMMERSION GOLD):

.05080-.232 MICRON (2-8 MICROINCH) OF GOLD OVER
2.540-6.350 MICRON (100-250 MICROINCH) OF NICKEL.

8. ALL THROUGH HOLE VIAS MAY BE PLATED SHUT.
9. SOLDERMASK - ORANGE COLOR BOTH SIDES.
MODIFICATION OF SOLDERMASK IS NOT ALLOWED WITHOUT WRITTEN PERMISSION FROM FREESCALE.
10. SILKSCREEN - WHITE EPOXY INK, BOTH SIDES. NO SILK ON PADS.
11. ELECTRICAL TEST - 100% IPCD356.
12. PRINTED WIRING BOARD IS TO BE INDIVIDUALLY BAGGED.
13. DRC'S MUST BE RUN ON THE GERBER BEFORE BUILDING BOARDS,
UNLESS PRIOR APPROVAL IS GIVEN IN WRITING BY FREESCALE.
14. TEARDROPS MAYBE ADDED AT THE FAB HOUSE TO ALL SIGNAL LAYERS.
15. 2 SOLDER SAMPLES TO BE PROVIDED.
16. BASIC GRID INCREMENT AT 1:1 IS .0001.
17. SUPPLIER MARKINGS - ON SOLDER SIDE ONLY, WHERE SHOWN.

- MUST BE UL RECOGNIZED AND MUST HAVE AN ID THAT CONFORMS TO UL94V-0

18. THE PWB WILL BE MARKED AS LEAD FREE BY USE OF AN INK STAMP Pb
19. THE PWB WILL BE MARKED AS LEAD FREE PROCESS COMPATIBLE BY USE OF AN INK STAMP 260 C
20. ALL PLATED AND NON-PLATED THROUGH HOLES ARE TO BE DRILLED AT PRIMARY DRILL STEP.
ALL HOLE LOCATION TOLERANCES ARE TO BE +/-.002 IN REFERENCE TO THE PRIMARY DATUM.
21. FINISHED PCB MUST BE PANELIZED FOR ASSEMBLY ACCORDING TO CONTRACT MANUFACTURERS REQUIREMENTS.
THE ADDITION OF RAILS AND .125' NON-PLATED TOOLING HOLES ARE AT THE DISCRETION OF
CONTRACT MANUFACTURER.PANELIZATION MUST BE APPROVED BY CONTRACT MANUFACTURER.
INTENTIONAL SHORT IN SH1 BETWEEN NETS P3V3 AND V_TGTMCU
INTENTIONAL SHORT IN J4 BETWEEN SDA_RST_TGTMCU_J_B AND SDA_RST_TGTMCU_B
INTENTIONAL SHORT IN J7 BETWEEN NETS K22F_SWD_CLK AND SWD_CLK_TGTMCU
INTENTIONAL SHORT IN J14 BETWEEN NETS P3V3_SDA AND SDA_VOUT33
INTENTIONAL SHORT IN J18 BETWEEN NETS P3V3 AND P3V3_VREG
INTENTIONAL SHORT IN J19 BETWEEN P3V3_AUDIO AND P3V3
INTENTIONAL SHORT IN J21 BETWEEN P3V3_VBAT AND P3V3_K22F
INTENTIONAL SHORT IN SH507 BETWEEN AGND AND GND
INTENTIONAL DANGLING VIAS IN U8 AREA.

Layers | Single Ended

(Mils) | | (Ohms) | | (Mils) | | "Airgap" (Mils) | (Ohms)

PRINTED WIRING BOARD FRDM-K22F

M. VELASCO | 06-03-14
R. VILLARREAL | 06-03-14
RAFAEL DEL REY | 06-03-14

LAY-28164 | FAB-28164 | D

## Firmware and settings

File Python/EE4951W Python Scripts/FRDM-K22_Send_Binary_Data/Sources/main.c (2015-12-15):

/*
 * Copyright (c) 2015, Freescale Semiconductor, Inc.
 * All rights reserved.
 *
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
 * o Neither the name of Freescale Semiconductor, Inc. nor the names of its
 *   contributors may be used to endorse or promote products derived from this
 *   software without specific prior written permission.
 *
 * THIS SOFTWARE IS PROVIDED BY THE COPYRIGHT HOLDERS AND CONTRIBUTORS "AS IS" AND
 * ANY EXPRESS OR IMPLIED WARRANTIES, INCLUDING, BUT NOT LIMITED TO, THE IMPLIED
 * WARRANTIES OF MERCHANTABILITY AND FITNESS FOR A PARTICULAR PURPOSE ARE
 * DISCLAIMED. IN NO EVENT SHALL THE COPYRIGHT HOLDER OR CONTRIBUTORS BE LIABLE FOR
 * ANY DIRECT, INDIRECT, INCIDENTAL, SPECIAL, EXEMPLARY, OR CONSEQUENTIAL DAMAGES
 * (INCLUDING, BUT NOT LIMITED TO, PROCUREMENT OF SUBSTITUTE GOODS OR SERVICES;
 * LOSS OF USE, DATA, OR PROFITS; OR BUSINESS INTERRUPTION) HOWEVER CAUSED AND ON
 * ANY THEORY OF LIABILITY, WHETHER IN CONTRACT, STRICT LIABILITY, OR TORT
 * (INCLUDING NEGLIGENCE OR OTHERWISE) ARISING IN ANY WAY OUT OF THE USE OF THIS
 * SOFTWARE, EVEN IF ADVISED OF THE POSSIBILITY OF SUCH DAMAGE.
 */

/* This is an example program.*/

#include "fsl_device_registers.h"
#include "board.h"
#include "pin_mux.h"
#include "fsl_clock_manager.h"
#include "fsl_debug_console.h"
#include <stdio.h>
#include <math.h>

#define GPIO_INTERRUPT	1	//Set value to 1 for interrupt, 0 for polling
#define PERIOD  0.005	//Define the period of all data transmissions
unsigned int send_data = 0;
unsigned int send_binary = 0;
unsigned int print_val = 0;
unsigned int binary_val = 0x00;

int main(void)
{

    /* enable clock for PORTs */
	CLOCK_SYS_EnablePortClock(PORTA_IDX);
	CLOCK_SYS_EnablePortClock(PORTB_IDX);
	CLOCK_SYS_EnablePortClock(PORTC_IDX);
	CLOCK_SYS_EnablePortClock(PORTE_IDX);

    /* Init board clock */
    BOARD_ClockInit();
    dbg_uart_init();

    //printf("\nHello World! \r\n");
    //printf("\nPress SW2 to Toggle LED. \r\n");
    //printf("\nPress SW3 to send a block of data. \r\n");

#if GPIO_INTERRUPT
    // Configure pin (sw1) interrupt if GPIO_INTERRUPT is set
    switchPins[0].config.interrupt = kPortIntFallingEdge;
#endif
    // Initializes GPIO driver
    GPIO_DRV_Init(switchPins, ledPins);

    while(1)
    {
    	if (send_data == 1)
    	{
    		PrintData(binary_val);
			binary_val = binary_val + 1;
    	}


    	// Poll (sw2) if GPIO_INTERRUPT is not set
    	    	if(GPIO_DRV_ReadPinInput(kGpioSW2) == 0)
    	    	{
    	    		GPIO_SW_DELAY;
    	    		GPIO_DRV_TogglePinOutput(BOARD_GPIO_LED_BLUE);
    	    	}
		// Poll (sw3) if GPIO_INTERRUPT is not set
				if(GPIO_DRV_ReadPinInput(kGpioSW3) == 0)
				{
					GPIO_SW_DELAY;
					GPIO_DRV_TogglePinOutput(BOARD_GPIO_LED_RED);
					send_data = 1 - send_data;
					//printf ("%08d\r\n",print_val);
					//PrintData(print_val);
					//print_val = print_val + 1;
				}
    }
    /* Never leave main */
    return 0;
}

#if GPIO_INTERRUPT
// Define PORTC_IRQHandler (sw2) if GPIO_INTERRUPT is set
void PORTC_IRQHandler()
{
	if(GPIO_DRV_ReadPinInput(kGpioSW2) == 0)
		{
			GPIO_DRV_ClearPinIntFlag (kGpioSW2); // Clear IRQ flag
			GPIO_DRV_TogglePinOutput(BOARD_GPIO_LED_BLUE); // Toggle blue LED
			GPIO_SW_DELAY;
		}

	if(GPIO_DRV_ReadPinInput(kGpioSW3) == 0)
		{
			GPIO_DRV_ClearPinIntFlag (kGpioSW3); // Clear IRQ flag
			GPIO_DRV_TogglePinOutput(BOARD_GPIO_LED_RED); // Toggle blue LED
			GPIO_SW_DELAY;
			//printf ("%08d\r\n",print_val);
			//PrintData(print_val);
			//print_val = print_val + 1;
			//send_data = 1 - send_data;
			//send_binary = 1 - send_binary;
		}
}
#endif

int PrintData(unsigned int timeval)
{
	// This function will print out a chunk of data for each category
	// Here we are assuming that all values are slowly increasing.

	//Initial values
	unsigned int mean_V = 0x2CB41780;
	unsigned int mean_I = 0x004C4B40;
	unsigned int start_TS = 0x000000;

	//Introduce fluctuations
	unsigned int V_val,I_val,TS_val;
	V_val = mean_V + 0x500000 * sin(PERIOD*timeval);
	I_val = mean_I + 0x500000 * sin(PERIOD*timeval);
	TS_val = start_TS + timeval;

	unsigned int voltage[4];
	unsigned int current[4];
	unsigned int time_stamp[3];

	voltage[0] = V_val / 0x1000000;	//MSB
	V_val = V_val - (0x1000000 * voltage[0]);
	voltage[1] = V_val / 0x10000;
	V_val = V_val - (0x10000 * voltage[1]);
	voltage[2] = V_val / 0x100;
	V_val = V_val - (0x100 * voltage[2]);
	voltage[3] = V_val;

	current[0] = I_val / 0x1000000;	//MSB
	I_val = I_val - (0x1000000 * current[0]);
	current[1] = I_val / 0x10000;
	I_val = I_val - (0x10000 * current[1]);
	current[2] = I_val / 0x100;
	I_val = I_val - (0x100 * current[2]);
	current[3] = I_val;

	time_stamp[0] = TS_val / 0x10000;	//MSB
	TS_val = TS_val - (0x10000 * time_stamp[0]);
	time_stamp[1] = TS_val / 0x100;
	TS_val = TS_val - (0x100 * time_stamp[1]);
	time_stamp[2] = TS_val;

	fputc(voltage[3],stdout);
	fputc(voltage[2],stdout);
	fputc(voltage[1],stdout);
	fputc(voltage[0],stdout);
	fputc(current[0],stdout);
	fputc(current[1],stdout);
	fputc(current[2],stdout);
	fputc(current[3],stdout);
	fputc(time_stamp[0],stdout);
	fputc(time_stamp[1],stdout);
	fputc(time_stamp[2],stdout);

	unsigned int temp = 0;
	for (int i=0;i<11;i++)
	{
		if (i < 4)
		{
			temp = temp ^ (voltage[i]);
		}
		else if (i < 8)
			{
				temp = temp ^ (current[i-4]);
			}
			else
			{
				temp = temp ^ (time_stamp[i-8]);
			}
	}
	fputc(temp,stdout);	//This is the check_sum

	temp = 0;
	for (int i=0;i<11;i++)
	{
		if (i < 4)
		{
			temp = temp + (voltage[i]);
		}
		else if (i < 8)
			{
				temp = temp + (current[i-4]);
			}
			else
			{
				temp = temp + (time_stamp[i-8]);
			}
	}
	temp = temp % 256;	//Take the least significant byte
	temp = temp ^ 255;	//Flip the sign of each bit
	temp = temp + 1;	//This is the twos_complement
	fputc(temp,stdout);

	fflush(stdout);

	return 0;
}
////////////////////////////////////////////////////////////////////////////////
// EOF
////////////////////////////////////////////////////////////////////////////////

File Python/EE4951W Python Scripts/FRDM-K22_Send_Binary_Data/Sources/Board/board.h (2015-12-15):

/*
 * Copyright (c) 2014, Freescale Semiconductor, Inc.
 * All rights reserved.
 *
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
 * o Neither the name of Freescale Semiconductor, Inc. nor the names of its
 *   contributors may be used to endorse or promote products derived from this
 *   software without specific prior written permission.
 *
 * THIS SOFTWARE IS PROVIDED BY THE COPYRIGHT HOLDERS AND CONTRIBUTORS "AS IS" AND
 * ANY EXPRESS OR IMPLIED WARRANTIES, INCLUDING, BUT NOT LIMITED TO, THE IMPLIED
 * WARRANTIES OF MERCHANTABILITY AND FITNESS FOR A PARTICULAR PURPOSE ARE
 * DISCLAIMED. IN NO EVENT SHALL THE COPYRIGHT HOLDER OR CONTRIBUTORS BE LIABLE FOR
 * ANY DIRECT, INDIRECT, INCIDENTAL, SPECIAL, EXEMPLARY, OR CONSEQUENTIAL DAMAGES
 * (INCLUDING, BUT NOT LIMITED TO, PROCUREMENT OF SUBSTITUTE GOODS OR SERVICES;
 * LOSS OF USE, DATA, OR PROFITS; OR BUSINESS INTERRUPTION) HOWEVER CAUSED AND ON
 * ANY THEORY OF LIABILITY, WHETHER IN CONTRACT, STRICT LIABILITY, OR TORT
 * (INCLUDING NEGLIGENCE OR OTHERWISE) ARISING IN ANY WAY OUT OF THE USE OF THIS
 * SOFTWARE, EVEN IF ADVISED OF THE POSSIBILITY OF SUCH DAMAGE.
 */

#if !defined(__BOARD_H__)
#define __BOARD_H__

#include <stdint.h>
#include "pin_mux.h"
#include "gpio_pins.h"

/* This section of code was added by James Redinger on 11/25/2015 */
#define GPIO_SW_DELAY \
	do \
	{ \
		int32_t i; \
		for (i = 0; i < 0x1FFFFF; i++) \
		{ \
			__asm("nop"); \
		} \
	} while(0)
/* End of code added by James Redinger. */

/* The board name */
#define BOARD_NAME                      "FRDM-K22F"

#define CLOCK_VLPR   1U
#define CLOCK_RUN    2U
#define CLOCK_HSRUN  3U
#define CLOCK_NUMBER_OF_CONFIGURATIONS 4U

#ifndef CLOCK_INIT_CONFIG
#define CLOCK_INIT_CONFIG CLOCK_HSRUN
#endif

#if (CLOCK_INIT_CONFIG == CLOCK_RUN)
#define CORE_CLOCK_FREQ 80000000U
#elif (CLOCK_INIT_CONFIG == CLOCK_HSRUN)
#define CORE_CLOCK_FREQ 120000000U
#else
#define CORE_CLOCK_FREQ 4000000U
#endif

/* OSC0 configuration. */
#define OSC0_XTAL_FREQ 8000000U
#define OSC0_SC2P_ENABLE_CONFIG  false
#define OSC0_SC4P_ENABLE_CONFIG  false
#define OSC0_SC8P_ENABLE_CONFIG  false
#define OSC0_SC16P_ENABLE_CONFIG false
#define MCG_HGO0   kOscGainLow
#define MCG_RANGE0 kOscRangeVeryHigh
#define MCG_EREFS0 kOscSrcOsc

/* EXTAL0 PTA18 */
#define EXTAL0_PORT   PORTA
#define EXTAL0_PIN    18
#define EXTAL0_PINMUX kPortPinDisabled

/* XTAL0 PTA19 */
#define XTAL0_PORT   PORTA
#define XTAL0_PIN    19
#define XTAL0_PINMUX kPortPinDisabled

/* RTC external clock configuration. */
#define RTC_XTAL_FREQ   32768U
#define RTC_SC2P_ENABLE_CONFIG       false
#define RTC_SC4P_ENABLE_CONFIG       false
#define RTC_SC8P_ENABLE_CONFIG       false
#define RTC_SC16P_ENABLE_CONFIG      false
#define RTC_OSC_ENABLE_CONFIG        true

#define BOARD_RTC_CLK_FREQUENCY     32768U;

/* The UART to use for debug messages. */
#ifndef BOARD_DEBUG_UART_INSTANCE
    #define BOARD_DEBUG_UART_INSTANCE   1
    #define BOARD_DEBUG_UART_BASEADDR   UART1
#endif
#ifndef BOARD_DEBUG_UART_BAUD
    #define BOARD_DEBUG_UART_BAUD       230400
#endif

/* This define to use for power manager demo */
#define BOARD_LOW_POWER_UART_BAUD       9600

#define BOARD_USE_UART

#define PM_DBG_UART_IRQ_HANDLER         UART1_RX_TX_IRQHandler

#define PM_DBG_UART_IRQn                UART1_RX_TX_IRQn

/* Define the port interrupt number for the board switches */
#define BOARD_SW_GPIO               kGpioSW3
#define BOARD_SW_IRQ_NUM            PORTB_IRQn
#define BOARD_SW_IRQ_HANDLER        PORTB_IRQHandler
#define BOARD_SW_NAME               "SW3"
/* Define feature for the low_power_demo */
#define FSL_FEATURE_HAS_VLLS2 (1)

/* Define print statement to inform user which switch to press for
 * power_manager_hal_demo and power_manager_rtos_demo
 */
#define PRINT_LLWU_SW_NUM \
  PRINTF("SW2")

/* Defines the llwu pin number for board switch which is used in power_manager_demo. */
#define BOARD_SW_HAS_LLWU_PIN        1
#define BOARD_SW_LLWU_EXT_PIN        kLlwuWakeupPin6
/* Switch port base address and IRQ handler name. Used by power_manager_demo */
#define BOARD_SW_LLWU_PIN            1
#define BOARD_SW_LLWU_BASE           PORTC
#define BOARD_SW_LLWU_IRQ_HANDLER    PORTC_IRQHandler
#define BOARD_SW_LLWU_IRQ_NUM        PORTC_IRQn

#define BOARD_I2C_GPIO_SCL              GPIO_MAKE_PIN(GPIOB_IDX, 2)
#define BOARD_I2C_GPIO_SDA              GPIO_MAKE_PIN(GPIOB_IDX, 3)

#define HWADC_INSTANCE               1
#define ADC_IRQ_N                    ADC1_IRQn

/* The instances of peripherals used for dac_adc_demo */
#define BOARD_DAC_DEMO_DAC_INSTANCE     0U
#define BOARD_DAC_DEMO_ADC_INSTANCE     0U
#define BOARD_DAC_DEMO_ADC_CHANNEL      8U

/* The i2c instance used for i2c DAC demo */
#define BOARD_DAC_I2C_INSTANCE          0

/* The i2c instance used for i2c connection by default */
#define BOARD_I2C_INSTANCE              0

/* The dspi instance used for dspi example */
#define BOARD_DSPI_INSTANCE             0
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

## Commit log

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2015-09-12 Gantt Chart
    Added a Gantt Chart with a projected Timeline
    [EE4951_Timeline.xlsx]
2015-09-15 Added Shunt Data
    Added some data and tables about resistive current shunts.
    [EE4951_Timeline.xlsx, Resistive Shunt Parameters.xlsx]
2015-09-15 Update
    Updated Timeline and Shunt Data
    [EE4951_Timeline.xlsx, Resistive Shunt Parameters.xlsx]
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2015-09-22 Updated Shunt Params
    [EE4951_Timeline.xlsx, Resistive Shunt Parameters.xlsx]
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2015-09-22 Added subsystem constraints
    [Resistive Shunt Parameters.xlsx]
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2015-09-23 Added Budget and Datasheets
    [Budget 9-22-15.xlsx]
2015-09-23 Added Programmer to Budget
    [Budget 9-22-15.xlsx]
2015-09-23 Updated Budget: Power Subsection
    [Budget 9-22-15.xlsx]
2015-09-23 LCD cost added
    [Budget 9-22-15.xlsx]
2015-09-23 SD card cost added
    [Budget 9-22-15.xlsx]
2015-09-23 Design Specifications and Budget updated
    Modified Design Specifications to be submitted September 23
    [Budget 9-22-15.xlsx]
2015-09-23 Design specifications, individual roles and description of demonstration added
    [Budget 9-22-15.xlsx, EE4951_Timeline.xlsx]
2015-09-24 Modified Budget
    [Budget 9-22-15.xlsx]
2015-09-24 Added PCBA Project
    ...and some datasheets
    [Current Measurement.SchDoc, EE4951_BPM_REV_A.PrjPcb]
2015-09-24 Changed filenames to be consistent
    [Power-Monitoring Device - Budget.xlsx, Power-Monitoring Device - Timeline.xlsx]
2015-09-25 Added Altium Project
    [Connectors.SchDoc, Current Measurement.SchDoc, EE4951_BPM_REVA.PcbDoc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]
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2015-10-07 Updated Power Subsystem
    Added schematics, BOMs, and simulations for improved power subsystem
    designs.
    [Bill of Materials Buck_Boost.xlsx, Bill of Materials Buck_and_Boost.xlsx]
2015-10-08 Updated PCBA and Low Level Firmware
    [Connectors.SchDoc, Current Measurement.SchDoc, EE4951_BPM_REV_A.PrjPcb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]
2015-10-08 Added Altium Library in PCBA
    [12067 Hinge.STEP, 1x2 Header.stp, 1x3 Header.stp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]
2015-10-09 Began PCB Component Placement
    [Connectors.SchDoc, Current Measurement.SchDoc, EE4951_BPM_REVA.PcbDoc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]
2015-10-10 Power Subsystem Altium Schematic
    James Redinger added the power subsystem to Altium.
    [Capacitors.SchLib, Connectors.SchLib, Diodes.SchLib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]
2015-10-12 Updated Switching Section of Power Subsystem
    [Power.SchDoc, Voltage Measurement.SchDoc]
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2015-10-12 Updated Library and Power System
    [Capacitors.SchLib, Inductors.SchLib, Miscellaneous Silicon.SchLib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]
2015-10-12 OLED PCB Updates
    Added schematic for OLED display. Created PCB componenet (including 3D
    model) with standoffs.
    [LCD Display.SchDoc, OLED-PCB.PcbLib]
2015-10-13 Added OLED Display Sheet
    [Heirarchy.SchDoc, LCD Display.SchDoc, OLED Display.SchDoc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]
2015-10-13 Updated Power System with New Boost Converter
    There was no feasible way to make the old boost converter work.
    [Capacitors.SchLib, Connectors.SchDoc, Current Measurement.SchDoc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]
2015-10-13 Working on OLED schematic
    [LCD Display.SchDoc]
2015-10-13 Working on OLED schematic-2
    [Miscellaneous.SchLib]
2015-10-13 Reverted and re-comitting due to merging errors
    [SC 70-8.step]
2015-10-13 Cleaned PCBA Folder
    Do not create new libraries. Create components in the master library.
    [LCD Display.SchDoc, SSD1306.SchLib, Self Power Monitor.SchDoc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]
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2015-10-13 Cleaned Files in Altium Library
    [Miscellaneous.SchLib]
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2015-10-13 Working on OLED footprint
    [Miscellaneous.SchLib]
2015-10-13 Added Self Vsense Circuitry
    [Capacitors.SchLib, OpAmps.SchLib, Power.SchDoc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]
2015-10-14 OLED Display library and schematic
    [EE4951_BPM_REV_A.PrjPcb, Heirarchy.SchDoc, Miscellaneous Silicon.SchLib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]
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2015-10-14 Removed History Directories and added .gitignore file
    [12067 Hinge.STEP, 1x2 Header.stp, 1x3 Header.stp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]
2015-10-14 Added Self Current Monitoring and OLED
    [Heirarchy.SchDoc, Microcontroller.SchDoc, Miscellaneous Silicon.SchLib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]
2015-10-15 Updated PCBA
    Added Power Failure warning
    [Current Measurement.SchDoc, Heirarchy.SchDoc, Microcontroller.SchDoc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]
2015-10-17 Continued Layout
    Added testpoints and net ties
    [Microcontroller.SchDoc, Miscellaneous.SchLib, Power.SchDoc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]
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2015-10-19 Finished Schematic and Continued Component Placement
    [Connectors.SchDoc, Connectors.SchLib, Current Measurement.SchDoc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]
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2015-10-22 Added Python script to test ADCs
    [ADC_TEST.csv, Connectors.SchDoc, Current Measurement.SchDoc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]
2015-10-26 Redesigned Current Measurement and Updated Firmware
    [1x2 Header.STEP, Capacitors.SchLib, Connectors.SchDoc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]
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2015-10-29 Finished Routing
    Finished all trace routing. Power planes still not poured.
    [OLED Display.SchDoc]
2015-10-29 Finished Layout and Fabrication Outputs
    [Connectors.SchLib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]
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2015-11-05 Finished Layout with ADCs on Power Layer
    [Current Measurement.SchDoc, EE4951_BPM_REV_A.PrjPcb, Heirarchy.SchDoc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]
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2015-11-05 Finished Layout and Gerbers
    For real this time
    [Current Measurement.SchDoc, EE4951_BPM_REV_A.PrjPcb, Microcontroller.SchDoc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]
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2015-12-02 More Firmware
    Finished DutISense class. Added/tested more peripherals
    [Resistive Shunt Parameters.xlsx]
2015-12-03 Resolved Flextimer run time failures
    Switched from FTM to simple hardware counter
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2015-12-06 Added DutVSense Class
    Also updated ADC switching for current and voltage
    [Power.SchDoc]
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2015-12-10 Updated Firmware
    Quantitative testing on a lot of speed critical functions. Better
    DutISense Crossovers
    [Current Ranges and Crossovers.xlsx]
2015-12-10 Updated Testing Data
    ...and some firmware
    [Current Ranges and Crossovers.xlsx]
2015-12-27 Added rework notes
    Final Update
    [Power.SchDoc]
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
